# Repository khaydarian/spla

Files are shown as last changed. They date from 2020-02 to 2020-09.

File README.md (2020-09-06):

# SPLA: Super Nintendo PPU Logic Analyzer

The 1990-era Super Nintendo Entertainment System is a venerable gaming console,
and although its hardware is aging and hard to come by, it has long had
well-establish software emulators, preserving gaming history for generations to
come.

However, while most of the SNES hardware has been effectively
reverse-engineered by writing test programs for the CPU (sometimes taking
advantage of undocumented behavior to figure out details), one remaining
component of the console has resisted complete analysis: the "Picture
Processing Unit" chips, `PPU-1` and `PPU-2`.

The PPU chips are together responsible for managing the sprites, backgrounds,
and palettes for each frame of a game's video output, and produce the analog
scanline signal in realtime, which then appears on the
player's TV.  However, the output video signals (and video ram bus) are
entirely inaccessible to SNES CPU, thus making analysis of the exact timing
details of these chips difficult or impossible.

A very few games for the SNES (particularly *Air Strike Patrol*) use the SNES
video hardware in unexpected ways, which depend on the detailed timing of the
PPU chips during scanline rendering.  This makes accurately emulating these
games' graphics difficult -- emulator developers have to manually compare
emulator output with what the game actually shows on the screen, and try to
guess how the PPU evaluates these unusual configurations.  Without complete
understanding of the chips operation, this process degenerates into a
frustruating game of whack-a-mole.

To be confident that we have faithfully reproduced the entire SNES, we need to
characterize all the PPU outputs at the level of individual clock cycles, and
rigorously compare the behavior of a software emulator to that of the actual,
physical chips.

This project is intended to design a breakout circuit board, integrating the
SNES PPU chips from a real vintage SNES console, combined with surrounding
modern hardware, to effectively form a >100-pin-wide digital logic analyzer,
combined with single-frame analog video capture system.  With this board built,
and sufficient supporting software written, it should be possible to
experimentally characterize the entire operation of the PPU chips, thus
producing a completely cycle-accurate emulation of the SNES video hardware.

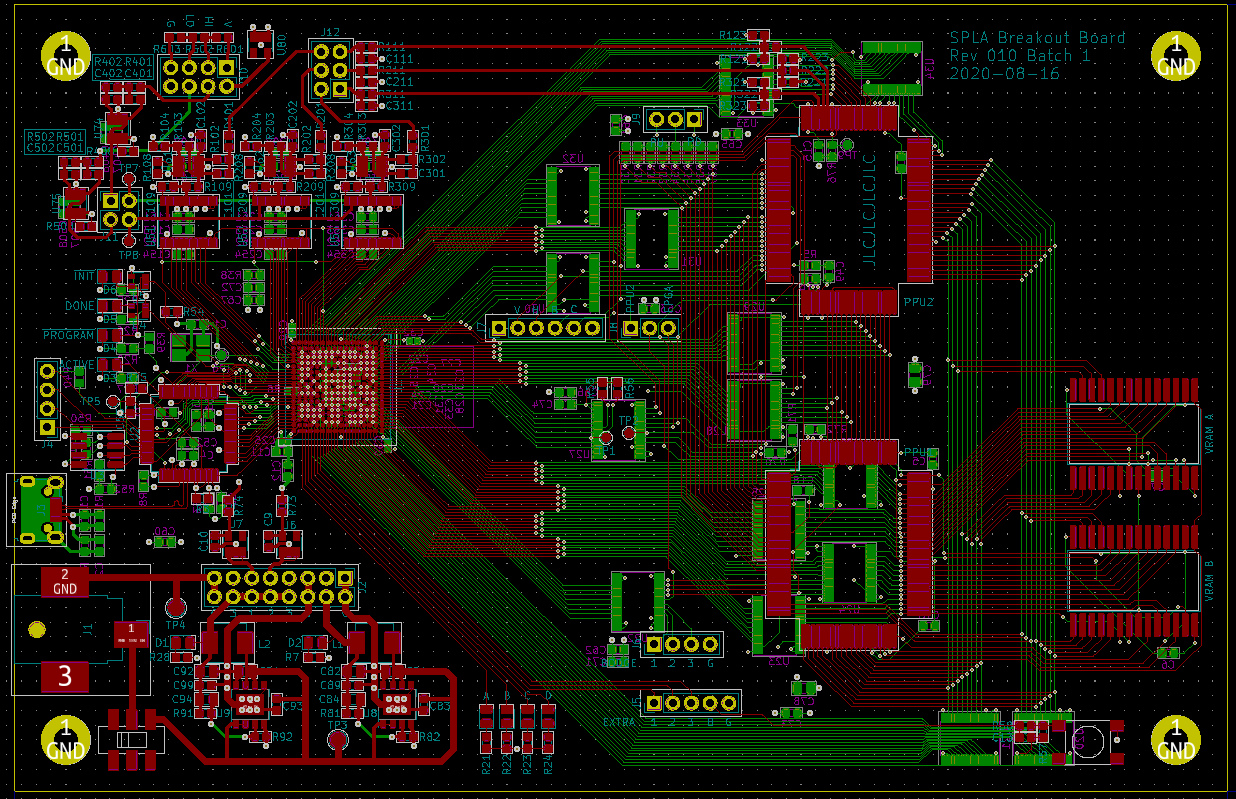
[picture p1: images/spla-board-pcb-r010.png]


## Current Status

* Design complete.
* Schematic complete.
* PCB layout complete.
* Schematic and PCB review complete (enough).
* Lab setup essentially complete.
* Bringup started.
  * Power bringup complete.
  * USB / FTDI bringup complete.
  * FPGA bringup complete.
  * Level shifter bringup complete.
  * SNES bringup complete.
  * Analog bringup pending.
* Software development in progress.
  * Early bringup and testing software complete.
* RTL development in progress.
  * All bringup images complete.
  * Low-speed driver image in progress.
  * High-speed driver image pending.

## Design components

* The USB interface to a host PC is based on an FTDI `FT2232H` chip, which can
  drive up to 60MBps (USB 2.0 "Full Speed" maximum throughput).
* A Lattice `ECP5` FPGA, which forms the central brains of the board.
* Both SNES `PPU` chips, and their corresponding video SRAM chips (which are
  standard 32KiB 8-bit SRAM chips, but are old enough that they're hard to
  source).
* A whole bunch of 3.3V / 5V level shifter chips (`74LVC8T245`), as the SNES
  chips are 5V TTL, but almost everything modern is 3.3V at most.
* Three `ADC1173` high-speed 8-bit analog-to-digital converter chips, to
  capture the analog RGB signal output and convert it back to digital for
  analysis. This also requires a handful (5) of `LMH6611` opamps to drive the
  ADC inputs and establish reliable references.

## References

* [Original post that inspired this project](https://byuu.org/articles/edge-of-emulation)
* [Ars Technica Article](https://arstechnica.com/gaming/2020/04/how-snes-emulators-got-a-few-pixels-from-complete-perfection/)

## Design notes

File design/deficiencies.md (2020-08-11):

# Design Deficiencies

This current design has a number of known (hopefully inconsequential) deficiencies:

## design: USB 2.0 Full Speed Bandwidth

USB 2.0 Full Speed is 480 megabaud, or 60 MiBps at line rate.  Some of this is absorbed by protcol overhead, so I can expect to sustain at most about 40 MiBps average.  The `FT2232H` in async fifo mode can in theory sustain this, depending on the host controller.  Based on some back-of-the-envelope calculations (too crude to repeat here), this is definitely not enough for full data-rate on all the pins, and perahps not even enough for full-frame-rate 24-bit color frames.

I can mitigate this with some clever compression and filtering, and it's probably possible to runthe SNES chips as lower than the rated 27.7727 MHz clock rate.

Another option is to graduate to USB 3.0 with a more complex (and expensive) chip.

I've length-matched the USB traces, but I'm not sure I've done so correctly.

## schematic: Ignored Pins

`PPU1.TST[012]` have unknown purpose, and aren't hooked up at all.

`PPU1.TST{12..15}` probably have more uses than just the 15-bit digital output, which I've ignored.

Most of the `74LVC8T245` level shifters don't have either their `OE` (output-enable) or `DIR` (direction) pins hooked up.  In most cases this doesn't matter, because the pins on the PPU / VRAM chips aren't bidirectional, and it's ok to be driving them all the time.  It's a bit clumsy though.

## schematic: Direction Control Granularity

Since the `74LVC8T245` can only control direction for all 8 channels at once, I've grouped the pins in the hopes that they'll have the same direction.  This is obviously ok for data and address buses, but there's lots of individual signals that I can't drive in separate directions.  Some groups of pins and explicitly one direction, which is a bit wasteful (but at least I only need the one kind of level shifter chip).

## schematic/pcb: Power layout

The power layout is perhaps entirely nonsense and I've no idea if it'll work.  I ought to prototype this on a separate PCB and find out -- perhaps even design one that fits into the power jumper bank I have now.

There's (small) ground loops in the power layout, whch is maybe bad. The PCB layout recommends a "guard trace" which I don't know how to do correctly.

_Note: Power layout definitely works (and in fact did so the first time, with zero issues)._

## schematic/pcb: Analog

The analog block is by far the least competently-developed part of the design.  The entire analog setup (ADCs + opamps) is based on my very limited understanding of analog electronics, so I might have done any number of things wrong and not realized so.  It's possibly fixable by replacing some passives with other values, but there's no guarantee.

The analog traces from the PPU2 outputs are pretty long (5-7cm), which could be problematic.  I don't have a good feel for whether this is so.

The analog power distribution is terrible; it's sourced from the 5V rail that goes all the way around the board, and it's just using a `TLV733` LDO.  This also might do a terrible job of noise rejection from the digital chips (which might come in through the ground plane anyways).  I've put it though a pin header, so in theory I can rework it if needed.

## schematic/pcb: Dodgy Decoupling

I don't know if I've added enough / the right decopling capacitors; I've mostly followed the reference recommendataions.  In particular I've avoided putting in bulk decoupling, because I'm not sure if it's necessary, given the large ground/power plane areas.  I can bodge this in later if needed, but perhaps I should put in a footprint for some big electrolytic capacitors.

Many of the level shifter chips don't have a good place to put decoupling capacitors.  I might have enough bulk decoupling on the board that this isn't a huge problem, and I can add in a few optional ones to help.

_Note: This is probably inconsequential; I've encountered no decoupling issues so far._

## pcb: PPU1 layout

The layout of the level shifters under the PPU1 chip is way tighter than necessary, and could be relaxed without causing issues.

## pcb: Power plane splits

The split between 5V and 3.3V sections of the power plan is ugly, because the level shifter chips are all over the place. Maybe this should be simplified, at the cost of some board space and increased trace stubs on the SNES buses.

## pcb: FPGA power

The power/ground fills have wide areas around vias (which is probably necessary), but this doesn't really leave enough space for all the 1.1V and 2.5V power to get in.  I've added traces for this, but they're often too small (0.2mm or 0.1mm), so I've added extra back-layer traces to supplement this.  This is really a side effect of having a four-layer board layout.

_Note: This is apparently inconsequential; I've encountered no FPGA power issues so far._

## pcb: FPGA Decoupling

The FPGA decoupling is considerably below spec for the 3.3V domain, because I can't fit all the capacitors in properly. This needs either reworking -- or a 6-layer board -- to avoid the extra bottom-layer power traces, which take up all the space for the capacitors pads.

_Note: This is apparently inconsequential; I've encountered no decoupling issues so far._

## pcb: Trace Lengths

Some of the traces are very long -- in particular, the VRAM data buses wrap all the way around the board. I'm not sure if this is a problem or not; the frequency shouldn't be too high.

_Note: This works ok at low speed (16 clocks at 12 MhZ, ~750kHz)._

## pcb: Trace Spacing

For the most part I've tried to avoid spacing traces at the minimum size: 3.5 mil, or slightly less than 0.1mm (I've set the limit at the latter).  There's a handful of places I'm stuck with it, and it's probably fine -- but those buses could couple together and cause signal integrity issues.  Probably that will only limit maximum speed, which shouldn't be a huge issue.  I'd expect that it's more likely to have a manufacturing error at the minimum size, and more capacitive coupling between traces.

_Note: No observed trace spacing issues.  One board (`b001`) had some dodgy solder mask._

## pcb: Trace Sizing Inconsistencies

Generally speaking, I've tried to use consistent sizes for traces:

* 0.1mm for 3.3V digital traces and FPGA connections.
* 0.2mm for clock lines.
* 0.2mm for 5V SNES lines.
* 0.4mm for analog lines, to lower resistence.
* 0.4mm or 0.6mm for power lines.
* 1.0mm for power source lines (12V mainly).

I've no idea if this makes sense, but I'm assuing that higher currents and higher voltages ought to have larger traces.

## pcb: Via Sizing Inconsistencies

* 0.4mm for analog areas.
* 0.4mm for power-related, with multiple vias in supposedly-high-current areas.
* 0.2mm for most everything else

I'm especially inconsistent about this.  Plausibly the power and ground vias should be 0.45mm across the whole board.

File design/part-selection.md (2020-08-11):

# Part Selection

Choosing parts is a nontrivally-diffcult task. This page documents why I've chosen the parts in the current design.

Generally speaking, I'm selecting for parts that I can most easily get working, and specifically not the cheapest available. I'm not planning to build more than a handful of boards, so having them be a few dollars more expensive is acceptable.

## USB Interface: `FT2232H`

I'm familiar with FTDI chips, so I didn't put a lot of effort into this choice. The `FT2232H` in particular has a synchronous FIFO mode which can reach the theoretical maximum throughput (60MBps), although other similar chips (`FT4232H`, in particular) don't have this mode.

If this isn't enough bandwidth, the `FT600` / `FT601` are comparable USB 3.0 chips, which have a 16-bit or 32-bit FIFO interface. However, they don't have as many GPIO pins, which I'm using to upload the FPGA image (rather than programming a SPI chip every time).

## FPGA: Lattice ECP5 `LFE5U-45F-6BG256`

First and foremost, I want to use the open-source FPGA toolchains (specifically yosys), which sharply limits the FPGA possibilities. The only supported ones I know of are the Lattice HX family (via Project IceStorm) and the Lattice `ECP5` family (via Project Trellis).

Almost all FPGAs come in BGA packages, which is tricky to hand-solder -- but there's no good way around that. I want the largest pitch, smallest package I thought I could get away with, given the number of IOs I need: ~190, counting both the SNES signals and the `FT2232H` connection.

The HX family is mostly small ball-pitch parts (0.35mm, 0.4mm, 0.5mm), which is probably infeasibly small to do by hand. The 0.8mm varieties are only the `HX8K`: 121-ball caBGA (9x9mm) with 95 IO, and 256-ball 16x16 caBGA with 208 IO. 95 IOs isn't likely enough, leaving only the `HX8K` caBGA-256. However, the `HX8K` only has 7680 logic cells, and 128Kbits of embedded ram, and 2 PLLs. This might be too cramped to get any clever logic involved, and there's very little space to buffer data.

THe `ECP5` family, in 0.8mm ball pitch, has 256-, 381-, 554-, and 756-ball parts. (They don't have any with SERDES block in this size, but I don't need them.)  Sticking with 256-ball (197 IOs), I can get:

* `LFE5U-12`: 12K LUTs, 32x 18Kbits block ram, 576 Kbits embedded ram, 97 Kbits distributed ram
* `LFE5U-25`: 24K LUTs, 56x 18Kbits block ram, 1008 Kbits embedded ram, 194 Kbits distributed ram
* `LFE5U-45`: 44K LUTs, 108x 18Kbits block ram, 1944 Kbits embedded ram, 351 Kbits distributed ram

Choosing the biggest one here (to give myself as much headroom as possible), leaves the `LFE5U-45F-6BG256`.

## Power: `ST1S10`, `TLV733P`

I went through several iterations of power regulator layout, and settled on a suggestion of Nate's for the `ST1S10` for the 3.3V and 5V power domains, which both have the highest power requirements. A switching regulator is complicated (need a bunch of passives and an inductor), but fairly unavoidable, as simpler LDOs generally will dissspate too much heat on their own. For comparison, the actual SNES uses a single `17805` regulator to drop from 10V input to 5V supply -- and it gets hot enough to need a heatsink.  Switching regulators will have more noise, but can sustain a lot more current (multiple amps).

For the FPGA's 1.1V and 2.5V domains, I've picked a fairly simple LDO regulator, the `TLV733P`. This has fixed output (`TLV73311P` for 1.1V, `TLV73325P` for 2.5V), which is fine for my use. This only sustains ~300mA of current, which is probably enough. I've no idea if the thermal dissapation for the LDOs if a problem, but I've hedged against it by adding separate power pins.

I've also added a seperate `TLV73333P` for the analog block, as the ADC datasheet says not to use the same power domain as the digital chips. This might not be sufficient to isolate noise out of the circuit.

In retrospect it probably would be easier to buy a power regulator module to stack on top of the board, and not design it myself.  I don't know if I can easily get one with all the voltages I need, though (5V, 3.3V, 2.5V, 1.1V).

All of this I've set up so I can take the entire power setup out of circuit and run the board from a bench supply, if I have to.

## Level shifter: `74LVC8T245`

I'd originally tried the `TXS0108E`, but auto direction control could be problematic in several ways. Instead, I settled for the explicit direction control of the `74LVC8T245` -- although later on I ended up hard-wiring a lot of the direction control pins that I don't need. This isn't a very satisfying solution to interconverting 3.3V and 5V signals.

## ADC: `ADC1173`

The pixel clock for NTSC is ~5.38MHz (at least for the SNES), so I want at least a 15MHz sample rate to cover the interval. The output signal is only 5-bit, so I probably don't need more than 8-bit depth to recover the signal (and also ADCs get _enormously_ more expensive with higher bit depth). From some investigation, many high-speed ADC chips have a limited input signal range (max 2V, usually), so that's a limitation I'll just have to deal with. Searching Digikey for 8-bit dpeth, sampling rates between 15Msps and 30Msps (active, SMD, sort by price) drops to 15 parts, mostly variants of:

* `ADC1175`
* `ADC1173`
* `ADS9280`
* `MAX1192`
* Other chips that are faster / more expensive than necessary.

`MAX1192` is a strange dual input thing, which isn't useful to me since I need three inputs anyway, and bundling two together is possibly problematic. `ADC1175` is a faster (20Msps) and higher-power version of `ADC1173`, and has a bit less available stock.

I'd originally chosen the `ADS9280`, but I don't really need the other features it supports, and it's not very well stocked (~hundreds, rather than >10k), and it's twice as expensive as the `ADC1173`. As a nice bonus, the `ADC1173` datasheet has better application examples, including sample layouts driving the ADC with an op-amp.

Aside: There are video-capture chips, but they generally take analog composite input, and I don't want to deal with the artifacts and adding the `BA6592F` from the SNES on the board as well. I haven't looked into this very much.

## Opamp: `LMH6611`

Driving the ADC is tricky; most op-amps want a wide voltage range with negative supply. I found the `LMH6611` by accident in Kicad's part library, and it's a single-supply rail-to-rail-output opamp, with fast slew rate and high bandwidth (max 345MHz). This will probably work out ok. Also, the datasheet has good example applications, including (critically!) driving a single-ended ADC input. This happens to be using a slower ADC than mine, with a wide voltage input range, but it's a good example of how to set up an opamp in general.

I've also used the same opamp to drive and stabilize the input reference voltages, which might be overkill. At least I don't have to read an extra datasheet.

## Crystal oscillator: Fox Electronics `FOX924`

Arbitrary and cheap HCMOS osciallator.

## Passives

Resistors from Stackpole Electronics (arbitrary); Capacitors from Murata Electrons (arbitrary).  Mostly `0603` packages, which I can comfortably hand-solder; some `0402` capacitors for FPGA decoupling (spacing is tricky in the BGA).

Inductor is Vishay Dale `IHLP2020CZ` (arbitrary).

## LEDs

LEDs are all green, from Wuerth Electronik (cheap, and arbitrary).  All `0603` package.

## USB Micro-B Connector

Matches conveniently-available KiCad symbol, from Wuerth Electronik.

## 12V Barrel Jack

Matches conveniently-available KiCad symbol, from CUI Devices.

## Mechanical parts

All essentially arbitrary.

*   2.54mm Pin Headers (lots): single- and double-row, from Sullins Connector Solutions.
*   Jumpers, from Sullins Connector Solutions.
*   Standoff Hex Legs: from Wuerth Electronik.

### 12V Power Supply Brick

Arbitrary.  I'm mostly using my bench supply anyhow.

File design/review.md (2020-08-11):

# Notes from Design Review

On schematic / pcb revision 8:

## `LMH6611` Common Mode Voltage Range

@rrrabarbaro

The `LMH6611` claims to only support a input (common mode) voltage range up to
"1.8V max" &mdash; but it's not entirely clear if this is so -- the graphs on
page 21 appear to show a larger voltage range.  Possibly this is a problem, but
I can fix it by rescaling the various bias resistors to move the analog input
range around.

Status: Not sure if necessary.

## JLCPCB trace-to-via minimum

Kor

JLCPCB's capabilities say the track-to-via minimum is 5 mil, or 1.27mm.  The current layout has a few places that are just barely under the limit, which needs fixing.

Status: Fixed in some potentially-problematic places.  Boards were manufacturing without issue.

## 5V Power Plane

@rrrabarbaro

5V power plane attaches to the source right at a PPU, which might cause excessive ripple.  Move this away from the chips, and add decoupling capacitors.

Status: Fixed.

## Decoupling

@rrrabarbaro

Check Lattice's recommendations for decoupling capacitors on the FPGA, and add them.

Status: Fixed.

## Adjacent Pads

@rrrabarbaro

Avoid connecting adjacent pads by the long edges. historically this causes problems with etch traps, but that might not be important with modern processes.

Status: Fixed.

## ADC Clock

@rrrabarbaro

Generally for best performance the ADC clock needs to be very clean.  Driving this from the FPGA won't provide a very clean clock, re-driving for each ADC would be better.  Perhaps a star topology is ok.

Status: Probably skip; I don't need very great ADC performance.

## FPGA startup

Programming input pins ought to have a pull-up/pull-down resistors, in case the `FT2232H` sets the B bus to high impedence when A bus is in sync fifo mode.  The datasheet isn't specific about this detail.

There should be LEDs on the various important FPGA programming pins (`DONE`, `INIT`, `PROGRAM`);

Status: Done.  LEDs are still dodgy, because (I think) the FPGA pins can't drive enough current.

## `FT2232H` layout

Some of the layout around the `FT2232H` is odd because I originally had the `EP` footprint, with a large ground pad.  THis should be cleaned up.o

Also, the `+1V8` rail out to have a convenient test point, for bringup use.  Decoupling capacity (`C7`) should be near the source of this power (pin 49).

Status: Fixed.

## Ground loops

The 5V rail goes a long way around the edge of the board, but the ground return path is direct.  This might create a small magnetic field going through the middle of the board, which might be bad.

Status: Probably ignore, since I'm not sure if this is a real problem.

## Physical connectors

USB Micro adapter and 12V Barrel jack might not match reasonable actual parts; need to choose those parts and update the layout to match.

Status: These match exactly, thanks to KiCad symbols.

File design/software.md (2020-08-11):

# SPLA Software

Simple notes on the design of the host-side software.

* One CLI tool, `splat`, with sub-commands.
* By default, uses the single SPLA device identified by matching VID/PID/Serial.
  * Uses an arbitrary "freely available" VID/PID for libusb applications.
* Commands try to verify which FPGA image is on the board, and repogram if necessary.
  * _(This isn't done yet.)_

* Category: Low-level commands
  * `show_ftdi`: Show all connected FTDI devices, VID/PID/Serial.
  * `bringup_ftdi_set_serial`: Set serial number of the device explicitly.
  * `bringup_ftdi_led`: Toggles the GPIO with an LED on it.
  * `bringup_fpga_ctl`: Toggle one of the FPGA image programming pins directly.
  * `bringup_fpga_spi`: Run a raw SPI transaction during programming.
  * `bringup_fpga`: Program the FPGA image that toggles just D4/D6.
  * `bringup_boundary_scan`: Program the FPGA image that runs boundary scan.
  * `bringup_field_timing`: Program the FPGA image that enables the PPUs and measures HBLANK / VBLANK timing.
  * `fpga_program`: Program the FPGA with a given image.
  * `fpga_version`: Show FPGA version and format registers.
  * `read`: Read a single register value.
  * `write`: Write a single register value.
  * `xin_stop`: Stop XIN clock.
  * `xin_start`: Start XIN clock.
  * `xin_run_to`: Run XIN to a specific cycle, or HBLANK or VBLANK.
  * `xin_step`: Clock XIN an exact number of times.
  * `xin_read`: Show XIN counter register.
  * `read_pin`: Read one or more individual pins.
  * `write_pin`: Write one or more individual pins.
  * `write_vram`: Write data to the VRAM chips.
  * `read_vram`: Write data to the VRAM chips.

* Category: Normal commands
  * `diagnostic`: Run diagnostic to check that things work as expected.
  * `bbus_scan`: Scan the B-bus and output results.  Intended for register source tracing.
  * `run`: Run one or more JSON test vectors, producing output files.

* Category: Data manipulation (doesn't use the board)
  * `serial`: Show (pre-compiled) hardware configuration of this board serial.
  * `vector_check`: Check formatting of input test vector JSON.
  * `registers`: Show built-in register table.
  * `pintable`: Show built-in pin index table.
  * `output_to_image`: Convert a test vector output to a PNG(?) image.
  * `output_to_vcd`: Convert a test vector output to a VCD signal file.

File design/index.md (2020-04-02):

# Objective

Build a board that can push signals through the PPU1 and PPU2 chips, with
corresponding external VRAM chips, which can communicate with host software on
a PC and log the values of each of the data buses during every cycle of
operation, feeding the results back to the PC.

In more detail: Connect the two PPU chips and tap all the important pins,
sample the results with a high-speed FPGA and dump the results temporarily into
nearby ram, and later into the PC.  Traces might be very big.

Both PPU chips have ~100 pins in use, which is a lot.  We might need multiple
FPGAs running in lockstep to collect the data at full speed.  If we don't have
to run fast, this is way easier -- add a few hardware muxes and we can rotate
around the pins.

# Open Questions

*Not in this doc for now.*

# Closed Questions

* Do we need to go at full speed (~21MHz)? How fast do we need to go?  Do we have to drive at full speed (dynamic NMOS or something), or can we go slowly?
  * Probably we do need to run at full speed at least to start, but this is
    very achievable.  Collecting data at that rate is harder, though, so we
    might have to use USB superspeed, or stride and/or space out data
    retrievals, or else dump the whole data into an SRAM and upload slowly.

* Do we need direct write access to VRAM chips, or can we just use the PPU1 to do that?
  * Probably we don't, but we have to hook them up anyways -- doesn't cost any extra traces to do so.

* How many signals do we need?
  * 136 minimum, counting shared signals.

* Can we have the FPGA emulate the VRAM chips as well?
  * Maybe. The block ram is generally registered, so this will be at least one
    (core) clock cycle delayed.  The real SNES takes ~4-6 cycles for video
    access, so that might still be ok.  This also takes quite a lot of block ram
    which can make the FPGA more expensive.
  * It's possibly easier to take the VRAM chips from the actual board anyways.

* What's the format of the signals on R/G/B output lines?
  * Seems like 0V - 2.7V analog, which is too wide peak-to-peak for some ADC
    chips.  Still not fully characterized.

* Can I solder this myself, or does it need professional manufacturing?
  * Probably.  JLCPCB-SMT will do most of the tiny fiddly parts, and I can
    maybe (?) reflow a 0.8mm pitch BGA manually.  We'll see.

* What are the VRAM chips?  Can I buy them?
  * Bog-standard SRAM chips; 2x 32KB.  However, they're obsolete, so it might
    be hard to buy new ones that are compatible with the PPUs.

# Design Process

* Collect design-relevant information (data sheets, schematics, etc).
* Figure out bill-of-materials, tuning for something I can physically build.
* Write some proof-of-concept FPGA-styled verilog.
* Figure out what (physical) tools I need.
* Learn to solder properly.
* Figure out how to use kicad (schematics and PCBs).
* Find a source for PPU1/PPU2 chips (everything else is easy from digikey)
* Figure out a manufacturing test strategy (hard if you don't know what the chips do!)
* Find some test vectors that in principle ought to work.
* Manufacture:
  * Buy a whole bunch of stuff.
  * Order boards and chips.
  * Solder everything together.
  * Test hardware construction (scan-chain-like).

# References

Original thread: https://byuu.org/articles/edge-of-emulation

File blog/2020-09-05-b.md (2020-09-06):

# 2020-09-05

Notes on games to get sample frames from:

* Super Mario World: it's familiar and easily accessible, and there's a few clever uses of the hardware (keyhole using HDMA).
* Air Strike Patrol: Uses timing-sensitive rendering in several scenes.  Notoriously hard to emulate properly.
* F1 game (which?): Has a mid-scanline rendering thing discovered recently.
* Uniracers: Uses mid-scanline writes to change sprite positions.
* Sonic the Hedgehog (SNES port): For memeability.

Also refer to various tests written by krom@: https://github.com/PeterLemon/SNES/tree/master/PPU

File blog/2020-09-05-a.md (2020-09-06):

# 2020-09-05

# Board `b003` Manufacturing Testing.

In lieu of making a decision on the sockets, I've just soldered the `PPU1` and `PPU2` chips directly onto board B003.

Running `bringup_ppu` makes the chips drive the VBLANK and HBLANK signals in a pretty reasonable fashion.  Success!  This is a major milestone; all the hardware appears to work as expected.

I'm currently using a 12MHz clock (directly from the FTDI) because I haven't worked out the PLL settings yet, but the chips appear to work fine with a slower clock (should be 21.47727MHz for correct NTSC output).
The scope measures the VBLANK signal of 33.5791Hz, and a HBLANK signal of 8.79793kHz.  This is almost exactly 1:262, which sounds reasonable: 262 scan lines per frame.  Officiall NTSC is supposed to have 262.5 lines per field for interlacing, but I'm not sure of the timing details for the SNES.  Exact measurements are better done by the FPGA anyhow.

Interestingly, the HBLANK and VBLANK signals seem to be offset by four master clock cycles (HBLANK switches four cycles after VBLANK).  This might be an interesting discovery, or an artifact of my setup.  It's possible

One concern is the amount of bounce of the HBLANK signal:  The PPU slams the signal down, and it rings really badly for some time (~4-10 master clock cycles).  The second peak is pretty high, maybe high enough to trigger some metastability issues in the FPGA.  I'll need to be careful with that, or else add a filter (somehow).  No clue what the other signals look like yet, but making great progress.

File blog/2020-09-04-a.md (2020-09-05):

# 2020-09-04

# Board `b003` Manufacturing Testing (continued).

I'm now almost ready to get the PPU chips on the board.

THe PPU chips don't have perfectly clean leads; they've got some remaining solder left on, and a bit of flux (which I mostly cleaned off, but not entirely).

The socket have alignment pins, and mechanical solder joints to make it more ridigly attached -- neither of which I'd planned for, and don't have on the board.  Plausibly, the 100 soldered sping pins will be enough to hold the socket in place, but if not, I can maybe super-glue the corners in place.

I think the plastic used for the sockets is high-temperature, but I don't want to risk melting them with the hot air station.  So, probably wiser to use the soldering iron, painstakingly.  This is still tricky because the pins on the ends of each side (near the corners) are very close to the plastic casing, and it'll be hard to get the soldering iron in there.

Another thing to consider is whether I should try using solder paste or solder wire.  I can't get the stencil on anymore (since the other parts will prevent it from lying flat), so I'd have to do it manually, which has been problematic in the past.  I could add a bunch of flux gel, which ought to help avoid bridges, but it's probably too hard to get the amount of paste correct.

Should I solder the socket one with a chip in it, and the springs compressed, or not?  Hard to say.  Most likely the typical manufacturing sequence assumes that the socket is empty for reflow.

*   Put a PPU chip in a loose socket, and test connectivity of all 100 pins.  Probably I don't need to test both chips.
*   Place the socket on the board, and tape down with kapton tape.
*   Tack down one pin on each side near the middle (easy to reach) to keep it in place.
*   Solder all pins one at a time with solder iron.  Use plenty of flux gel.
*   Test for mechanical stability (carefully).  If insufficient, superglue in place (and hope to never need to remove the socket).
*   Test for connectivity and bridges from pads to spring pins, individually
*   Repeat `bringup_boundary --levelshifter1` and `bringup_boundary --levelshifter2` with tapping spring pins.

## Loose socket testing

This was unsuccessful: Many of the pins don't make electrical connection to the corresponding spring pin.  This could be just that the socket needs to have the lid closed to make proper contact (which then makes it impossible to test, as the lid covers the leads), or that the PPU pins are to corroded or dirty (with older solder + flux) to make a good contact.

However, I suspect that the actual reason is that the the plastic packaging on the PPU chip is too thick (2.72mm +/- 0.1mm) for what the socket's designed for.  When pressed on manually, the spring pins bend downwards towards the chip body, but not at all when I put a PPU chip in place.  I'd expect at least that closing the lid would compress the chip leads against the socket's spring pins, but the spring pins don't seem to be under any pressure, and the corner clamps don't fit all the way down.  Suspicious.

According to the datasheet, this specific socket is `IC149-100-005-B5`, which supports a QFP-100 IC with a total height (bottom of leads to top of plastic) of 2.90mm, and I've measured the SNES PPU chips at 2.85mm - 3.00mm (it's hard to measure with the leads being a bit flexible.  The next step up, `IC149-100-014-B5`, support up to 3.5mm.

## Conclusions

This whole thing is ambiguous enough that I don't want to risk wrecking the chips or sockets.  So, for now, I'll defer the sockets to a later board build, and just hard-solder these chips on B003.  The real value of the sockets is in testing scavanged chips which might or might not work, and testing them without needing to build a board and solder them down.

However, for the first board, having reliable solder connections is more valuable, especially since I don't know for sure how the chips work (from a digital perspective).

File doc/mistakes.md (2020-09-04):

# Mistakes

## Separating Breakaway Headers is a Ballistic Hazard

Breakaway headers breakaway quite vigorously; I've probably lost some pins and
bits of plastic somewhere. Two-wide headers are even harder to separate, and I
keep busting a pair of pins trying. Fortunately they're cheap.

## FTDI Chip Layout was Bogus

I didn't fully understand what I was doing at the time, so there's some annoying limitations in the FTDI chip layout:

* The USB shield should not be grounded; this makes the host PC unable to recognize the USB device. I can workaround by severing the shield on a cable, but that's super dodgy.

* `INIT` LED has an accidental voltage divider, because I set up the LED the wrong way around (it's normally high, pulled low when needed).

* Lots of pads are inconvenient to sample with the scope.

## "Progressive Bringup" is a Stupid Idea

The whole idea I had here was to solder on parts of the board one step at a time, testing as I go. This is reasonable from an amateur perspective, but problematic in practice with small-pitch parts. In particular:

## Hand-soldering 0.5mm Pin Pitch Parts is Really Hard

0.5mm pin pitch is small enough that you can't (quite) fit soldermask in between the pins. This makes them prone to briding, and the pins are small enough that it's hard to clear the bridges.

It's hard to get the right amount of solder paste on the board without a stencil -- and with a stencil, you pretty much have to install and solder the entire board at once.

## Vaporized Isoproypl Alcohol Sets Off Smoke Detectors Instantly

Yeah, so that happened: I need to wait for the board to cool before trying to clean up flux residue. Flash-boiling isopropyl sets off the smoke detectors, which then set off the dog. Derp.

## Respect the Datasheet Maximums

The ECP5 datasheet says that the maximum supported I/O volatage is 3.3V, and they mean it: while running `bringup_boundary`, I shorted the 3.3V driver pin with the 5V supply, and instantly fried the FPGA.  Oops.

## Respect the Datasheet Maximums, Part 2

Temperature also matters: on the second board, I foolishly left power on while trying to reflow the FPGA to fix a disconnected pin -- which is well above the maximum operating temperature.  Oops.  This seems to have fried the I/O drivers in some bizarre fashion.  I can still program the FPGA, but is has strange behavior and definitely isn't working right.

## Don't Double-Drive Nets

Nominally, double-driving a net is "bad", but in a fairly ill-defined fashion.  In my case, I didn't damage any of the chips, but it wastes a ton of power, and the resulting heating can damage the chips.  This normally wasn't enough to be a problem, but when I tried experimentally double-driving all the VRAM address pins (to confirm that that was the issue), power usage jumped from 1.5W to 11W, and the chip temperature went from 30C to 85C in three seconds -- and then I shut everything off.

## Timing Constraints Matter

I was getting all kinds of weird data problems when trying to drive the VRAM chips for the first time.  However, there's some setup-and-hold timing constraints that I hadn't considered, so just driving the control and data signals at the same time caused weird and nondeterministic results.

## Check for dumb typo errors

While getting `bringup_vram` working (after the above issues), I had a strange problem where reading `VDA` and `VDB` would always result in `0` for `VDA, and `VDA`'s value in `VDB`.  I'd first thought this was a byte getting inserted into the UART by a glitch in the RTL, and reworked the protocol to avoid sending two bytes at a time, which didn't fix it.  I then scrubbed the code for places where I might has swapped A and B, and there weren't any. After some painful hours, I tried sticking in an extra `reset()` call, and now the A and B values appeared in the right slots -- but there was an extra pair of zeros on the first call.  This looked for all the world like my A and B data was delayed by a clock, but that's not reasonable, since the second reads are a few hundred clocks later (latency of the UART).

Finally I belatedly noticed that my `reset()` method wasn't using `OPCODE_RESET`, but instead `OPCODE_ECHO`, which returns an extra byte, throwing off the protocol.  Facepalm.

## Measure The Chips

Once I'd gotten far enough through bringup to solder the PPU chips on the board, I discovered that I'd gotten the footprint wrong, and they don't fit.

Turns out the PPU chips have 0.65mm pin pitch, not 0.635mm (ie, 40 pins per inch), which makes sense because Nintendo is Japanese and of course uses metric.  Duh.

This is a deeply annoying mistake, and probably the worst on this list: It's a classic dumb mistake, which I knew about, and measured at least four times, and *still* got it wrong.  I even printed out a paper PCB layout to verify the footprints, but somehow didn't think to desolder the PPU chips and check them specifically, even though they're the most likely chip to get the footprint wrong, and it's obviously wrong at casual inspection.

## Enabling FTDI Synchronous FIFO Mode is Tricky

There's some curious asymmetry in the FTDI mode configuration: Some modes are set by software using `ftdi_set_bitmode`, but some are the power-on defaults configured by the attached EEPROM.  In the most-obvious configuration the "reset" mode is UART, and everything else I'd used (bitbang, mpsse, etc) works as expected.  However, the synchronous FIFO mode (ie, the highest-throughput one, and the one I wanted to use) needs the default mode to be set to _asynchronous fifo mode_, not UART mode -- and there' no obvious error if you try; it just doesn't drive the 60MHz clock like it ought to (but confusingly does drive the `RXF#` and `TXE#` signals).

Since the only way to change this mode is to rewrite the EEPROM and reset the FTDI chip (and there's no way to reset it via software, so needs a power-cycle), I had to add some checking to make sure the EEPROM is in the right mode, and error out otherwise. This means you can't use both UART and FIFO modes interchangeably via software; it requires physical intervention to swap -- an unfortunate limitations of the FTDI chip.

## Don't set USB Vendor ID / Product ID to Zero

While writing the above eeprom-mode-changing tool (`ftdi_default_mode`), I accidentally set the USB vendor id and product id to zero -- which apparently `libftdi` can't deal with at all, since it re-uses those values to mean "the default FTDI ids".  I had to hack libftdi to get it to attach to the semi-dead device, and reprogram the EEPROM back to a sensible state.

## `FIFO_SIWU` is still on the wrong pin.

I didn't notice that the `FT2232H` datasheet table for "synchronous fifo" mode has all the pins in order _except_ `SIWU`, so I put it on the wrong pin.  Fortunately, it's sorta optional, and I wired it to an unused pin, so I can jumper over if I need to.  Annoying, though, since I didn't noticed until after shipping out the second board revision (`r010`).

## Wrong Pinout for Push Button

The button I added at the last minute is hardwired to connect pins 1 and 2, and to separately connect pins 3 and 4.  Pressing the button shorts the `1-2` net with the `3-4` net.  This is fine, except that the symbol I picked in KiCad has two pins, and shorts pin `1` with pin `2` -- which doesn't match the actual button.  To fix this I had to clip the lead for pin 2 (disconnecting it from +3v3), and shorting that pad across to pad `3`.

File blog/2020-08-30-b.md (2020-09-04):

# 2020-08-30

# Board `b003` Manufacturing Testing (continued).

1.  Power Validation: Done.
1.  FTDI Bringup: Done.
1.  FPGA Bringup.
    1.  Run `splat bringup_boundary`, and verify connectivity of the FPGA pins.
        1.  All pins nominal (astonishingly).
1.  Level Shifter Bringup.
    1.  Run `splat bringup_boundary --levelshifter1`, and verify connectivity of the FPGA input-only and input-capable pins.
        1.  `BODGE3` seems to be broken -- not showing on output-side of U22.
            1.  _Duh, turn the power on first._
        1.  All pins nominal.
    1.  Run `splat bringup_boundary --levelshifter2`, and verify the FPGA output-only pins via oscilloscope.
        1.  All pins nominal.

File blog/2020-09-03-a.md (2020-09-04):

# 2020-09-03

# Board `b003` Manufacturing Testing (continued).

1.  SNES VRAM Bringup
    1.  Solder VRAM chips on the board.
    1.  Run `splat bringup_vram`.
        1.   One bit error with address `0x2000` on A chip, bit `VAA13`.
        1.   Signal looks ok on SRAM pin and pad, sometimes.
        1.   Forceful probing on the levelshifter pin makes this work -- just a cold solder joint?
        1.   Yep, fixed.
    1.  Run `splat bringup_vram --random`.  Pass.

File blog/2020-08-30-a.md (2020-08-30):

# 2020-08-30

# Board `b003` Manufacturing Testing (continued).

1.  Power Validation: Done.
1.  FTDI Bringup.
    1.  12MHz clock input, on test pad: Nominal.
    1.  12MHz clock input, on ftdi pin 2: Nominal.
    1.  USB connectivity: Nothing.
        1.  Clock shows up ok.
        1.  Reset is high, as expected.
        1.  Check for adjacent bridged pins:
        1.  Just reflow the whole chip with generous amounts of flux.
            1.  Set off smoke detector; Dog panicks; bump the chip off the pads badly.
            1.  Take a break for a bit.

Aside: Button pinout is wrong; pins are backwards from datasheet.  Oops.

1.  FTDI Bringup (again).
    1.  USB connectivity: Works!
    1.  Run `splat bringup_first`.  `ACTIVE` LED flashes.
    1.  Run `splat ftdi_new_device --write --serial "SPLA_r010_b003"
        1.  Power cycle the board.
        1.  Verify USB connectivity with correct vendor/product idn:e
    1.  Run `splat bringup_ftdi`.  Mostly ok, but sometimes complains about A-bu pins being all stuck high.  Not sure.
    1.  Run `splat bringup_fifo` to verify ADBUS fifo pins.  Nominal.
        1.  _Note: I need to add an explicit pass/fail here, which also handles the exceptions for the FPGA pins (which otherwise report as "broken")._
    1.  FTDI bringup complete.
1.  FPGA Bringup.
    1.  Run `splat bringup_fpga`.  `LED_A` / `LED_B` flash.  Pass.
    1.  Run `splat bringup_fifo`.  Pass.

Oops, forgot to fixup `default.lpf`.  Need to do that before I can go further.

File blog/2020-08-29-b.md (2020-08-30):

# 2020-08-29

# Board `b003` Manufacturing Testing.

1.  Power Validation
    1.  Power LEDs are lit.
    1.  3.3V regulator measured at 3.238V (-1.8%).  Nominal.
    1.  5.0V regulator measured at 4.92V (-1.6%).  Nominal.
    1.  Enabled 1.1V and 2.5V.  Board power 20mA / 0.239W.
    1.  1.1V LDO measured at 1.099V; 2.5V LDO measured at 2.503V.  Nominal.
1.  FTDI Bringup.
    1.  Check for power/ground faults.
        1.  Ground to 3.3V: 9.36kohm.
        1.  Ground to 5.0V: 0.768kohm.  Odd.
        1.  3.3v to 5.0V: 9.35kohm.
    1.  Enabled 3.3V.  Board power 50mA / 0.600W.
        1.  _Oddity: `ACTIVE` light came on._
    1.  Verified 12MHz clock input.  Nominal.
    1.  Measured FTDI 1.8V LDO at 0.004V.  Broken.
        1.  _Also, the `ACTIVE` light flickered, so that's wrong too._
        1.  _Ok, that's a problem.  Most likely cause is that the FTDI chip isn't properly soldered down, and power isn't getting in all the right places._
        1.  Probing with scope reveals that it's a dodgy solder joing on FTDI pin 49 `VREOUT`.  Pressing down on it causes the 1.8V to appear.  Fixed with soldering iron.
        1.  Re-measured at 1.856V.  Nominal.

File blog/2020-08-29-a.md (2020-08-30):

# 2020-08-29

Assembled the first of the new boards today (revision `010`), with a variety of new techniques:

The big change for this assembly was to use a solder paste stencil, and assemble the entire board at once.  This _mostly_ worked out ok, except that the back-side components make it hard to apply the solder paste on the front side, since I couldn't get the stencil to lay flat properly.  The outcome of this is that the back-side 0.5mm chips were no sweat (except for one that was misplaced and needed some judicious fiddling), but the FTDI and ADC chips were a huge pain, since there was too much solder paste and everything bridged.  I eventually tore the FTDI chip off the board, failed to clean it up, and just tossed it and got another one.  I haven't tested this yet, but at least it doesn't look _obviously_ wrong.

I did assemble the analog block this time, but I'm not going to try to get it working any time soon.  We'll see if that ends up mattering.

For this version I opted for lead-free solder paste, which I find that I like quite a bit more -- I've heard that people find it annoying because it doesn't wet as well, and takes higher termperatures, but that didn't seem to be a problem for me.  (It's very possible that my "leaded" solder is actually a cheap fake, and is bascially poor-quality lead-free.  Dunno yet.  I could check the melting temperature, were I so inclined.)  Oddly, I had no trouble getting shiny solder joints with lead-free, which is exactly the opposite of what I'd been led to believe (ie, that lead-free is a real pain to do, and the joints won't be shiny).

I also (re) discovered that I *still* have some capacitors whose packages don't match their footprints -- `0402` on a `0603` footprint.  This isn't problematic to work with, but it's irksome.

The stencil does have openings for the BGA pads, which might add more solder to them than is really necessary.  I did miss five pads, since the solder paste got stuck in the stencil.  We'll see if those did get connected properly or not.

I'd reworked the manufacturing helper script for the new boards, and immediately discovered that I'd got it wrong: It's more important to separate components by side-of-board, then value / package, then board region.  As is, I ended up jumping around and scattering component bags all over.  Lessons learned for next time.

Now, on to testing (and fixing the inevitable manufacturing errors).

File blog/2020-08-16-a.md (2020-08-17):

# 2020-08-16

I've ordered new boards and parts, with the two major mistakes fixed:

* The SNES PPU layout is now 0.65mm pin pitch, and lines up with actual chips now.  Honestly, this is the only thing I actually _had_ to change, and the rest of this is just conveniences.
* I've un-grounded the USB shield pin, which was the proximate cause of the boards not enumerating on the USB bus.  No idea why this was happening, still.

Many other minor changes, mostly from TODO:

* Added another two general-purpose LEDs to the FPGA.  The pins for this I got from consolidating the ADC output-enable lines (since I don't need separate ones).  I also renamed the LEDS to `A`, `B`, `C`, `D`, since it's weird having `D7` and `D8`.
* Pinswapped the entire FPGA to move the test points to the south end of the board.
* Added a test point and 0-ohm resistor to the FTDI 1.8V regulator, since I had trouble with this before.
* Add a pair of buffer chips to the `INIT` and `DONE` pins, since the FPGA can't drive hardly any current to them and the voltage collapses.  These are easy to bypass, if I've misdiagnosed the issue.  I've also inverted the sense of `INIT`, since it's "active-low": "low" is "lit LED".  This may or may not be confusing.
* Added a generic button (pulled down, press to pull up), with a 1ms RC debounce.  This might be useful to trigger the FPGA to do stuff; I don't have specific plans yet.  This is normally disconnected, but jumperable to `EXTRA3`.
* Removed the 1.1V/2.5V jumper pins, because they're too close the FPGA and I keep melting the plastic.  I've never really needed them anyways; I can cut off power via the main jumper bank, and the LDOs are pretty solid anyhow.
* Cleaned up the silkscreen in places where I'd placed the references badly.
* Removed the electrolytic capacitors, which are almost certainly unnecessary.  The upstream power supply has some anyhow, and that's enough.
* Compacted the board slightly (left side pulled in by 13mm).  I'd like to waste less space, but it's not really worth the cost savings.
* Added a discrete power switch.  I've belatedly noticed that this part is rated for 6V, but I'll be putting 12V through it.  This might be fine, but if not, I can leave it out and bodge a wire across the pads.
* Corrected FTDI `REF` resistor to be 12k&#x2126; 1%, rather than 12k&#x2126; 5%.  Oops.
* Removed a bunch of 0&#x2126; resistors I don't expect to use (particularly in the power system).
* Added a test point to the 12MHz oscillator, which I'd wanted previously.
* Renumbered most of the components that have similar values to have similar reference numbers (ie, all 10k%#2126; resistors are sequential).  I think this might be convenient for manufacturing, but it spreads the numbers out all over the board, so I'm not sure.
* Seperated the `PPU1` `TST` 0&#x2126; resistors, in case I want to bodge them.
* Seperated the `PPU2` `AVCC` power input, in case I want to drive that separately for some reason.
* Changed USB cables to ~1m long ones, since the dinky 30cm ones are annoyingly short.
* Changed hex standoffs from 3.5cm to 2.0cm, which is more reasonable.

Also, on the manufacturing side, I've changed a few options:

* I've ordered boards with ENIG finishing this time, which is (hypothetically) easier for BGAs that require good surface planarity.  This probably won't be a big difference for me, but it's not very expensive.  If it saves me from even a single mis-soldered FPGA, it's made back the cost.
* I've also ordered stencils this time, and I'll try assembling the entire board at once.  This might be a bit tricky with parts on both sides, so I'll probably keep the preheater low (below the melting point of the solder) and do the back side first, where there's less parts to worry about.  Not sure if I'll do the analog section now, or leave it alone until I've gotten further in bringup.
* I'm switching to lead-free solder and solder paste, as an experiment: this might be disasterous, but it prevents me from worrying about lead cleanup.  If its too much trouble I can switch back to leaded easily enough.

While I'm waiting, I can still get some work done with the old `b001` board -- the FPGA is usable, even if I can't stick PPUs on it.

I'll still need to get a few more SNES's to cannabilize, though...

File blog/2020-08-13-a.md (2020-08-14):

# 2020-08-13

I think I've found the source of my math error:

The right way to measure pin pitch is by measuring from the side of one pin, to the same side of the farthest possible pin, which is what I did, and then divide the result by the number of pins, _not counting the last pin_.  This is probably what went wrong: even though I'd measured accurately (enough), I divided by 29 pins instead of 30.

This measurement (side-of-pin to side-of-pin) is 18.83mm on the long side (30 pins) and 12.52mm on the short side (20 pins).  If I do the math _wrong_, like I think I did before, I get:

* 18.83mm / 30 pins = 0.627mm per pin
* 12.52mm / 20 pins = 0.626mm per pin

Done correctly, this is:

* 18.83mm / 29 pins = 0.649mm per pin
* 12.52mm / 19 pins = 0.658mm per pin

The perfectly correct measurements would be:

* 0.65mm per pin * 29 pins = 18.85mm
* 0.65mm per pin * 19 pins = 12.35mm

Which is easily within the margin of error.  The same calculation done incorrectly would be:

* 0.635mm per pin * 29 pins = 18.415mm
* 0.635mm per pin * 19 pins = 12.069mm

Being 0.4mm off just about fits with the mismatch on the board, and it would have been obvious in retrospect, had I noticed at the time.  Instead, I assumed that the SNES chips would be using the same measurement system as the SRAM chips, which demonstrably are 1.27mm pin pitch (ie, 20 pins per inch) -- which would make 0.635mm (40 pins per inch) tantalizingly plausible.  Sigh.

So let's reverify some measurement, now that I have decent calipers.

SNES board footprint dimensions:

* Short side (20 pin)
  * Outer edge land-to-land distance: 20mm
  * Inner edge land-to-land distance: 16mm
  * Land length: 2.0mm
* Long side (30 pin)
  * Outer edge land-to-land distance: 26mm
  * Inner edge land-to-land distance: 22mm
  * Land length: 2.0mm

Measuring the chip itself:

* Short side (20 pin)
  * Outer edge pins: 18.82mm
  * Plastic: 13.72mm (~14mm)
* Long side (30 pin)
  * Outer edge pins: 24.82mm
  * Plastic: 19.78mm (~20mm)

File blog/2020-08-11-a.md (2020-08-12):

# 2020-08-11

Calamity!  Turns out that, despite measuring the the PPU pin pitch at *least* four times, I still got it wrong: the pins don't line up.  Seems like the PPU chips have 0.65mm pin pitch, rather thatn 0.635mm -- which makes sense, because Nintendo is Japanese and likely to prefer metric, where 0.635mm is 1/40th of an inch (25.4 / 40 == 0.635).  Obvious, in retrospect.

Also, I printed out the PCB on paper to check the component footprints, and everything checked out -- but for some reason I didn't desolder the PPU chips to check them, even though they're by far the most likely footprint to get wrong.

So I need to fix the board layout and get new ones manufactured.  Argh!  At least I can fix a bunch of other minor issues (like grounding the USB connector shield), and order a stencil.

ALso, while I'm at it, I'll probably end up swapping pins around, to move `J4` farther away from the FPGA (since I keep melting it), and moving the test points to an actual pin header somewhere near J3.  This introduces some complication, because I'll have a different `.lpf` constraint file for different boards.  Not sure how to deal with this yet.

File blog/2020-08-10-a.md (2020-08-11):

# 2020-08-10

Bringup for the VRAM chips is (finally) complete: Both SRAM chips are on the board, and I can drive both (in the most trivial fashion) from the FPGA.  This did take about a week or so longer than I'd expected, due to making a number of silly errors (listed in `mistakes.md`).  I haven't investigated timing of the SRAM chips yet, but that's not actually all that interesting, unless I want to pre-fill the chips as fasst as possible.  Right now the (not-well-optimized) read/write cycle takes 64 clocks at 12MHz: 5.33us.  This is way faster than the 115200-baud UART can get data into the chip (86us), so it's fine for now.  Likely this can get down into the ~120 nanosecond range (as the datasheet indicates). I'm curious, however, how the PPUS handle the setup-and-hold timing constraints -- maybe they're using the master clock cleverly.

Next step is to solder the PPU chips on the board, and figure out how to drive them properly (but slowly).  I'm hoping the PPU chips are static logic (and therefore can handle being driven at aribtrarily low frequency), but if not, things get more complicated.

The first "real" FPGA image should support this single-step operation, with some handy features to run the clock forward to "interesting" points (`VBLANK`, `HBLANK`, etc).  I can plausibly upgrade this into a "high-speed" image, which collects signals at full speed (~21.47727MHz), configued by a PLL, and ship the data off the the host PC faster than the PPUs can generate.  This isn't certain, though -- we're getting close to the "experimentation" phase (wherein I don't have a clear plan anymore).  Exciting!

Also, I still need to write some interface for the FTDI synchronous fifo mode -- although this is only necessary for high-speed interaction, and the UART is probably ok for now.  From an application perspective, it's just a bidirectional byte transport.

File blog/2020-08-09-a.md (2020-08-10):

# 2020-08-09

Lab notes: trying the "vram in steps" (`bringup_vram_steps`) approach.

States:

* 0: Address pins driven low, data bus pins floating.
* 1: Address pins driven high, data bus pins output high.
* 2: Data bus pins driven to known values (VDA = `0xa1`, VDB = `0xb2`).
* 3: Start write cycle by driving `VAWR_N = 0`, `VBWR_N` = 0`.
* 4: End write cycle by driving `VAWR_N = 1`, `VBWR_N` = 1`.
* 5: Turn around the data bus (from output to input).
* 6: Start read cycle by driving `VRD_N = 0`.

Pins sampled one a time (slowly!) via scope.

```
State     0  1  2  3  4  5  6
x10mA    10 10 10 10 10 11 10    |
1  VA14   0  1  1  1  ?  ?  1    |
2  VAA12  0  1  1  1  ?  ?  1    |
3  VAA7   0  1  1  1  ?  ?  1    |
4  VAA6   0  0! 0! 0  ?  ?  0    |
5  VAA5   0  1  1  1  ?  ?  1    |
6  VAA4   0  1  1  1  ?  ?  1    |
7  VAA3   0  1  1  1  ?  ?  1    |
8  VAA2   0  1  1  1  ?  ?  1    |
9  VAA1   0  1  1  1  ?  ?  1    |
10 VAA0   0  1  0! 0  ?  ?  0    |
11 VDA0   0  0! 1g 1  ?  ?  1    |
12 VDA1   0  1  0g 0  ?  ?  w0   |
13 VDA2   0  1  0g 0  ?  ?  w0   |
14 GND    w0 w0 w0 w0 ?  ?  w0   |

15 VDA3   0  1  0g 0  ?  ?  w0   |
16 VDA4   0  1  0g 0  ?  ?  w0   |
17 VDA5   0  1  1g 1  ?  ?  1    |
18 VDA6   0  1  0g 0  ?  ?  w0   |
19 VDA7   0  1  1g 1  ?  ?  1    |
20 GND    0  1  0  0  ?  ?  0    |
21 VAA10  0  1  1  1  ?  ?  1    |
22 VRD_N  1  1  1  1  ?  ?  0g   |
23 VAA11  0  1  1  1  ?  ?  1    |
24 VAA9   0  1  1  1  ?  ?  1    |
25 VAA8   0  1  1  1  ?  ?  1    |
26 VAA13  0  0! 0! 0! ?  ?  0!   |
27 VAWR_N 1  1  1  0  1g ?  1    |
28 VCC    1  1  1  1  ?  ?  1    |

1  VA14   0  1  1  1  ?  ?  1    |
2  VAB12  0  1  1  1  ?  ?  1    |
3  VAB7   0  1  1  1  ?  ?  1    |
4  VAB6   0  1  1  1  ?  ?  1    |
5  VAB5   0  1  1  1  ?  ?  1    |
6  VAB4   0  1  1  1  ?  ?  1    |
7  VAB3   0  1  1  1  ?  ?  1    |
8  VAB2   0  1  1  1  ?  ?  1    |
9  VAB1   0  1  1  1  ?  ?  1    |
10 VAB0   0  1  1  1  ?  ?  1    |
11 VDB0   0  1  0g 0  ?  ?  0g   |
12 VDB1   0  1  1g 1  ?  ?  1g   |
13 VDB2   0  1  0g 0  ?  ?  0g   |
14 GND    0  0  0  0  ?  ?  0    |

15 VDB3   0  1  0g 0  ?  ?  0g   |
16 VDB4   0  1  1g 1  ?  ?  1g   |
17 VDB5   0  1  1g 1  ?  ?  1g   |
18 VDB6   0  1  0g 0  ?  ?  0g   |
19 VDB7   0  1  1g 1  ?  ?  1g   |
20 GND    0  0  0  0  ?  ?  0    |
21 VAB10  0  1  1  1  ?  ?  1    |
22 VRD_N  1  1  1  1  ?  ?  0g   |
23 VAB11  0  1  1  1  ?  ?  1    |
24 VAB9   0  1  1  1  ?  ?  1    |
25 VAB8   0  1  1  1  ?  ?  1    |
26 VAB13  0  0! 0! 0! ?  ?  0!   |
27 VBWR_N 1  1  1  0  1g ?  1    |
28 VCC    1  1  1  1  ?  ?  1    |

[w0] pin was at ~8mV, which is strange.
```

Conclusions:

* A single write-read cycle appears to work.  Might be some floating stuff involved, but it's at least reasonably close.
* Several A-side pins have issues: `VAA6`, `VAA0`, `VAA13`.  Probably not soldered properly.
* A-side VRAM chip drives `0` signals as ~8mV, rather than actually 0V.  B-side VRAM chip doesn't do this, so something's up.  Might be just chip variation, or a shorted signal somewhere.
* If I'm coordinating the various control signals properly, then the power usage stays stable, like it ought to.

One of the original problems what that I was driving all the address / data / control signals on the same clock, which isn't valid -- there's likely some setup and hold timing that I'm violating, and this give unreliable data.  Also some of the pins are not connected properly, which messes things up.

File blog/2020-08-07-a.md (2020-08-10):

# 2020-08-07

No defines: 100ma / 1.2W / 30C
SCAN_READ: same
SCAN_WRITE: same
SCAN_BOTH:  same when *writing*, 180mA / 2.15W / 45C when *reading*

Something's wrong with the bidirectional IO driver setup.

Aha: I might have the pin direction backwards.  Looking at the techlib reference, I seems like I've read the truth table backwards.

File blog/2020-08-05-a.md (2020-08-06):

# 2020-08-05

So, a problem:  The current in-progress `bringup_vram` image 1) doesn't work, and 2) causes abnormally high power usage (~5W), which heats up the chip to unacceptable temperatures (>85C) way too fast (~60s).  Something is bizarrely wrong.

Also, the voltage reported is really low, which is surprising.

## Lab Notes

Idle (fpga reset): 140mA / 1.682W / 33C

Toggle states every 60s.
Always drive vram chip enables high (ie, vram chips don't drive data pins)

`bringup_vram_trivial`
* LED8 / input mode: 200mA / 2.4W / 43C
* LED7 / output mode: 90mA / 1.08W / 38C

`bringup_vram_trivial` with directions inverted
* LED8 / input mode: 90mA / 1.08W / 35C
* LED7 / output mode: HOLY SHIT 10W / ? / >80C quickly

always output, but toggle values
* LED8 / input mode: 90mA / 1.08W / 33C
* LED7 / output mode: 90ma / 1.08W / 33C

stable.  toggle values faster (every 3 sec)

Try toggling values quickly (100kHz).  Measured 100mA / 1.2W / 32C. Ok.

(Side note: scope was stuck in 1x mode, which explains the weirdly low signal levels.  Fixed now).

Signals appear fine, ish.  However, `VDA` / `VDB` signals don't appear, when I expect that they should.

Try explicit output pins for `VD[AB]` (ie, not using bidir pins).  Signals appear on VRAM chip pins, as they should.  Measured at: 100mA / 1.2W / 32C.

(Side note: found a dumb mistake in `clock_div.v`, now fixed).

Theory: the driving states of `bringup_vram` are wrong.  In any case, it shouldn't be possible (in the RTL) to drive the state incorrectly, ie, mismatched between FPGA pins / level shifters / VRAM chips.  Hopefully I can just fix that and all will be well.  I'm not convinced that my RTL for the bidirectional pins is correct.

Try driving reads: `VRD_N=0`, `LVL_VD_DIR=0`, `VDA` inputs.  Power usage nominal, but hard to tell because I don't know what data's in the chip at power-on (indeterminate, I expect).  Seems ok?

New plan: Build an image that explicitly runs through the address space writing, and the repeats with reading.

Hm, discovery: `cells_io.v` in the tech library has mappings for bidirectional `TRELLIS_IO` modules with various pull modes -- not sure that the default is "none".

So, `bringup_vram_scan` does the writing and reading scan, and compares values with the expected.  This *seems* to work, but I'm not very sure.

* Reading measurement: 180mA / 2.16W / 48C
* Writing measurement: 100ma / 1.2W / 35C

Weird that reading is power-expensive -- this implies that I've got something wrong with the drivers somehow.  I might need to experiment with the testpoints.

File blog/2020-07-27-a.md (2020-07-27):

# 2020-07-27

Finishing up level shifter bringup: Added an image to just drive a UART pattern on each of the output pins; there's only 16 output-only pins to worry about.  This works every every pin except `ppu1_hvcmode`, which seems to be a bad pin on chip U15: Sampling on the shoulders of the pins shows the signal going into the chip, but not coming out the other side.  Inconvenient.

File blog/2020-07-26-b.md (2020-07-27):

# 2020-07-26

With new `bringup_levelshifter1` tool, I can test all the level-shifted inputs (and bidirectional pins) with the same technique as before.  Initial results show that everything works, except:

* `vaa{5,7,9,10,12}`
* `ppu2_tst[1]`

These were all easy to fix with some judicious soldering iron touch-up.

I still need to test the outputs, which is more tricky -- possibly I can attach a `uart_tx` to each pin, with a different bit pattern to identify.

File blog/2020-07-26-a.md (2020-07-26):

# 2020-07-26

Level shifters are all installed now; using the same technique as the latest FTDI chip (which has the same pitch): pre-tin all the pads with solder and liquid flux, then use hot air at ~400C to reflow the pads.  This probably worked ok; all the pins looks fine and there's no obvious bridges.  I think the level shifters have slightly larger leads and a slight thinner package, so it's easier to see around them.

The previous technique for `bringup_boundary` doesn't work so well here, because many of the pins are single-directional (input or output), and I can't just set them all to input.  So, instead:

* Test that the `DIR` pins all work as expected, via scope.  Just drive them with a known square wave, and tap the pin on the chip with the scope.  This is painstaking and non-automatable, but should work fine.
* Set everything that can be an input as such, and drive a signal with `BODGE[123]` (which is 5V, instead of `EXTRA[123]` which is 3.3V).  Test in the same way as `bringup_boundary`.
* Set everything that can be an output as such, and drive some signal I can pick up on the scope.  I might be able to hook a test wire to the `J6` input signals, however, which might work better.

The most important part of this process is to not bridge the 3.3V and 5V rails, which will destroy the FPGA (again).

First fooling-around tests:

* Driving a 12MHz signal to `XIN` works, and comes through the level shifter without issues.  Sadly it's hard to measure at full speed, since I didn't include a ground pad nearby and the loop area is too big.
* `BODGE1` is connected on the 3.3V side, but not on 5V side (pin drives the 5V signal, but it doesn't show up on the header).  Darn.  `BODGE2` and `BODGE3` are fine, though.

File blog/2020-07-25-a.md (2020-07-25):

# 2020-07-25

Finally returning to this project, after work cooled down a bit.

First step is to replace the FPGA on `b002` with the extra I have.  I'm going to try out my new preheating plate while I'm at it.

The plastic on the pin headers is PBT, and datasheet says it can handle 245C for 3-5 seconds; max 105C for normal operation.  Since all the leaded solder melts at 183C, I'll have to leave it low anyway -- about 150C I think.  This is probably fine, but I'll have to protect the `J4` jumpers from melting anyhow (like they did on the first board).

In-the-moment notes:
* preheater 155C (bit high?)
* hot air 400C
* tiny dab of flux, while hot, melts immediately
* J4 got a little scorced, but not badly -- need two layers of kapton tape
* preheating plate takes a long time to heat and cool; probably best for doing several things in sequence
* Marked bad FPGA with "X" label, but retained the chip for practice.

Testing:
* `bringup_ftdi` shows a bridge between MOSI/MISO, which is weird because programming the FPGA still works.
* `bringup_fpga` flashes `D7`/`D8` as expected.
* `bringup_fifo` shows strange behavior: `FIFO_D0` is bridged with `D7`, and `D8` doesn't always flash when it should.  This isn't consistent, so it doesn't look like a bad connection:

```
$ make && ./splat --device board bringup_fifo
make: Nothing to be done for 'all'.
Read ID: 0x41112043 OK
Status 0x00000e00: ISC-Enable Write Read
0162708 / 0162708 bytes = 100.0%
Status 0x00200f00: DONE ISC-Enable Write Read Standard-Preamble
high 000-0000 low 00000001
high 000-0000 low 00000010
high 000-0000 low 00000101
high 000-0000 low 00001000
high 000-0000 low 00010000
high 000-0000 low 00100000
high 000-0000 low 01000000
high 000-0000 low 10000000
high 000-0001 low 00000000
high 000-0010 low 00000000
high 000-0100 low 00000000
high 000-1000 low 00000000
high 001-0000 low 00000000
high 010-0000 low 00000000
high 100-0000 low 00000000
high 000-0000 low 00000001
high 000-0000 low 00000011
high 000-0000 low 00000100
high 000-0000 low 00001001
high 000-0000 low 00010000
high 000-0000 low 00100001
high 000-0000 low 01000000
high 000-0000 low 10000001
high 000-0001 low 00000000
high 000-0010 low 00000001
high 000-0100 low 00000000
high 000-1000 low 00000001
high 001-0000 low 00000000
high 010-0000 low 00000001
high 100-0000 low 00000000
```

D0 isn't obviously shorted, but also is unusably broken.  Might try reflowing the chip again, but there's no guarantee this will work.

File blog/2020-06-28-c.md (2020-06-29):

# 2020-06-28

I'm still not sure about the weird can't-drive-low behavior of the second board's FPGA, but now it doesn't matter: I accidentally brushed the 5V rail with my signal wire, and the reverse voltage fried the chip.  The board is now absorbing 1.8W (150mA), even without the USB plugged, and 2.165W (180mA) with USB plugged in.  The chip is unresponsive to programming, and is strongly driving the D8 and `DONE` pins, which is definitly wrong.  Humourously, my error message reads: "Wrong Chip ID 0xffffffff: broken board?", which it definitely is.  Oops.

This is frusturating, not just because I've burned out a (somewhat) expensive FPGA, but also because I now can't debug the weird can't-drive-low behavior.  Sigh.

I still have one FPGA left, before I have to order more.  It's probably worth building a better script for ordering parts, though.

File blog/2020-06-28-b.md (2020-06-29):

# 2020-06-28

I belatedly figured out the `FIFO_WR_N` problem: The `FT2232H` doesn't have a "just-serial" mode; instead is has RS232 mode, which has a bunch of extra control signals.  Most of these don't matter, or only mildy disrupt the serial connection, but `FIFO_WR_N` is connected to `RXLED#`, which probably has a high-current driver enabled, which can easily overwhelm the FPGA's ability to drive that signal.  Duh.

So, I can't use `bringup_boundary` to test the FTDI connections.  Instead, I'll write a different image that just drives the pins high and low in some pattern, and read that pattern off the FTDI chip in MPSSE mode, similar to `bringup_ftdi`.  Call it `bringup_fifo` instead, I suppose.

I'm still not sure what's up with the second board, though -- probably I should try reflowing the FPGA and see if that helps.

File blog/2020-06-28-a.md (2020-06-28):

# 2020-06-28

New development: If I *just* load the `bringup_boundary` image, I can see the 100kHz driver signal on `TP9` -- but it disappears after a second or two.  I'd thought this was when the host software starts polling the FTDI UART output -- but even if I disable that (by returning immediately after loading the bitstream), it still disappears.  Probably this is something to do with the FTDI chip power settings somehow?  Or, I've got some short on the second board that isn't on the first one.

I don't know if all this is related to the `FFIO_WR_N` pin problems, but it might be.

Yes, this defintely doesn't happen on the first board.  There's still some hiccups on a ~1s cycle, but that seems to be a sampling artifact; the frequency changes when I rescale.  [SDS00022]

Possibilities:

* EEPROM configuration could be different (unlikely).
* Short with `PWREN` / `SUSPEND` pins.

I still don't know why the `bringup_boundary` scan still works even when the pin's shut off.  It starts back up when I connect things, but has a weird trapezoidal shape.  [SDS00023] The shape different when I'm sample the LEDs -- likely because they have non-trivial current draw. [SDS00024]  Connecting to `D3` doesn't cause this issue.

I might have a short on the 3.3V IO bank power somehow, or possibly on the core clock -- and it wakes up again because it can absorb enough power from the IO pin to start working again? very unlikely I think.

Check on the `PWREN` / `SUSPEND` pins by wiring them to the LEDs.  Looks like `PWREN_N` is low (ie, "power is enabled"), and `SUSPEND_N` is high (ie, "not suspended").  This doesn't change when the board crashes, so that

Slowing down the signal to 10 kHz means it doesn't even get all the way to 0V; just down to 2.54V.  [SDS00026]  Connecting to TP7 (or any pin) also does weird things. [SDS00027]  Slowing down to 1 kHz causes the same thing.

Theory: The nearby ground pins aren't connected, so when the pad driver transisitors connect the signal to ground, it doesn't actually drop to ground, and only drops slowly through parasitic leakage.  Core power is ok, so it keeps working -- but appears to stop, since the 100 kHz signal is too fast for any substantial drop to happen.  This doesn't explain why the chip is ok for a few seconds, and then collapses -- possibly there's an accidental RC circuit involved with the decoupling capacitors, and once they're drained the signal collapses.

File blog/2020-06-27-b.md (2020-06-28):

# 2020-06-27

There's something very suspicious about `FIFO_WR_N`: it's disconnected on both boards, which is flatly implausible.  Let's check some details:

* `FT2232H` Datasheet does say that pin 29 is the FIFO mode's `#WR` pin.
* Pin 29 (aka `ACBUS3`) is labelled as `FIFO_WR_N`.
* `FIFO_WR_N` is connected to `P12` on the FPGA.  This happens to also be `LRC_GPLLOC_IN`, but that's not remarkable; we can use it as a plain single-ended GPIO without issues.
* `P12` is listed in `default.lpf` as `fifo_wr_n`.
* In `bringup_boundary.v`, `fifo_wr_n` reports as `PINDEF_FIFO_WR_N`.
* In `lib/pindef.v`, `PINDEF_FIFO_WR_N` is 15, which isn't duplicated elsewhere.
* In `bringup_boundary.c`, `PINDEF_FIFO_WR_N` is used as expected.

This makes no sense.

If I hack `bringup_boundary.v` to drive `fifo_wr_n` in the same way as `tp9`, if *definitely* shows up on the scope -- but inconsistently at 2.8V instead of 3.3V.  That makes _even less sense_.  Looks like this drop in volatage happens a few times a second, for about 1ms. [SDS00021]

Even weirder, when I hook up the scope, I can't see the square wave on `TP9` -- but I _can_ on `FIFO_WR_N` on the FTDI chip.  Something terribly strange is going on.

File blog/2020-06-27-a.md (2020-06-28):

# 2020-06-27

Building the second board, starting with the FPGA first.

* Set up workspace.
* Tape thermocouple next to FPGA; I know this isn't very accurate, but that's probably ok.
* No bucket-of-kapton-tape this time, since I don't have other components to protect.
* Hot air station set to 475C (which I still think is too high).
* Unsealed second FGPA from the first package.  Humidity indicator seems to be ok (blue in all three circles, although 5% is a bit faint.  Not sure this is a Level 1 or Level 2 part).
* Added generous amount of flux, smoothed out a bit with toothpick.
* Preheat board and then ramp-up.

...

Too much flux!  Chip started floating away on a pool of flux, and I had to bump it around a bunch to try an keep in in place.  I wasn't sure if the chip had fully reflowed properly, because it was held up by a bunch of liquid and smoking flux. (Also my cat intruded, and threw off the process, so that might have been an issue).  I tried to get the chip in place, but I bumped it so badly that there were obvious bridges on the edge balls.

Taking the chip off went fine, but the solder balls are all stuck together -- that chip is probably unrecoverable without re-balling the BGA (which is more work than I care to do, and I don't have a stencil for it anyway).

Trying with another chip; less flux this time: just two dots in the middle of the BGA.  This seems to have worked much better; chip is well-aligned and no obvious edge bridges.  Moving on to the rest of the build.

...

Manufacturing glitch: I still have 10 10uF 0805 capactiors (digikey 490-10516-1-ND), which I should only have 8 (using 2 on the first board).  Not sure what went wrong, but it's probably the 0603 package version of the same size.  Need to check up on this via inventory.

I also rediscovered my getting the 1uF package wrong (should be 0603, but I bought 0402 -- oops).

## Board Manufacturing Tests

* Apply 12V power.  Verify that `L1` and `L2` light up.
* Measure 3.3V and 5.0V regulator output.
  * 5.0V measured at 4.946V (1.1% below nominal).
  * 3.3V measured at 3.221V (2.4% below nominal).
* Apply 3.3V power to 1.1V and 2.5V LDOs.
  * 1.1V measured at 1.102V (0.2% above nominal).
  * 2.5V measured at 2.506V (0.2% above nominal).
* Apply 3.3V power via jumper.
  * `DONE` and `INIT` LEDs come up, which is surprising.  FPGA doesn't have core power yet, but apparently IO power is enough to start?
* Apply 1.1V and 2.5V jumpers.
  * This causes `DONE` to go out.  Probably having all the power rails up make the FPGA work, and then it complains that it has no image.
* Attach (stock, non-severed-shield) USB cable.
  * No response.
* Attach severed-sheild cable.
  * Device comes up immediately.  Sigh.  Still don't know what up with that.
* `splat ftdi_list_devices`
  * Shows up correctly as new device.  _(I still need to fix that command to scan the right vendor ids, I think.)_
* `splat bringup_ftdi`
  * It's ok to have "L" on bit 20 ("DONE") and "K" on bit 22 ("PROGRAM_N") -- this is what `B001` has.
  * Pins broken:
    * Bit 24 `LED3` is stuck low; probably shorted to adjacent ground pin.
    * Bit 0 `FIFO_D` is stuck low; probably similar.

Fixing shorted pins using the same techinque as before: 30 gauge wire with flux, one pin at a time.

Interesting, if the FPGA isn't powered properly (1.1v and 2.5V), it does some crazy stuff with the IO pins.  Weird.

* `splat ftdi_new_device --write --serial SPLA_r009_b002`
  * Disconnect and reconnect.
  * Ok.

* `splat bringup_fpga`
  * LEDs flash as expected.

* Solder on an extra test pin to `TP9`.
  * Done.

* `splat bringup_boundary`
  * Scanned all pins with test wire.
  * `FIFO_WR_N` is still disconnected!  This seems like it might be a software glitch; it's really unlikely for two boards to have exactly the same single disconnected pin...

Picking this up tomorrow.

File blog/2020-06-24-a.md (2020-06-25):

# 2020-06-24

FPGA Bringup continues:  The last step is to verify that all of the FPGA pins are connected properly under the FPGA -- which in industry one might do with an x-ray machine that costs more than my house. Lacking such budget, I've come up with a different idea: set all the pins as inputs, and manually drive a ~100kHz signal into each connected net one at a time, and collect the results. This also has the advantage of simultaneously checking for bridges and for disconnected pins.

I'd originally planned to do this with some simple sketch on an Arduino, but that turns out to be more troublesome than I'd expected: most Arduino boards are 5V, not 3.3V, and the ECP5 isn't 5V-tolerant. Even if it weren't I could only easily get a wobbly ~70 kHz signal with the microcontroller there. There's some more complicated "high-speed PWM" stuff I could try, but then it's not simple anymore.

Instead, I can drive a 3.3V signal from one of the test points on the FPGA itself, which will work fine.

I can already confirm that some of the pins are already connected correctly:

* From being able to program any image at all: `PROGRAMN`, `INITN`, `SPI_CSB`, `SPI_CLK`, `SPI_MOSI`, `SPI_MISO`
* From early bringup images: `clk_12mhz`, `led7`, `led8`, `uart_tx` (aka `fifo_d[1]`), `tp7`, `tp8`, `tp9`

Building out the RTL (`brinup_boundary.v`) and matching `splat` command (`bringup_boundary`) was fairly straightforward. The driver is pretty trivial, and the sensor (one for each pin) just does some clock synchronization and debouncing and hysteresis, so we can detect the incoming signal reliably.

I'd wanted to do something clever with sending only changes down the UART, and backed off to just sending an entire 176-bit frame at 10Hz, which worked fine.

Curiously this image takes up some 36% of the LUTs in the FPGA, which sounds wrong since it's not that much functionality. In fairness it's probably not implemented efficiently, but it doesn't really have to be.

The `splat` command in turn just parses the frame, and shows which pins are currently "active" (ie, receiving the driver signal), and also keeps track of all the pins that it's seen active alone (ie, not bridged to two different signals).

Sampling this manually was a bit painful from a test point, so I soldered on a physical pin to attach to, and this made it quite a bit easier. Next board revision, I should have test pins instead of test points; I don't need to save space that badly.

Final outcome: Almost perfect. There's _exactly_ two problems:

* `analog_g[5]` is bridged with `analog_g[6]`. I can live with this, since I ought to be able to get digital color out from the PPU2 test pins.
* `fifo_wr_n` is not connected. This *might* be on the FTDI side, but I think it's not -- sampling on the pad itself is pretty touchy, but got no response to the FPGA either.

This latter problem is pretty sucky, because I can't use the fast (~40MBps) synchronous fifo mode on the FTDI chip without it. I can probably come up with something to extract data faster than the UART (~11KBps), but I won't be able to collect data with the SNES chips close to full speed. As mentioned earlier (ie months ago), there's several workaround for that, so it's not the end of the world -- but it's still sucky.

I _might_ be able to work around this by soldering a bodge wire from one of the test points to the `fifo_wr_n` pin on the FTDI chip, and remapping to suit.  This is pretty dodgy, though, and might have too much signal propagation delay to sustain 60 MHz. I could steal the pad for `D7`, instead, which is physcially closer.  Have to think about this a bit.

It's probably worth building a second board at this point (with various lessons learned so far), and see if I can get the FPGA perfectly connected. Fortunately I just got another batch of parts (particularly FTDI chips, since I messed up the first one a bit), so that's easy enough to get started on. I'll probably solder the FPGA on first, if only so I don't melt the secondary power pins again.

Next boards ought to use ENIG finishing, which makes getting the FPGA on easier (better planarity of the pads).

Aside: I'll have a related problem trying to test the level shifter chips, but worse since several of those are unidirectional. I haven't figured out how to deal with this yet.

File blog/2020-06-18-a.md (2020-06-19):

# 2020-06-18

FPGA bringup is (finally!) complete -- at least, in the sense that I've finally figured out what what going wrong the with the FPGA before.  I'd almost settled on "I overheated the FPGA and broke it".

The recommended way to use the Slave SPI configuration mode is to use Lattice's (not-easily-automateable) "Deployment Tool" to convert the bitstream into a pair of "algo" and "data" files, and pass those to the SSPIEmbedded code.  This is a big blob of embedded-style C code which parses some wacky opcode format -- but in exactly such a way that you can't learn anything from the code.  This is violently user-hostile, since there's no way to understand what's actually going on with the protocol the chip actually uses.  Purportedly Lattice does this to "insulate developers from the complexity", but I've my doubts -- it's a very effective way of obfuscating the actual operational details of the chip.  If Lattice was just trying to make things easier, then there's no reason to not document all the details (which notably, they did only barely).

So, just experimentally, I pasted the Lattic SSPIEmbedded code into my project, and hacked in the few bits to attach it to my SPI code.

And of course, it worked the first time.  A considerable amount of expletives followed.

There's some subtlety in the way the deployment tool sets up the "algo" stream, which drives some details of the SSPI protocol in ways I didn't expect.  Let's examine those briefly, with the help of a seperately-hacked copy of SSPIEmbedded that shows what it's expecting.

Curiously, some operations are only three bytes, despite the sysCONFIG datasheet specifying at least four bytes (8-bit opcode, 1-bit CRC flag, 23-bit argument).  Hacking this to always be four bytes also works; I presume that the Lattice developers just know that they don't always need all four bytes to make the operation happen.  Cheating a bit, I think.

Sequence of operations:
* Empty transaction.  No idea why this is here; possibly as an early check of the SPI backend.
* `[e0000000] READ_ID`: Read the chip id, `0x41112043` (ie, `LFE5U-45F`), which the algo verifies (since there's no portability between different chips.
* `[c6000000] ISC_ENABLE`: Enables the offline configuration mode.
* Wait for 1ms.  This isn't specified in the datasheet; I'm guessing that offline mode takes some cycles to engage.  I've sorta noticed this with `ISC_DISABLE`, which didn't always seem to happen immediately.
* `[3c000000] READ_STATUS`: Mask with some bits (`[00024040]`), and check that they're all zero.  Probably checking for errors. Returned value is `[00000e00]`.
* `[0e010000] ISC_ERASE`: Erase the configuration SRAM.  I'm not sure why the argument is set to `0x010000`; this isn't mentioned in the datasheet.
* Wait for 200ms, so the erase can complete.
* `[46000000] LSC_INIT_ADDRESS`: Set the address register to zero.  I don't know why this is necessary, given that `ISC_BITSTREAM_BURST` just programs the entire bitstream at once.
* `[7a000000] ISC_BITSTREAM_BURST`: Program the entire bitstream.  Followed by 1032325 bytes of bitstream data, which is a strange number because it doesn't match the raw frames size: 9470 * 109 bytes per frame == 1032230 bytes, which is 95 bytes too many, but too few to add data per frame, or for the bits-per-frame padding.  I'm not sure how the Lattice Deployment Tool has fiddled with the bitstream here.
* Wait for 10ms. Not sure why.
* `[3c000000] READ_STATUS`: Checking for errors again, most likely.  Returned value is `[00200f00]`.
* `[26000000] ISC_DISABLE`: Disable the configuration, which I guess is necessary to enter user mode.
* Wait 200ms.  No idea -- this seems like an awfully long time to wait.
* `[ffffffff] NOP`: Clock in a bunch of extra NOPs.

All this is surrounded by my own `ecp5_reset` and `ecp5_release_reset`, and the FPGA doesn't actually begin wake-up (or raise the `DONE` pin) until after the the `PROGRAMN` pin is released to high.

Also curiously: the linear ramp in power usage that I observed previously doesn't happen with this programming method -- that implies that's I'd somehow fubar'd the internal state of the chip pretty badly. I haven't the slightest idea how that's possible.  With the working method, power is stable at ~40mA (~0.48W) for the entire operation.

Most of the above operations are easy to implement myself -- but I'll need to check that I can rearrange the bitstream from the format that Project Trellis's `decppack` dumps out.  I think I can ignore bitstream compression; it only takes ~4.5s (~224 KiBps) to load a bitstream, and I can probably improve that pretty easily.  A few quick experiments shows that increasing the SPI frequenty is only worth ~200ms, so it's possibly the lack of decent batching of operations in my hack with SSPIEmbedded.

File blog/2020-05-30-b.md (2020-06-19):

# 2020-05-30

## Bringup Phase 3: FPGA

I can now get the FPGA to respond to lots of different commands.  There's some weird ambiguity between what Project Lattice does, and what the Lattice sysCONFIG datasheet specifies.  

I think that the bitstream-in-SPI-eeprom format differs slightly from the SPI Slave configuration.

An interesting detail is that loading the bitstream definitely gets the FPGA's gates working: The power usage rises from ~30mA / 0.6W to ~120mA / 1.44W while loading the bitstream, and the chip surface temperature reaches 41C a minute or two after fully loading.  This seems like a positive sign, as it's doing something that at least sounds right.

However!  Once the bitstream is fully loaded, I release the chip from reset, and ... nothing happens.  Sigh.  The `PROGRAM` LED turns off, as expected, and `INIT` is moderately dim (1.969V, compare to 3.25V nominal), and `DONE` is dim (1.833V).  Both of these signals ought to be digital, but I'm not sure which are being driven and which are just open-drain or hi-z.  (The difference in brightness is probably the bogus pullup on `INIT`, which I ought to take off maybe.)  `D7` and `D8` are definitely at 0V, so the RTL it's not driving them properly.

Theories:

* RTL uses the wrong clock (external clock `clk_12mhz` isn't working somehow).
* RTL is messed up some other way. (Verify with verilator).
* I should be using the Lattice-recommended `LSC_BITSTREAM_BURST` instead of `LSC_PROG_INCR_RTI`, as Project Lattice generates by default.
* Board wiring is holding DONE / `INIT` wrongly, which inhibits the switch to user mode.  Might be able to override this by driving from FTDI chip directly.
* I'm missing some important step in the bitstream, which I'm not replicating properly in the `load_bitstream` code.
* I'm missing some step in the finalization of the bitstream programming.
* I've borked the image details somehow (even though the CRC matches).
* I'm running `ecppack` wrong, and generating a bad bitstream.

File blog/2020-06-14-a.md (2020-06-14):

# 2020-06-14

# More Bringup Woes.

Preivous attempts to get the FPGA working ran around on some confusion with the wakeup sequence.  However, debugging this devolved into flailing, since it *seemed* like there was an obvious solution, and none of them worked.

So, to add some rigor to the debugging process here: (_Tryhard mode: ACTIVATE_)

* Review Lattice datasheets for better understanding, and document this.
  Previosly I've encountered surprising details that weren't well-documented,
  which shifted my understanding of the system abruptly.
* Review Project Trellis bitstream code for insights that might be relevant.
* Simplify code, and develop some logging rigor to make sure I can reproduce
  interesting states.
* Develop a number of theories as to why it's not working.
* Disprove theories in detail, one at a time.

In retrospect, it would have been wise to set up the FPGA with more than one possible mode.  That might be hard to fit in a 4-layer board, though.

## Lattice sysCONFIG datasheet review

* Acronyms: Unsurprising.
* 1. Introduction
  * Detailed timing is in the ECP5 family datasheet.
* 2. Features
  * "Slave Serial" and "Slave SPI" are different things.  I'm using "Slave SPI", I think.
* 3. Definitions of Terms
  * "Programming" is altering the *external* source of configuration, "Configuring" is changing the internal configuration SRAM cells.  I'm not sure this is consistent elsewhere in the document.
  * "BIT" files are programming into nonvolatile memory directly -- which isn't useful to me since I'm using SPI Slave mode.
  * "User Mode": When running my image; ie, the state I can't get it into yet.
  * "Offline Mode": When user-mode is disabled and we're just configuring.  This is probably what I want.
  * "Direct Mode" / "Foreground Mode": Configuring, and all IO pins tri-stated.
    * Aside: these "modes" aren't necessarily mutually exclusive.
  * "Background Mode": Configuring, but IO pins are operational. (Maybe functioning normally, maybe pinholding).
  * "Transparent Mode": Configuring, but user mode active -- so we can be updating the CRAM while the device is active.  This implies that there's two copies of every CRAM bit; one that we're updating, and one that's actually participating in the function of the logic cell.
  * "Refresh": Either toggling the `PROGRAMN` pin, or sending the SSPI `REFRESH` command.  I'm not sure if it matters which I do, but it's worth investigating if SSPI mode expects to get the refresh command via that mechanism, and not by `PROGRAMN` toggling.  This seems unlikely to matter.
* 4. Configuration Details
  * "active configuration" here is described as "fuses", likely for the benefit of developers familiar with FPGAs that have actual fuses to program their configuration once.  Irrelevant to me.
  * 4.1 Bitstream / PROM size
    * I have the `LFE5U-45F`: Uncompressed bitstream size is 7.86 Mbit (~959 KiB) with no EBR, 9.74 Mbit (~1,158 KiB) with max EBR.  This is close to as observed from the open-source toolchain.
  * 4.2 Status Register
    * This is shifted out LSB first, which I'm reasonably sure I got right (since otherwise I'd get obvious nonsense values).
    * Bit 0 "Transparent mode": "not Transparent mode" perhaps implies "Offline mode".  This isn't stated explicitly.
    * Bit 9 "ISC Enable": "ISC" isn't defined here, so it's not clear what this means.  Plausibly "In-System Configuration".
    * Bit 29 "SED Error": Not clear what this is. "Single Error Detection" would be a CRC-related error.
    * Bit 30 "Bypass mode": No clue what Bypass mode means. I haven't observed this yet.
      * Note from later: This is for daisy-chaining, which I don't want, and should be off.
    * Bit 31 "Flow-through mode": Not sure what this is; probably for daisy-chaining configuration.  Ignore.
  * 4.3 Ports
    * SPCM is "Slave Parallel", SCM is "Slave Serial", but not SSPI "Slave SPI".
  * 4.4 sysCONFIG pins.
    * You have to take care to re-use the sysCONFIG pins as regular GPIO.  I'm not bothering, so I leave them dedicated. There's references here to meddling with the Lattice tools to declare this, but that's probably just to avoid PNR trying to use the pins.
    * Most of the pins have internal pull-ups, but some are recommended to have external pullups as well.  I should check if this is messed up by my LEDs.
    * `HOLDN` I ignored, but the internal pullup is probably fine.
    * `DOUT` I ignored, but it's just an output for daisy-chaining.  I re-used this pin for `ANALOG_R_OE`, but it's probably fine -- might cause some weird power behavior on the red ADC, but no funcitonal issues I think.
    * Pull-up resistor values in the comments seem arbitrary (1 Kohm, 4.7 Kohm, 10 Kohm).
  * 4.5 Dedicatd sysCONFIG pins.
    * `CFGMDN` pins sampled on rising edge of `INITN`, but they're hard-wired so it doesn't matter to me.
    * 4.7Kohm pullup is what I'd done, so that's fine.
    * JTAG port is always operational.
  * 4.6 `PROGRAMN` pin
    * Active-low, internal weak pullup (of ill-defined strength).
    * When asserted low, starts refresh sequence (ie, clearing configuration ram).  I haven't observed this explicitly yet, but it might be worth measuring via the scope.
    * Actual times are defined in family datasheet:
      * Names don't match: `T_PRGMJ` doesn't exist.  `T_PRGM` is min 110 ns, `T_PRGMRJ` (rejected) is max 50ns.  So, downward pulse must be greater that 110 ns to be reliably accepted; less than 50ns will be reliabily ignored, in between is unreliable.  No problems here.
      * `T_DPPINT` is max 70 ns, `T_DPPDONE` is max 80 ns.
      * `T_INIT` is probably `T_INITL`, which says it's low for max 55 ns (enough to clear all the sram bits).
      * All these times are so short that my host-based tools won't ever see the intermediate states -- it's ~milliseconds before they'll respond.  Should be fine.
    * 4.6.1 `INITN`
      * Bidirectional open-drain control pin.
      * Driven low by FGPA during refresh (implied?), released once it's ready for configuration.
      * Can be held down by other FPGAs to make them start up at the same time.
      * Later, driven low by FPGA if there's a configuration error.
      * This is potentially interesting, as it might block wake-up.
      * If `INITN` is high, I at least haven't hit an obvious configuration error.
    * 4.6.2 `DONE`
      * Bidirectional open-drain contron pin, weak pull-up.  High indicates User mode.
      * Driving this low externally can prevent wake-up.  (Idea: Sequencing should drive this high before finishing configuration?)
      * Aside: If this gets weirdly driven, might cause metastable behavior?  Unknown.
    * 4.6.3 `MCLK/CCLK`
      * I don't care about the various `MCLK` cases.
      * It's not clear if the FPGA expects a constantly-osciallating `CCLK`.  Probably not.
  * 4.7 Dual-purpose pins
    * 4.7.1 `HOLDN`: Don't care. If this was wrong, no configuration operations would work.
    * 4.7.2 `DOUT`: Apparently enabled by "Bypass" mode, for daisy-chained configuration.  This isn't useful to me, so I never want Bypass mode enabled.
    * 4.7.3 `CSN`: Ok.
    * 4.7.4 `CS1N`: Not enabled in SSPI mode.
    * 4.7.5 `WRITEN`: Not enabled in SSPI mode.
    * 4.7.6 `MOSI`: Ok.
    * 4.7.7 `MISO`: Ok.
    * 4.7.8 `D[7:0]`: Not enabled in SSPI mode.
    * 4.7.9 `IO[3:0]`: Not enabled in SSPI mode.
    * 4.7.10 `PERSISTENT`: Internal control bits that determine how the ports are handled.  Determines whether `MOSI` / `MISO` / `CSN` are left as sysCONFIG port, or switched to GPIO.  Doesn't say what the defaults are, or how to change them.
  * 4.8 JTAG pins
    * Ignore all this for now.
* 5. Configuration Process and Flow
  * No particular power sequencing is required (in SSPI mode; MSPI needs the flash to be stable before the FPGA reads it, obviously).
  * Sequence:
    * `INITN` and `DONE` are driven low, and the FPGA clears itself.
    * `INITN` is released to high, and we enter configuration mode.
    * Write all the configuration SRAM.
    * Wake-up.
    * `DONE` is released to high, and we enter user mode.
  * This all seems fine.
  * 5.1 Power-up sequence
    * Similar to before, not interesting.
  * 5.2 Initialization
    * `INITN` must be pulled high by an external resistor.  This might have issues with the LEDs I'm using.
    * More details in here might be worth reviewing.
  * 5.3 Configuration
    * "If `INITN` is asserted low, an error has occurred". Ok.
  * 5.4 Wake-up
    * This is where I have problems currently.
    * There's a fixed four-phase wake-up sequence, which can be configured by the user (How?).
      * Global Set/Reset (`GSR`)
        * Logic flops are set or reset based on CRAM.
      * Global Output Enable (`GOE`)
        * Output IOs are driven.  Inputs are always available.
      * External `DONE`
        * "An external agent that holds the `DONE` pin low prevents the wake-up process of the FPGA from proceeding."
        * "Only after the external `DONE`, if enabled, is active high does the final wake-up phase complete."
        * "Wake-up completes uninterrupted if the external `DONE` pin is disabled."
          * Diabling external `DONE` might help here -- but how's that done?
      * Global Write Disable (`GWDISn`)
        * Prohibits writes to internal block ram; released during wakeup.
    * Assertion of the internal DONE bit causes this state machine to start.
    * Nothing in here implies that wake-up clocks from `CCLK` are required, but that still might be so.
  * 5.5 User Mode
    * Stays in user mode until either `PROGRAMN` is toggled, `REFRESH` command received, or power cycle.
  * 5.6 Clearing configruation etc: Not interesting.
  * 5.7 Reconfiguration Priority
    * JTAG first, then `PROGRAMN` toggle, then others.
* 6. Configuration Modes.
  * 6.1. Master SPI: Skip.
  * 6.2. Slave SPI
    * "It is necessary to send a `REFRESH` command to load a new external flash image into the configuration SRAM."
      * Is it? Even the first time after power-on?
    * In Background mode, only read operations are permitted.  This won't be what I want.
    * Input is read from `MOSI` on the rising edge of `CCLK`. Ouput is valid on `MISO` on the falling edge of `CCLK`.
      * Pretty sure I got this right in the MPSSE setup, by brute-force.
    * "Lattice provides SSPIEmbeeded to insulate you from the complexity..." Yeah, sure.
    * 6.2.1. Method to enable SSPI
      * Must use `CFGMDN`, which I am.
      * Enabling SPI port persistence.  It's not clear how to do this.
        * SPI port is read-only once in user mode.  This might be reflected in the status register `WRITE` bit, not said here.
    * 6.2.2. Specifications and Timing
      * Opcodes are sent MSB-first, but results are read LSB-first.  Odd.
    * 6.2.3. Slave SPI Port AC Timing Requirements
      * Max clock is 33 MHz, but there's no minimum.
    * Command table
      * Not sure what "LSC" prefix is for (plausibly "Lattice Semiconductor Corporation")
      * Lots of these I don't care about (fuses, encryption, etc).
      * `LSC_PROG_SED_CRC`: Programs the "CRC based on configuration bits only".  Different kind of CRC.
      * I still need to go through the commands in detail.
    * 6.2.4. Slave SPI Configuration Flow
      * Diagram shows using `ISC_BITSTREAM_BURST`, rather than `ISC_PROG_INCR_RTI`.  Probably this doesn't matter, but it's worth trying.
      * This shows explicit `ISC_ENABLE` and `ISC_DISABLE` commands.
      * This might not show the wake-up sequence.
    * 6.2.5. Command Waveforms.
      * Got this already.
      * Class D commands (`CLEAR` and `REFRESH`) are self-timed, and don't need clocks outisde chip-select.
  * 6.3. Slave Parallel Mode.  Ignore.
  * 6.4. Slave Serial Mode.  Ignore.
  * 6.5. JTAG mode.  Ignore for now.
  * 6.6. TransFR Operation.  Ignore.
* 7. Software Selectable Options.
  * These must show up in the bitstream somehow, but it's not documented.
  * Ignore for now.
* 8. Device Wake-Up Sequence
  * There's only two valid sequences:
    * "4": DONE pin goes high first.
    * "21": DONE pin goes high last.
  * 8.1. Wake-up signals: Unsurprising.
  * 8.2. Wake-up clock source
    * Why is this the first time the datasheet mentions a wake-up clock source?
    * Defaults to internal clock, but can also use an external free-running clock source.
    * YoSYS doesn't seem to support the START module.
* 9. Daisy Chaining.  Ignore.
  * Bypass and Flow-through options are involved here.
* Appendix A. Slave SPI Programming Guide.  Useless.
* Appendix B. Bitstream Format
  * Why does this use `LSC_WRITE_EBR`, which isn't mentioned anywhere else in the doc?
  * Bitstream always ends with a 32-bit `DUMMY` command -- maybe that's necessary for wake-up.
* Appendix C. Slave SPI / Slave Flash.  Not useful?
* Appendix D. Master SPI Daisy Chaining.  Ignore.
* Appendix E. Slave SPI Daisy Chaining.  Ignore.

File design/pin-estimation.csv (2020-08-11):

Purpose | Signal | Mode | Bits | Encoding? | Clock Rate MHz | Req | Req Pins | Sample? | Sample Bits | Notes
 |  |  | 136 |  |  |  | 127 |  | 121
Clock | XIN | W | 1 | Clock | 21.47727 | 1 | 1 | 0 | 0 | Obviously don't need to sample the clock.
Reset | PPU1_~RESET~ | RW | 1 |  |  | 1 | 1 | 0 | 0
Reset | PPU2_~RESET~ | RW | 1 |  |  | 1 | 1 | 0 | 0
Reset | PPU2_~RESOUT1~ | RW | 1 |  |  | 1 | 1 | 0 | 0
Reset | PPU2_~RESOUT2~ | RW | 1 |  |  | 1 | 1 | 0 | 0
Peripheral Bus | ~PARD | W | 1 | Stobe | 3.579545 | 1 | 1 | 0 | 0 | We need to drive the periphral bus, but not sample it.
Peripheral Bus | ~PAWR | W | 1 | Stobe | 3.579545 | 1 | 1 | 0 | 0
Peripheral Bus | PA0 - PA7 | W | 8 | Data | 3.579545 | 1 | 8 | 0 | 0
Peripheral Bus | D0 - D7 | RW | 8 | Data | 3.579545 | 1 | 8 | 1 | 8
VRAM Address Bus | VA14 | R | 1 | Data | 3.579545 | 1 | 1 | 1 | 1 | We need to sample the VRAM bus. Plausibly compressible.
VRAM Address Bus | VAA0 - VAA13 | R | 14 | Data | 3.579545 | 1 | 14 | 1 | 14
VRAM Address Bus | VAB0 - VAB13 | R | 14 | Data | 3.579545 | 1 | 14 | 1 | 14
VRAM Data Bus | VDA0 - VDA7 | R | 8 | Data | 3.579545 | 1 | 8 | 1 | 8
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

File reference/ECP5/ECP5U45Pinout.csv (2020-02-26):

# Pin Out For ECP5U-45
# Revision 2.0. Added caBGA256 Package
# Revised Mar. 19, 2018
PAD | Pin/Ball Function | Bank | Dual Function | Differential | High Speed | DQS | CABGA554 | CABGA381 | CSFBGA285 | CABGA256
1 | NC | - | - | - | - | - | - | - | - | -
2 | NC | - | - | - | - | - | - | - | - | -
3 | NC | - | - | - | - | - | - | - | - | -
4 | NC | - | - | - | - | - | - | - | - | -
5 | NC | - | - | - | - | - | - | - | - | -
6 | PL11A | 7 | ULC_GPLL0T_IN | True_OF_PL11B | TRUE | LDQ17 | C2 | A4 | C12 | B1
7 | PL11B | 7 | ULC_GPLL0C_IN | Comp_OF_PL11A | TRUE | LDQ17 | C1 | A5 | B12 | B2
8 | VSSIO7 | - | - | - | - | - | - | - | - | -
9 | PL11C | 7 | - | True_OF_PL11D | - | LDQ17 | C4 | B5 | - | C3
10 | VCCIO7 | - | - | - | - | - | - | - | - | -
11 | PL11D | 7 | - | Comp_OF_PL11C | - | LDQ17 | C3 | C5 | - | D3
12 | PL14A | 7 | - | True_OF_PL14B | TRUE | LDQ17 | D4 | C4 | A12 | C1
13 | VCCAUX | - | - | - | - | - | - | - | - | -
14 | PL14C | 7 | - | True_OF_PL14D | - | LDQ17 | B1 | A3 | - | E3
15 | PL14B | 7 | - | Comp_OF_PL14A | TRUE | LDQ17 | D3 | B4 | - | C2
16 | VSS | - | - | - | - | - | - | - | - | -
17 | PL14D | 7 | - | Comp_OF_PL14C | - | LDQ17 | B3 | B3 | - | F3
18 | PL17A | 7 | - | True_OF_PL17B | TRUE | LDQS17 | D2 | E4 | D13 | D1
19 | VCC | - | - | - | - | - | - | - | - | -
20 | PL17C | 7 | - | True_OF_PL17D | - | LDQ17 | E3 | C3 | - | F4
21 | PL17B | 7 | - | Comp_OF_PL17A | TRUE | LDQSN17 | E1 | D5 | C13 | E2
22 | VSS | - | - | - | - | - | - | - | - | -
23 | PL17D | 7 | - | Comp_OF_PL17C | - | LDQ17 | D1 | D3 | - | F5
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

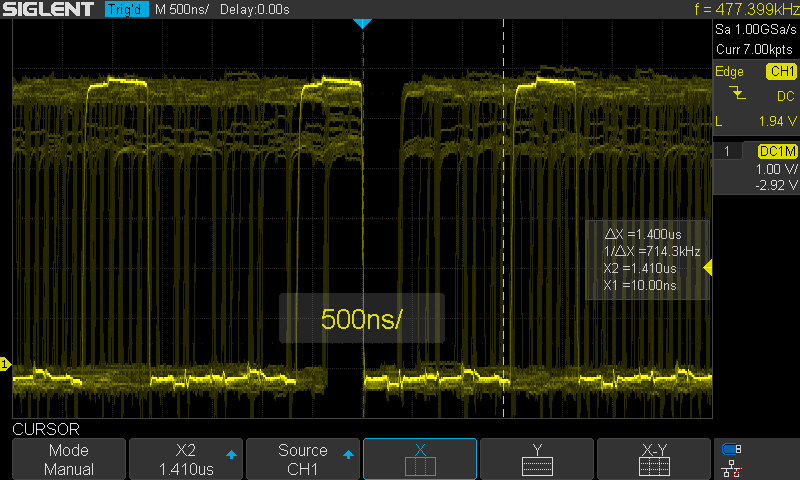
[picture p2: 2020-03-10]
blog/2020-03-07-a/SDS00008.png

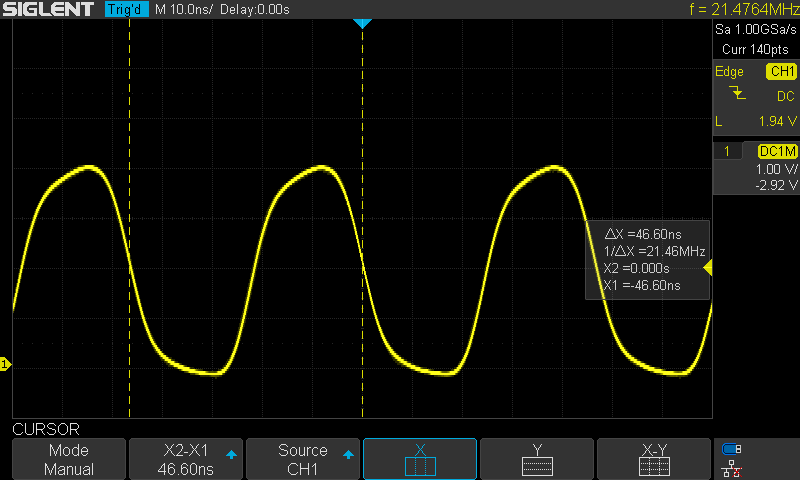
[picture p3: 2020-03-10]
blog/2020-03-07-a/SDS00007.png

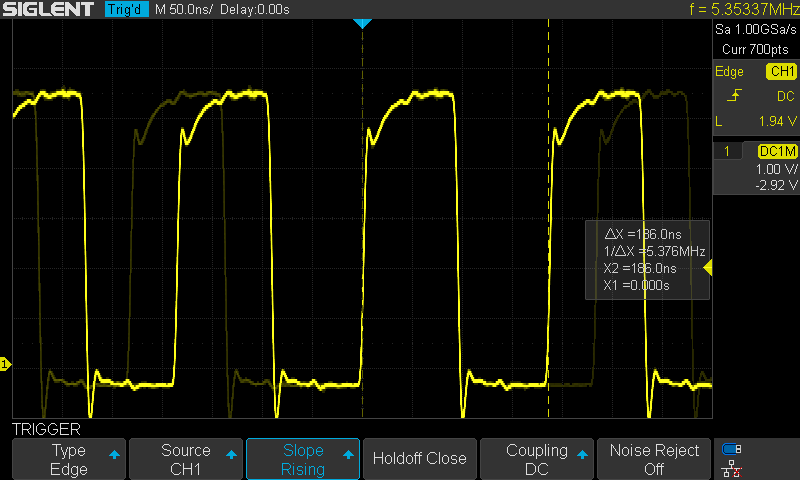
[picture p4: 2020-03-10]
blog/2020-03-07-a/SDS00010.png

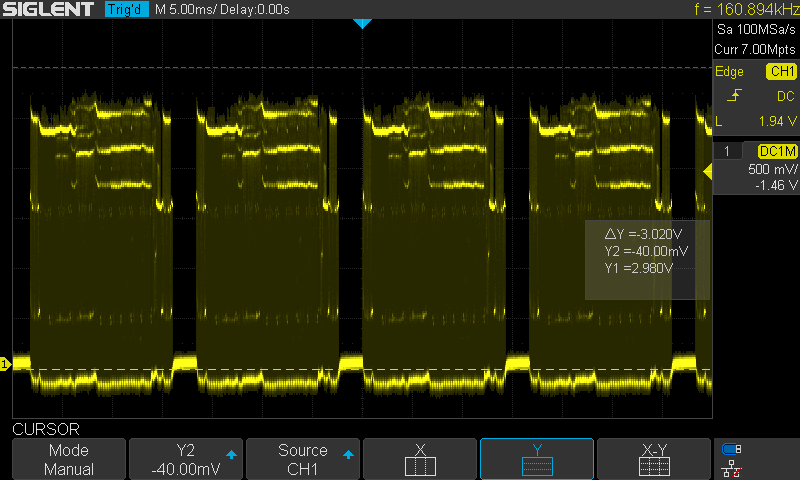
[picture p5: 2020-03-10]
blog/2020-03-07-a/SDS00012.png

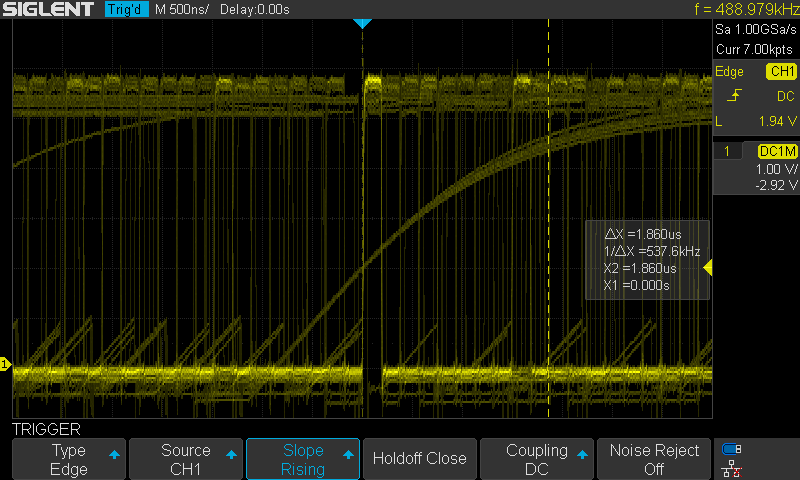
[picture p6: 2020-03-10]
blog/2020-03-07-a/SDS00011.png

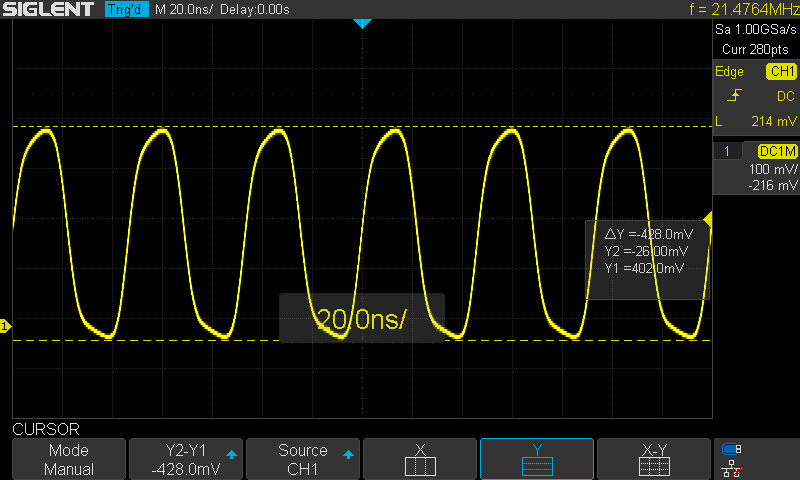
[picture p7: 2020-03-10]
blog/2020-03-07-a/SDS00002.png

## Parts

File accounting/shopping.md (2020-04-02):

Basic lab equipment:
*   A "well" style tip, for drag soldering.
*   Hot-air station: Quick 861DW
*   Board preheater / hot plate
*   Digital oscilloscope (if not borrowing from Kor).
*   Antistatic wrap strap.
*   Handy-hand grabber thingys, or something to hold stuff while I work.
*   Optional: Trinocular electronics microscope?  Not sure if needed yet; might
    be able to get a cheap USB one.

Lab supplies:
*   ...

Final board parts (pending actual BoM):
*   2 or more used SNES from E-Bay (one to cannablize, and one to hook up to a
    scope for comparison).
*   PCB (likely from JLPCB), possibly with small parts pre-installed.
*   Some FPGA of reasonable size and packaging (ICE40 HX or ECP), and
    supporting chips:
    *   Big EEPROM, for holding FPGA bitstream.
*   Some USB interface chip (probably FT2232HL), and supporting chips:
    *   Some CMOS oscillator (likely 12 MHz).
    *   Small EEPROM, as recommended by FTDI datasheet.
*   Voltage regulator chips, probably LDO 5V to 3.3V / 1.8V / 1.2V.
    *   5V from USB directly, with decoupling capacitors
    *   3.3V to drive FTDI and FPGA
    *   1.8V for FTDI internal core.
    *   1.2V for FPGA I think.
*   Some voltage shifter stuff.  Not sure about this yet.
*   3x Analog ADC chips, for video rate (>3.5Msamp).
*   Micro USB connector.
*   Lots of surface-mount passives (resistors / capacitors / inductors?).
*   Bunch of surface-mount LEDs.
*   Bunch of 0.1-pitch headers and jumpers.
*   Standoffs and feet for the board.

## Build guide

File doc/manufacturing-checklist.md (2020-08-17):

# Manufacturing Checklist

Follow these steps before shipping a board off for manufacturing:

## Schematic

1. Open Schematic.
1. Run "Annotate Schematic".  No changes are expected.
1. Run "Electrical Rule Checker".  Verify no errors.
   1. Caveat: Ignore FPGA tristate-to-other-pins errors.
1. Check that all footprints are assigned.
1. In "Page Settings":
   1. Set "Issue Date" to today.  Check "Export to other sheets."
   1. Increment "Revision".  Check "Export to other sheets."
1. Plot the schematic.
   1. Format: PDF
   1. Output director: `~/spla`.
   1. Click "Plot All Pages"
   1. Verify output PDF in `~/spla/spla-board.pdf`.
1. Generate Bill of Materials.
   1. Use `bom2csv` plugin, but only for the `.xml` output file.
1. Save and close the schematic.
1. Commit all of the above.
   1. Commit description: "schematic: Export revision {REV}.".
   1. Tag the commit as `schematic-rXXX`.

## PCB

1. Open PCB.
1. Run "Update PCB from schematic".  Expect no changes.
1. Run "Design Rule Checker".
   1. Check "Refill all zones...".
   1. Click "Run DRC". Verify no errors.
1. In "Page Settings":
   1. Set "Issue Date" to today.
   1. Increment "Revision".
1. Update traceability markings to match.
1. Save.
1. Screenshot PCB, and save in `images/`.
   1. Update link in README to match.
1. Commit all of the above.
   1. Commit description: "pcb: Export revision {REV}.".
   1. Tag the commit as `pcb-rXXX`.

## Gerber files

1. Plot the PCB [according to JLCPCB's article](https://support.jlcpcb.com/article/44-how-to-export-kicad-pcb-to-gerber-files):
   1. Plot format: `Gerber`
   1. Output directory: `./gerber` (inside project directory).
   1. Layers: `F.Cu`, `In1.Cu`, `In2.Cu`, `B.Cu`, `F.Paste`, `B.Paste`, `F.SilkS`, `B.SilkS`, `F.Mask`, `B.Mask`, `Edge.Cuts`.
   1. Options
      1. Check "Plot footprint values" _(necessary?)_
      1. Check "Plot footprint references" _(necessary?)_
      1. Uncheck "Exclude PCB edge layer...".
      1. Other options are default.
   1. Click "Plot".
   1. Click "Generate Drill Files"
      1. Options:
         1. Drill File Format: "Excellon"
         1. Check "PTH and NPTH in single file".
         1. Map File Format: PostScript
         1. Drill Origin: Absolute
         1. Drill Units: Inches
         1. Zeros Format: Decimal format.
      1. Click "Generate Drill File".
1. Verify generated files in Gerber Viewer.
   1. In particular, check traceability markings.
1. (Optional) Print Front / Back layouts on paper.
   1. "Print..."
      1. Included Layers: "F_Cu.gbr"
      1. Uncheck "Print Mirrored"
      1. Print to file "output-front.pdf"
   1. "Print..."
      1. Included Layers: "B_Cu.gbr"
      1. Uncheck "Print Mirrored"
      1. Print to file "output-back.pdf"
   1. Print both files on paper and verify footprints.
1. Commit all of the above.
   1. Commit description: "manufacturing: Export Gerber files revision {REV}.".
   1. Tag the commit as `manufacturing-rXXX`.
1. Zip the generated files. _(Don't bother committing the zip file.)_
   1. cd to `spla-board/gerber`.
   1. Run `zip /mnt/shared/spla-board-rXXX-gerber.zip *.gbr *.drl`

## Ordering via JLCPCB

1. JLCPCB options:
   1. Layers: 4 (required)
   1. Dimensions: (from gerber files)
   1. PCB Qty: (arbitrary)
   1. Different Design: 1
   1. Delivery Format: Single PCB
   1. PCB Thickness: 1.6mm
   1. Impedence: No (Not sure this matters)
   1. PCB Color: Green
   1. Surface Finish: ENIG-RoHS
   1. Copper Weight: 1oz
   1. Gold Finders: No
   1. Material Type: FR-4 TG155 (will be required later anyways)
   1. Castellated Holes: No
   1. Remove Order Number: Specify Location
   1. Advanced Options
      1. Min Hole Size / Diameter: 0.2mm/0.4mm
      1. Paper between PCBs: Yes
      1. Confirm Production File: No
   1. Stencil
      1. Framework: No
      1. Dimensions: 380*280
      1. Customized Size: 200mm*150mm (this might be backwards)
      1. Stencil Side: Top+Bottom on separate stencil
      1. Stencil Qty: 2
      1. Electropolishing: Yes (useful for small pitch / BGA)
      1. Fiducials: No Fiducials

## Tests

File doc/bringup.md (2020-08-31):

# Bringup sequence

_A more realistic sequence than below, ignoring the various soldering details._

1.  Parts inspection.
1.  Power validation.
    1.   Apply 12V power.
    1.   Verify 12V power via test points (`TP3`, `TP4`).
    1.   Verify that power LEDs (`D1`, `D2`) are lit.
    1.   Measure 3.3V and 5.0V switching regulators.
    1.   Enable 1.1V and 2.5V LDO linear regulators via jumpers.
    1.   Measure 1.1V and 2.5V LDO linear regulators.
1.  FTDI Bringup.
    1.   Enable 3.3V via jumpers.
    1.   Verify 12 MHz clock input on test pad.
    1.   Verify 12 MHz clock input on FTDI pin 2.
    1.   Verify 1.8V internal LDO linear regulator on test pad.
    1.   Verify USB connectivity.
    1.   Run `splat bringup_first` to verify basic FTDI connectivity.
    1.   Run `splat bringup_ftdi` to verify pins.
    1.   Run `splat ftdi_new_device`, with appropriate serial number.
    1.   Power-cycle the board to use the new VID/PID/Serial.
1.  FPGA Bringup.
    1.   Run `splat bringup_fpga`, and verify flashing LEDs.
    1.   Run `splat bringup_fifo` to verify ADBUS fifo pins.
    1.   Run `splat bringup_boundary`, and verify connectivity of the FPGA pins.
         1.  Probe using jumper wire on `EXTRA3` to various pins.
1.  Level Shifter Bringup.
    1.   Enable 5.0V via jumpers.
    1.   Run `splat bringup_boundary --levelshifter1`, and verify connectivity of the FPGA input-only and input-capable pins.
         1.  Probe using jumper wire on `BODGE3` to PPU1/PPU2/VRAM pads.
         1.  *Be very careful not to short to any 3.3V pins.*
    1.   Run `splat bringup_boundary --levelshifter2`, and verify the FPGA output-only pins via oscilloscope.
1.  SNES VRAM Bringup
    1.   Run `splat bringup_vram`.
    1.   Run `splat bringup_vram --random` for more testing.
1.  SNES PPU Bringup
    1.   _(Run some test program to verify that the PPU pins are connected.)_
1.  (Optional) Analog Bringup
    1.   _(Skip for now.)_
1.  Final Validation
    1.   _(Run some test program to program the PPUs and collect a stock test image.)_

## Legacy bringup sequence

_This sequence assumes a "Progressive Bringup", where each section of the board
is assembled and testing one at a time. This turns out to be a really stupid
idea. Don't do it this way._

Follow these steps to build a working SPLA board, starting from a bare board
and parts.  This is the most-paranoid bringup for the first board; many steps
can be skipped or merged once the board layout is proven.

1.  Visually inspect PCB.
    1.  Verify PCB revision.  These instructions are for `SPLA Breakout Board Rev 009`.
    1.  Inspect FPGA BGA area.
    1.  Inspect 'narrow' areas (ie, minimum-pitch traces).
    1.  Inspect via alignment.
    1.  Sand edges with fine-grit sandpaper (not necessary, but more professional).
    1.  Pre-clean PCB surface with isopropyl alcohol, if necessary.
    1.  Insert hex standoffs.
1.  Power validation.
    1.  Solder barrel jack: `J7`.
    1.  Solder power pinheaders: `J12` (2x8), `J4` (2x2).
    1.  Solder `ST1S10` regulators: `U7`, `U8`.
    1.  Solder inductors: `L1`, `L2`.
    1.  Solder LEDs: `D1`, `D2`
    1.  Solder power-related passives.
    1.  Configure test load: several 220-ohm resistor(s) on breadboard.
    1.  Connect test load to power pinheader.
    1.  Connect 12V lab supply with power adapter pigtail.  Limit current to 100 mA.
    1.  Verify that 5V and 3.3V LEDs are lit.
    1.  Verify that 5V regulator output is stable (via oscilloscope).
    1.  Verify that 3.3V regulator output is stable (via oscilloscope).
    1.  Disable 12V power.
    1.  Solder 2.5V and 1.1V LDOs `U9` and `U14`.
    1.  Solder 2.5V and 1.1V passives.
    1.  Connect jumpers on `J4`.
    1.  Enable 12V power.  Limit current to 100mA.
    1.  Verify that 2.5V LDO output is stable (with test load).
    1.  Verify that 1.1V LDO output is stable (with test load).
    1.  Remove 12V power.
    1.  Connect jumpers to enable power to the rest of the board.
1.  USB connection
    1.  Solder USB connector: `J1`
    1.  Solder JTAG pinheader: `J2`.
    1.  Solder `FT2232H` chip: `U2`.
    1.  Solder `93LC66B` EEPROM: `U3`.
    1.  Solder LEDs: `D3`, `D4`, `D5`, `D6`.
    1.  Solder front-side FTDI-related passives.
    1.  Switch to back of board.
    1.  Solder crystal oscillator: `X0` (reverse of board).
    1.  Solder back-side USB/FTDI-related passives.
    1.  Enable 12V power.
    1.  Verify oscillator output (frequency and voltage) on oscilloscope.
    1.  Verify connection to host via `lsusb`.
    1.  Verify connection to host with `spla` command.
    1.  Verify the absense of IO-pin solder bridges with `spla bringup_ftdi`.
    1.  Program the FTDI EEPROM with `spla ftdi_new_device`.  Select a serial number properly.
    1.  Power cycle the board to reset FTDI.
    1.  Verify that properly-configured FTDI comes up as expected on `lsusb`.
    1.  Verify that the FTDI comes up with the correct serial number with `spla ftdi_list_devices`.
    1.  (Optionally) Verify `ADBUS` and `BDBUS` connectivity via MPSSE GPIO interface, on oscillscope. *Need a tool for this.*
    1.  *Note: After this point, these instructions are a bit fuzzy.*
1.  FPGA
    1.  Solder FPGA to the board, using hot air rework station or reflow oven. *This might need to be done first, to avoid messing up other soldering on the board.*
    1.  Verify basic connectivity to FTDI `BDBUS` SPI pins, and get ECP5 SPI Slave interface working. *Need a tool for this.*
    1.  Load `bringup_blinky` FPGA image, and verify that sample LEDs blink. *Need to write this image.*
    1.  Load the bringup FPGA image. *Need to write this image.*
    1.  Use function generator (and/or crummy Arduino substitute) to drive each external pin one at a time, and verify connectivity and lack of bridges. *Need a tool for this.*
1.  Level Shifters
    1.  Solder all level shifter chips.
    1.  Reverify using bringup FPGA image.
    1.  Verify input and output voltages with multimeter (or scope).
1.  SNES chips
    1.  Verify correct video operation of a victim SNES.
    1.  Desolder `PPU-1`, `PPU-2`, and both VRAM chips from the SNES board.
    1.  Visually inspect salvaged chips for damage.
    1.  Solder salvaged VRAM chips to the board.
    1.  Solder any related passives to the board.
    1.  Verify connectivity between `PPU` pads and VRAM chips, via multimeter -- probing top of pins.
    1.  Verify VRAM read/write functionality via FPGA image. *Need to write this image.*
    1.  Solder `PPU-1` and `PPU-2`.
    1.  Verify connectivity between `PPU` pins (not pads) and VRAM chips, via multimeter.
    1.  Verify connectivity between `PPU-1` and `PPU-2` inter-PPU bus pins, via multimeter.
    1.  Verify connectivity between `PPU-1` and `PPU-2` peripheral bus pins, via multimeter.
    1.  Verify connectivity between `PPU-1` and `PPU-2` reset pins, via multimeter.
    1.  Verify connectivity between `PPU-1` and `PPU-2` `XIN` pin and pad, via multimeter.
    1.  Solder analog jumper headers.
    1.  Verify connectivity between `PPU-2` analog pins and analog headers.
    1.  Load PPU bringup FPGA image.  *Need to write this image.*
        1.  Connect reset passthrough jumper.
        1.  Drive 21.47727MHz clock signal to both PPU chips.
        1.  Release `PPU-2` from reset.
        1.  Scan for `HBLANK` and `VBLANK` signal.
        1.  Debug extensively.
1.  Analog chips
    1.  Verify analog outputs from `PPU-2` via oscilloscope.
    1.  Solder voltage bias resistors.
    1.  Verify voltage biasing via oscilloscope.
    1.  Solder amplifier Opamps, passives, and jumpers.
    1.  Solder analog power LDO.
    1.  Verify stability of analog power domain.
    1.  Verify value and stability of reference voltage levels.
    1.  Load FPGA image that drives a test vector into the PPU memory.  *Need to collect this test vector and write this image.*
    1.  Solder ADC chips.
    1.  Load FPGA image that drives a test vector and collects the results via USB.
    1.  Verify collected image correctness.
    1.  Debug extensively.
1.  Board bringup complete.
    1.  Proceed with software development; research-directed from this point.

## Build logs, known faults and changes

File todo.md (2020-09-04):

# TODO

* pm: Organize TODO items better than this list.
* pm: Survey blog posts for forgotten TODO items.
* pm: Start a website?
* blog: Write export-to-website tool (or find static site generator).
* blog: Add photos and scope images.
* reference: Retrieve datasheets for all parts.
* rtl: Build netlist-to-lpf extraction script.
* rtl: Build async fifo module.
* rtl: Build plausible FTDI-fifo-interface module.
* rtl: Design stream merging protocol.
* rtl: Build stream merging protocol module.
* rtl: Build opcode processor.
* software: Get rid of global-constant mess.
* software: Fix device enumeration logic, and `ftdi_list_devices`.
* software: Fixup `ftdi_test_raw` to handle mpsse modes better (labelled pins, individual changes, etc).
* software: Add pin numbers/names to `bringup_ftdi`.
* software: Fix MPSSE hi/lo flushing to be less touchy.
* software: Integrate or invent a decent unit testing framework.
* inventory: Write summary tool.
* inventory: Write inventory-to-BoM comparison tool.
* inventory: Add borrowed scope.
* inventory: Note pre-existing tools (#1 screwdriver, label printer).

## Next Schematic / PCB revision

* Remove `LVL_PA_DIR`, which is probably unnecessary.
* Move `FIFO_SIWU` to the correct pin (pin 30 `ACBUS4`, not pin 34 `ACBUS7`).
* Fix adjacent pins bridged on `U20`.
* Fix pads / packages for various capacitors.
* Fix push button pad orientation (wrong pair shorted).
* Fix naming of `FGPA_~VRD~`; various signals with `~` (should be paired).

### Skipped ideas

* Consider adding an alternate clock source for the FPGA.
  * Not necessary at this point, I think -- 12MHz and FTDI's 60MHz should be sufficient.
* Compact the board, since there's quite a bit of unnecessary empty space.
  * This is only partially possible (pulled in left edge by 13mm), and not worth the cost savings.
* Consider adjusting 3.3V and 5V regulators to be up a notch (sligtly below spec, probably due to overly-idealistic calculations).
  * No, it's within spec for the 1% resistors.  Doesn't matter.
* Remove JTAG connector, or reduce its footprint.
  * No compelling reason to do so -- I don't need it, but it's not a space issue.
* Consider if I can have the spare pins to double-duty as both LED outputs and test-point inputs.
  * Not worth the trouble.

## Deferred

Things put off for now (possibly indefinitely).

* lab: Bodge wire to vblank / hblank on real SNES, and measure analog voltage levels with scope.

## Dropped

Things that I'd planned to do, but decided to drop.

* schematic: Simulate opamp layouts in analog block.
  * They're simple enough (just voltage followers) that I'm not worried.
* schematic: Add 1-ohm 0.1% resistors in series with power rails, with test points for power measurement.
  * Decided not to bother; I don't care much about power usage (if it's not too large). I can also measure with a bench supply if I want to, which is likely more accurate anyways.
* schematic: Fix FPGA decoupling capacitors.
  * Infeasible because FPGA breakouts suck, and I don't have space.  Good enough for now.
* schematic: Review with Nate.
  * Infeasible; he's too busy at the moment.
* pcb: Shield VRAM data bus from power switching noise, if necessary?
  * It's probably not necessary.
* reference: Reverify datasheets for gotcha details.
  * Laziness.
* schematic: Run through [schematic checklist](https://github.com/azonenberg/pcb-checklist/blob/master/schematic-checklist.md)
  * Laziness.
* pcb: Run through [PCB checklist](https://github.com/azonenberg/pcb-checklist/blob/master/layout-checklist.md)
  * Laziness.

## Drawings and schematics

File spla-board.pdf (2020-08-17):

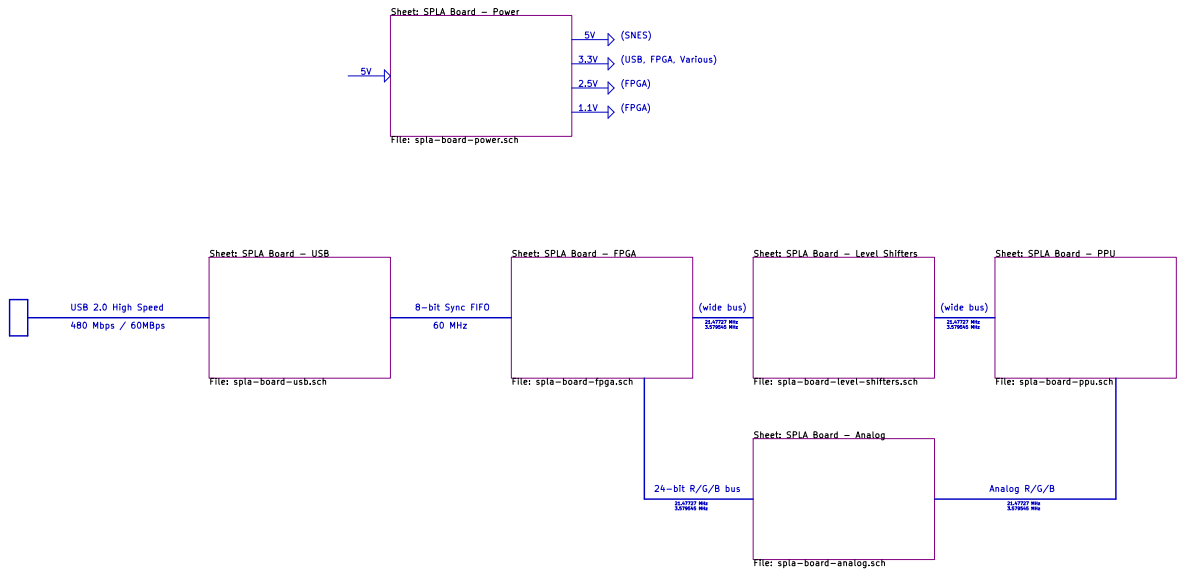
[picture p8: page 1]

Sheet: SPLA Board - Power File: spla-board-power.sch Sheet: SPLA Board - USB

Sheet: SPLA Board - FPGA

21.47727 MHz 3.579545 MHz 21.47727 MHz 3.579545 MHz 8-bit Sync FIFO
60 MHz

File: spla-board-usb.sch

File: spla-board-ppu.sch

Sheet: SPLA Board - Analog

File: spla-board-analog.sch

File: spla-board.sch Sheet: /
Id: 1/7 Title: SPLA Board - Root

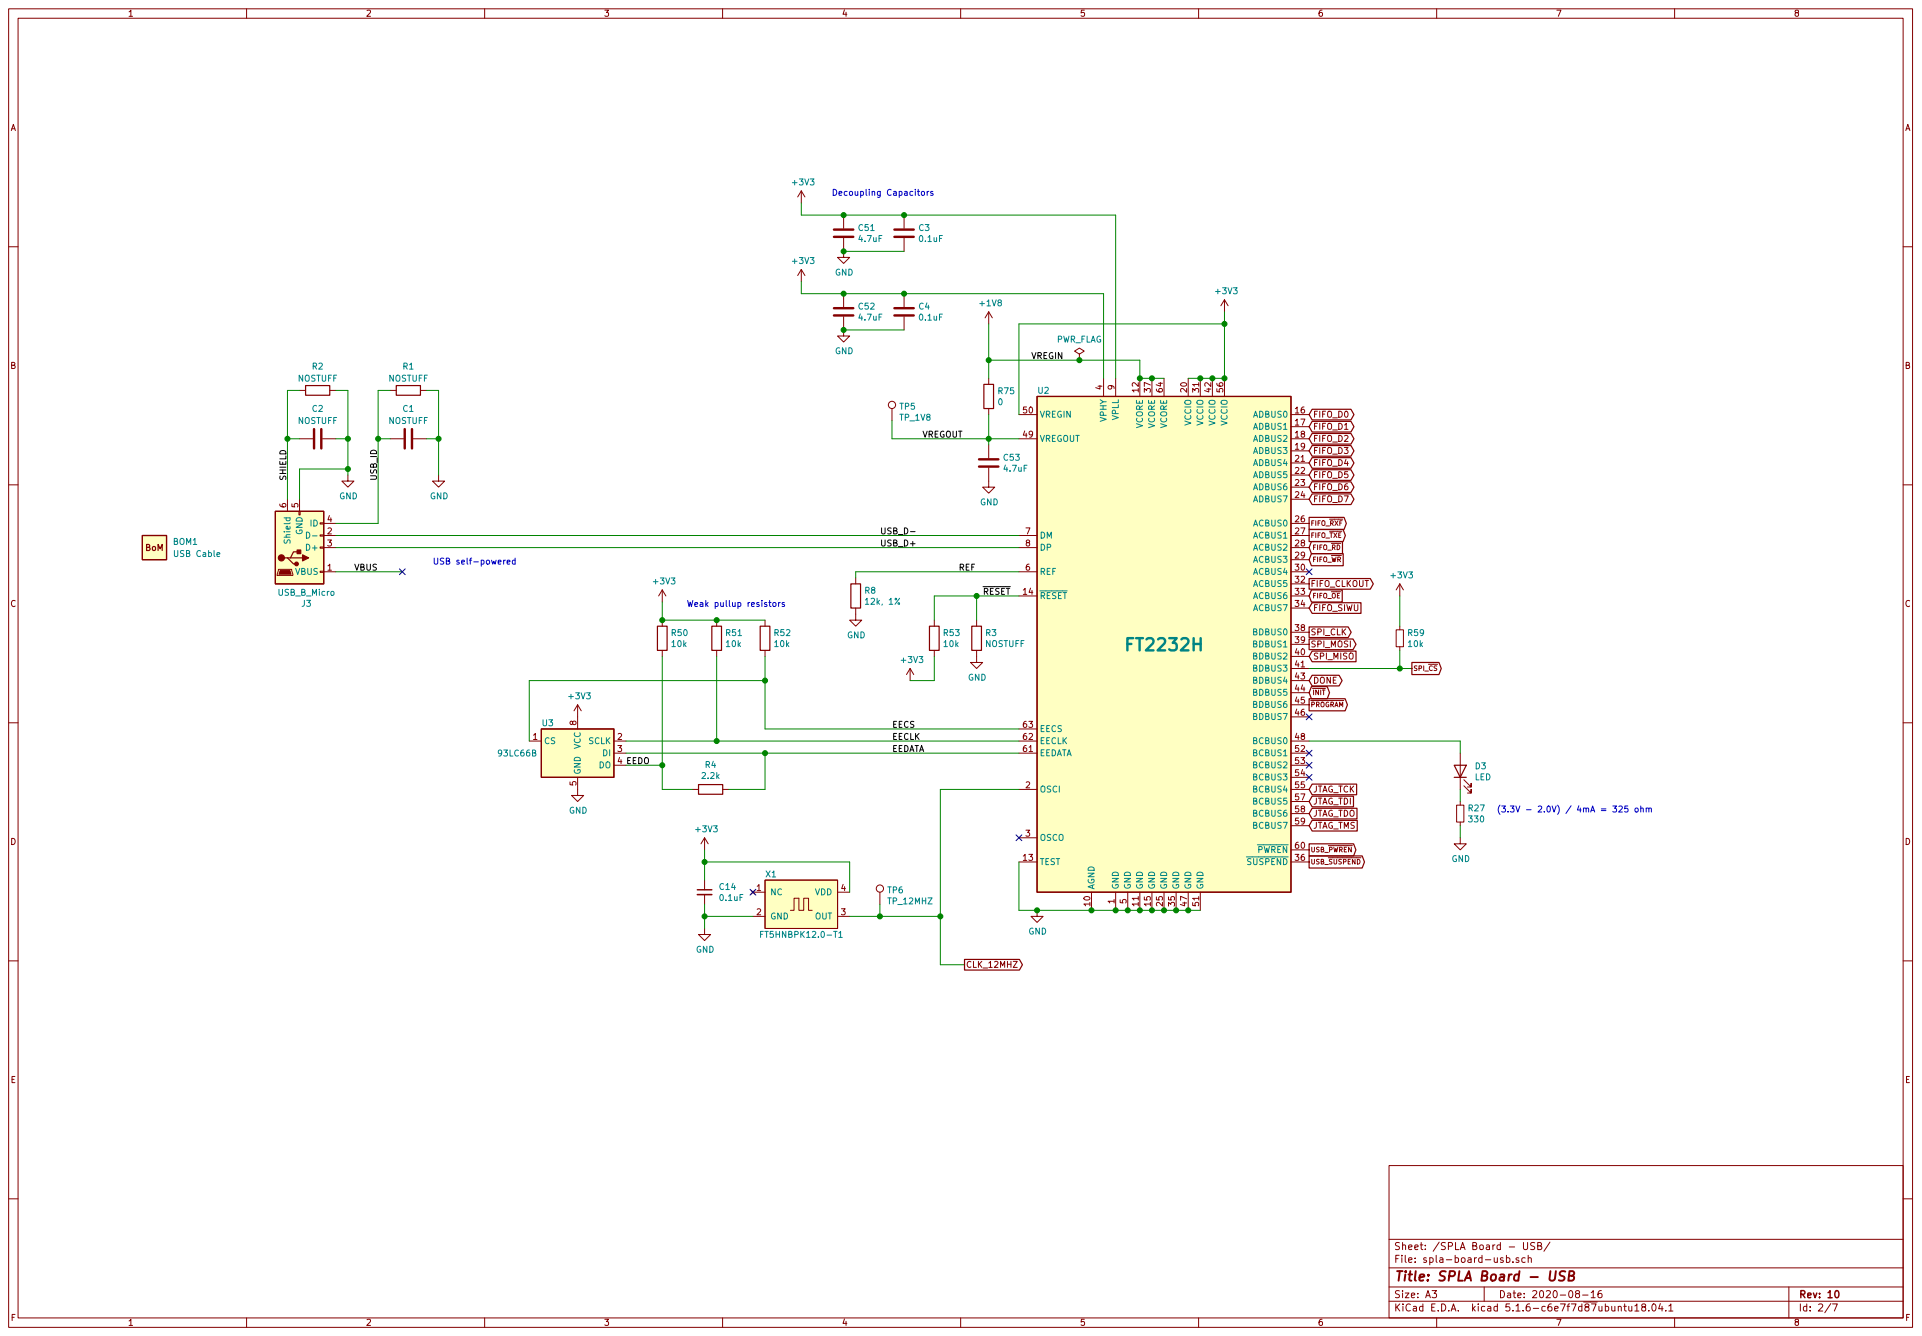
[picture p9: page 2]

1 AGND 10 GND 11 VCORE 12 TEST 13 RESET 14 GND 15 ADBUS0 16 ADBUS1 17 ADBUS2 18 ADBUS3 19 OSCI 2 VCCIO 20 ADBUS4 21 ADBUS5 22 ADBUS6 23 ADBUS7 24 GND 25 ACBUS0 26 ACBUS1 27 ACBUS2 28 ACBUS3 29 OSCO 3 ACBUS4 30 VCCIO 31 ACBUS5 32 ACBUS6 33 ACBUS7 34 GND 35 SUSPEND 36 VCORE 37 BDBUS0 38 BDBUS1 39 VPHY

4 BDBUS2 40 BDBUS3 41 VCCIO 42 BDBUS4 43 BDBUS5 44 BDBUS6 45 BDBUS7 46 GND 47 BCBUS0 48 VREGOUT 49 GND

5 VREGIN 50 GND 51 BCBUS1 52 BCBUS2 53 BCBUS3 54 BCBUS4 55 VCCIO 56 BCBUS5 57 BCBUS6 58 BCBUS7 59 REF 6 PWREN 60 EEDATA 61 EECLK 62 EECS 63 VCORE 64 DM 7 DP 8 VPLL

File: spla-board-usb.sch Sheet: /SPLA Board - USB/
Id: 2/7 Title: SPLA Board - USB

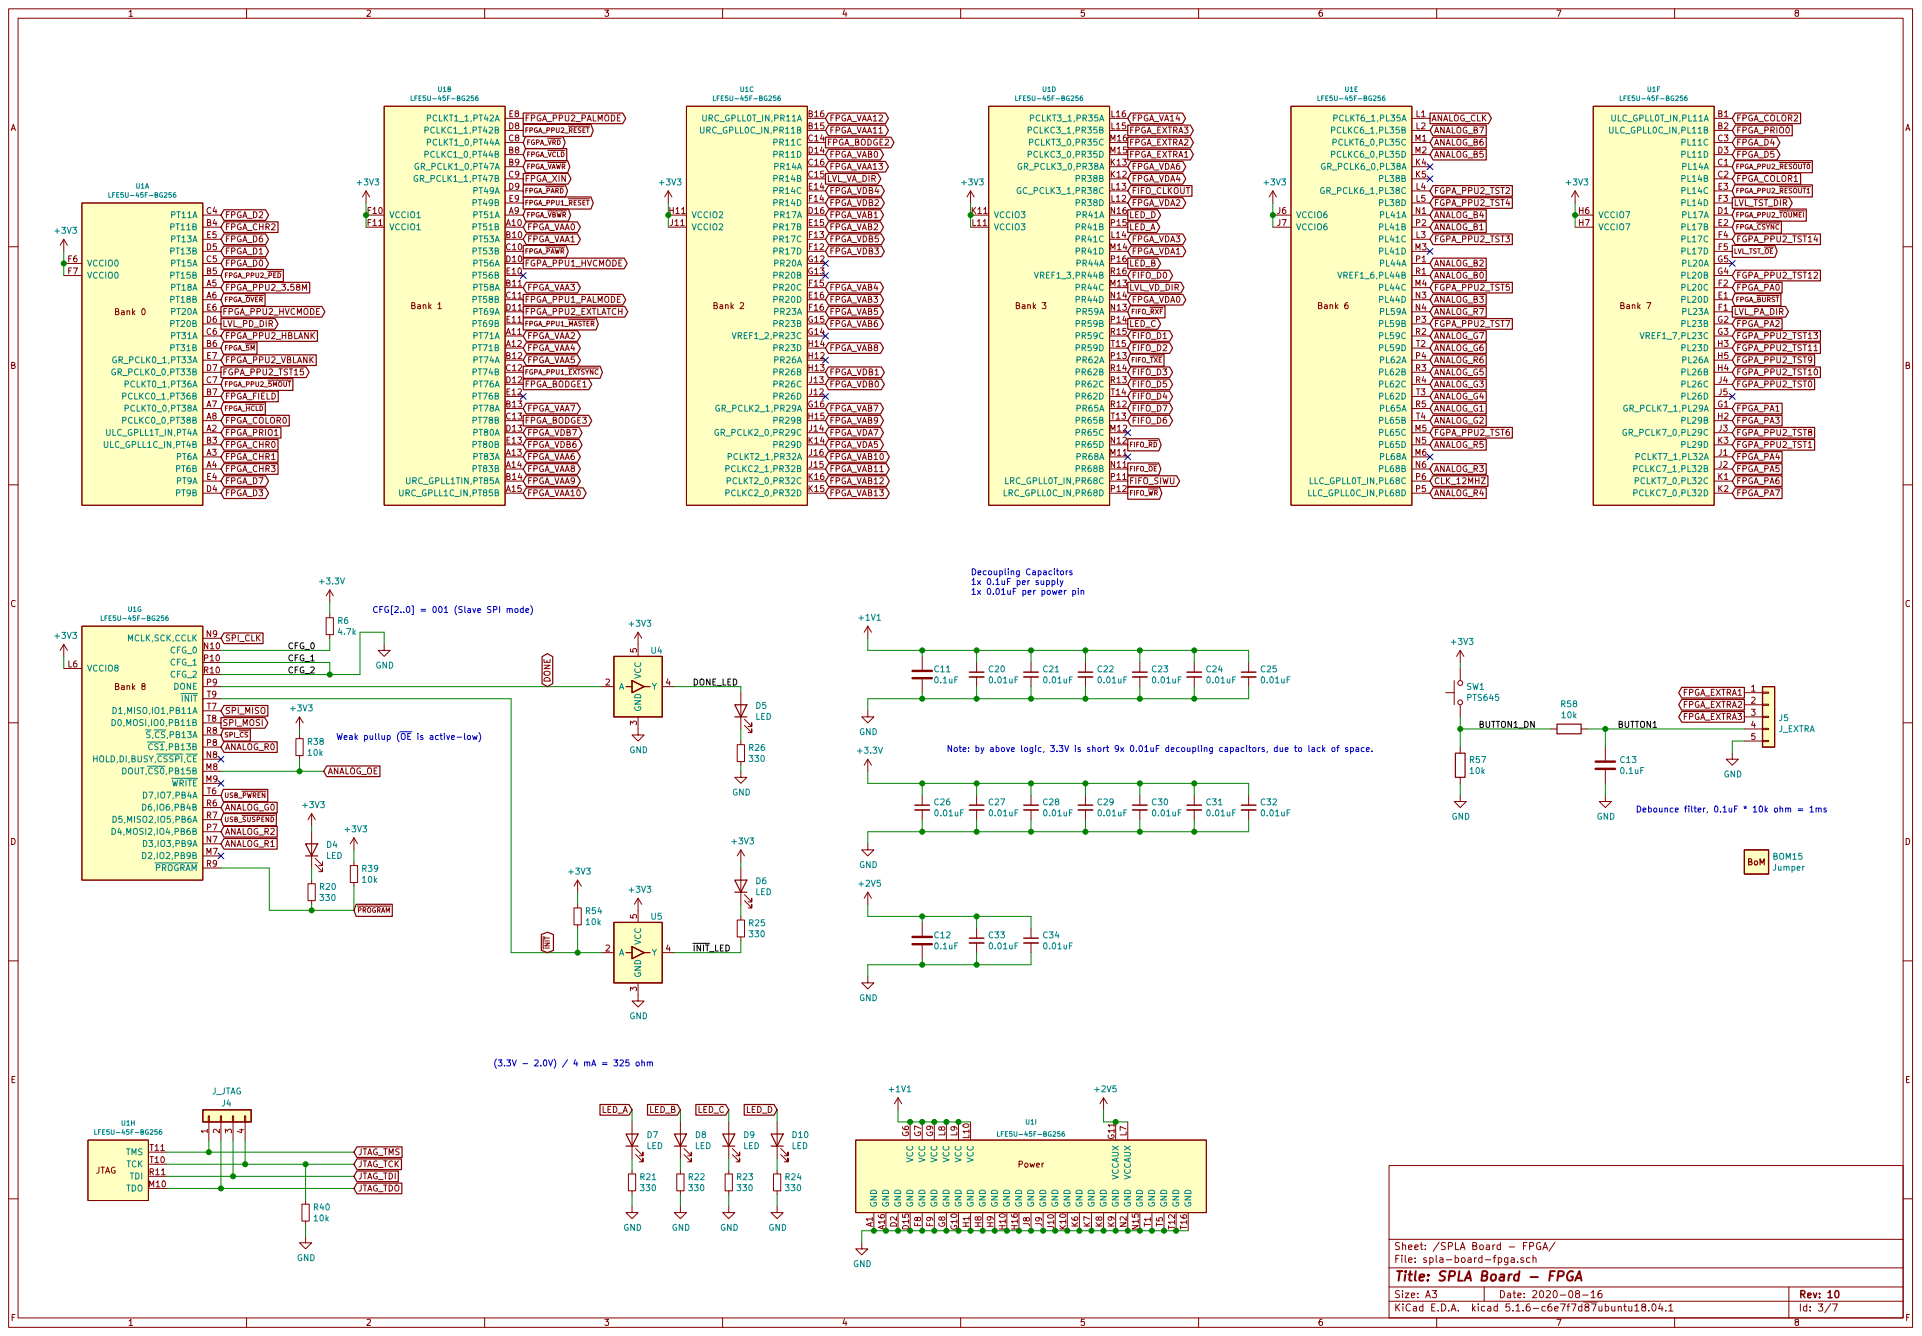
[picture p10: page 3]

Weak pullup (OE is active-low)
Jumper +3V3 R38
ANALOG_OE

Note: by above logic, 3.3V is short 9x 0.01uF decoupling capacitors, due to lack of space.

File: spla-board-fpga.sch Sheet: /SPLA Board - FPGA/
Id: 3/7 Title: SPLA Board - FPGA

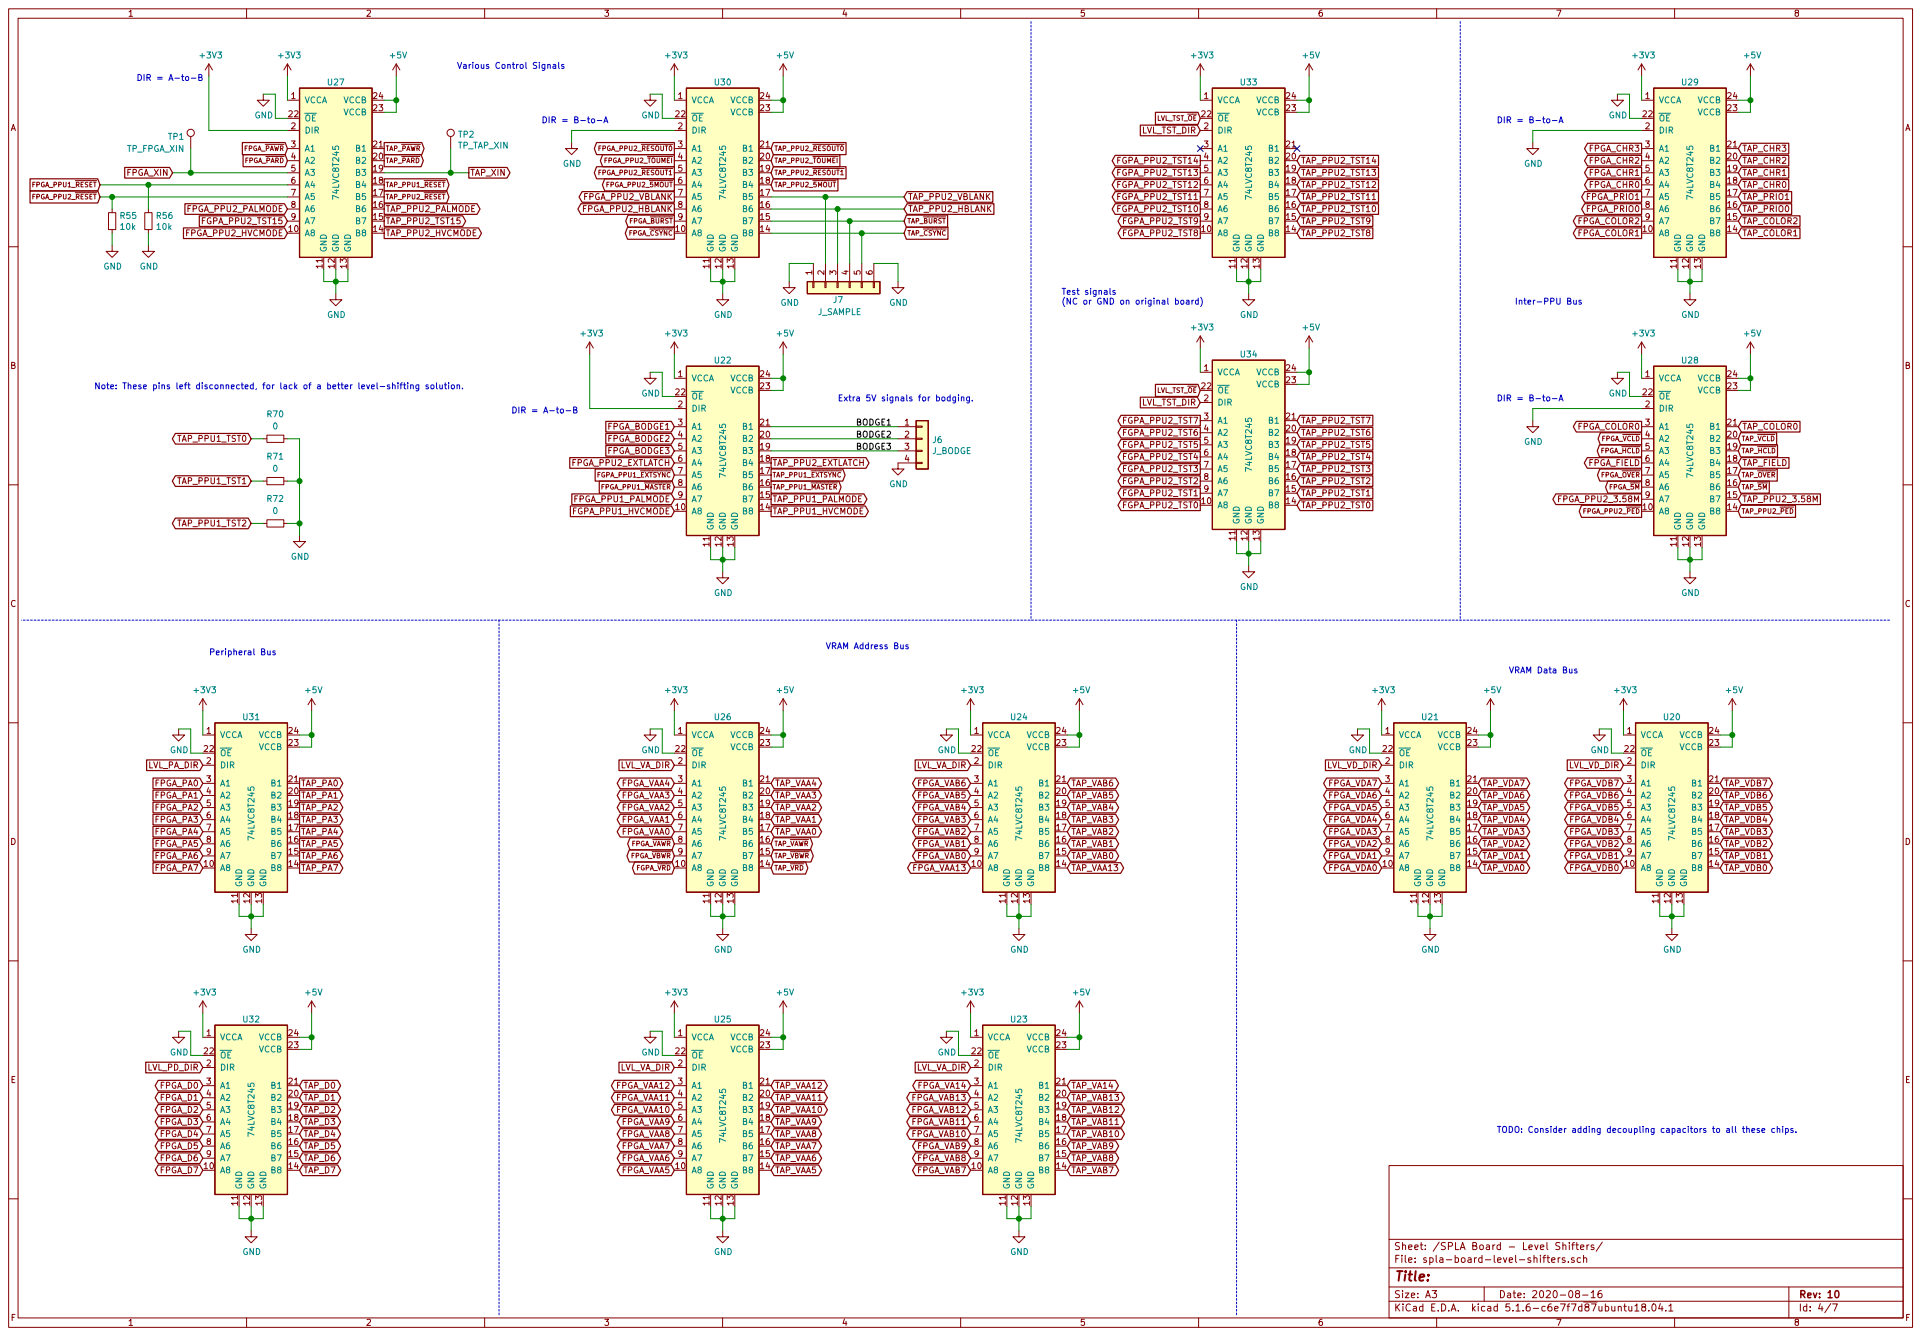
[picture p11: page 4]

(NC or GND on original board) VRAM Address Bus Extra 5V signals for bodging.

TODO: Consider adding decoupling capacitors to all these chips.

File: spla-board-level-shifters.sch Sheet: /SPLA Board - Level Shifters/

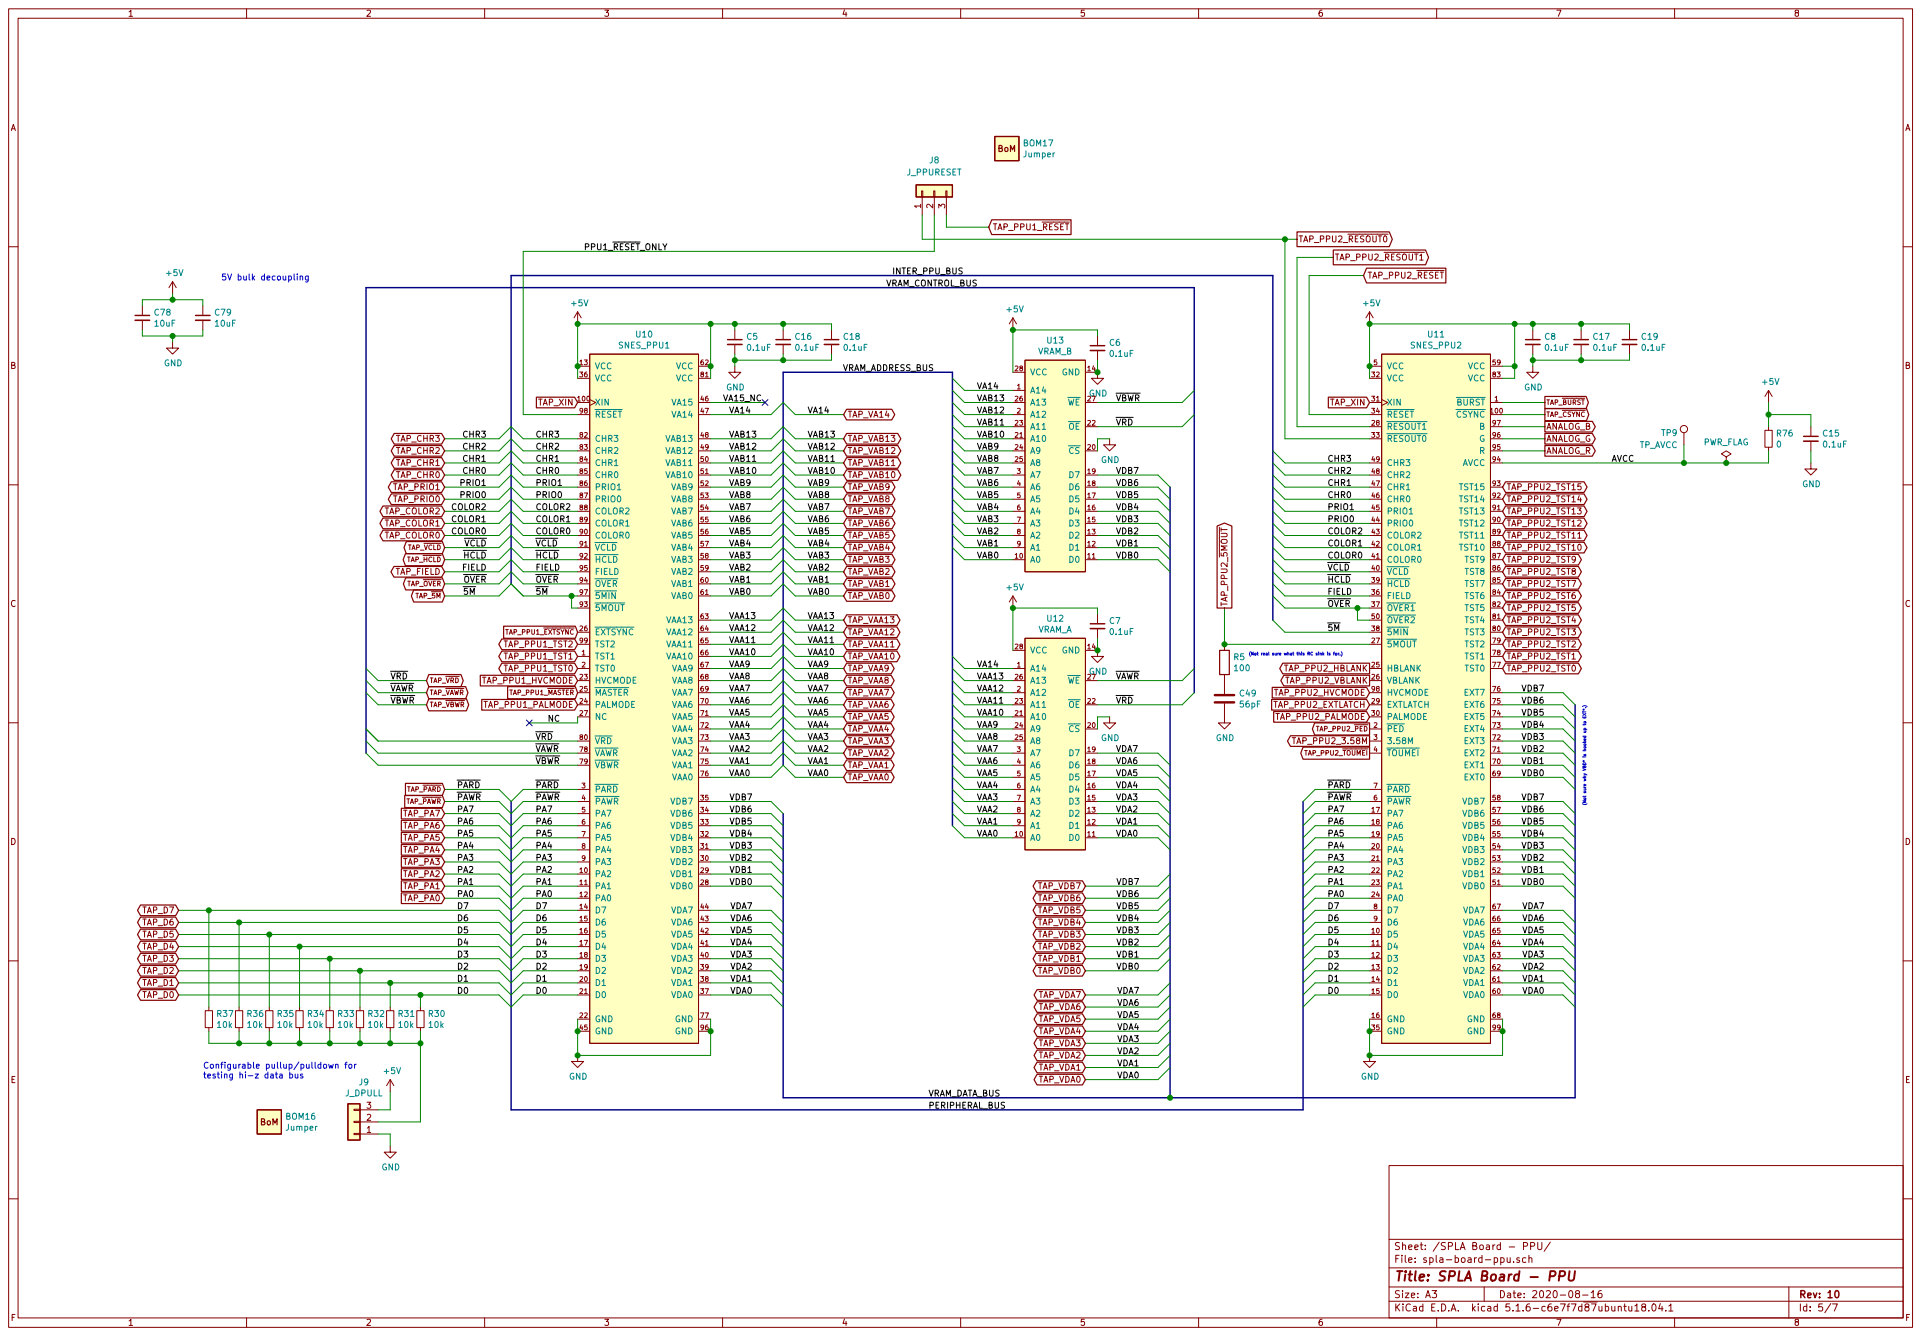
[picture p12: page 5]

(Not real sure what this RC sink is for.)

VDB0 VDB1 VDB5 VDB7 VDB4 VDB3 VDB2 Configurable pullup/pulldown for

testing hi-z data bus

File: spla-board-ppu.sch Sheet: /SPLA Board - PPU/
Id: 5/7 Title: SPLA Board - PPU

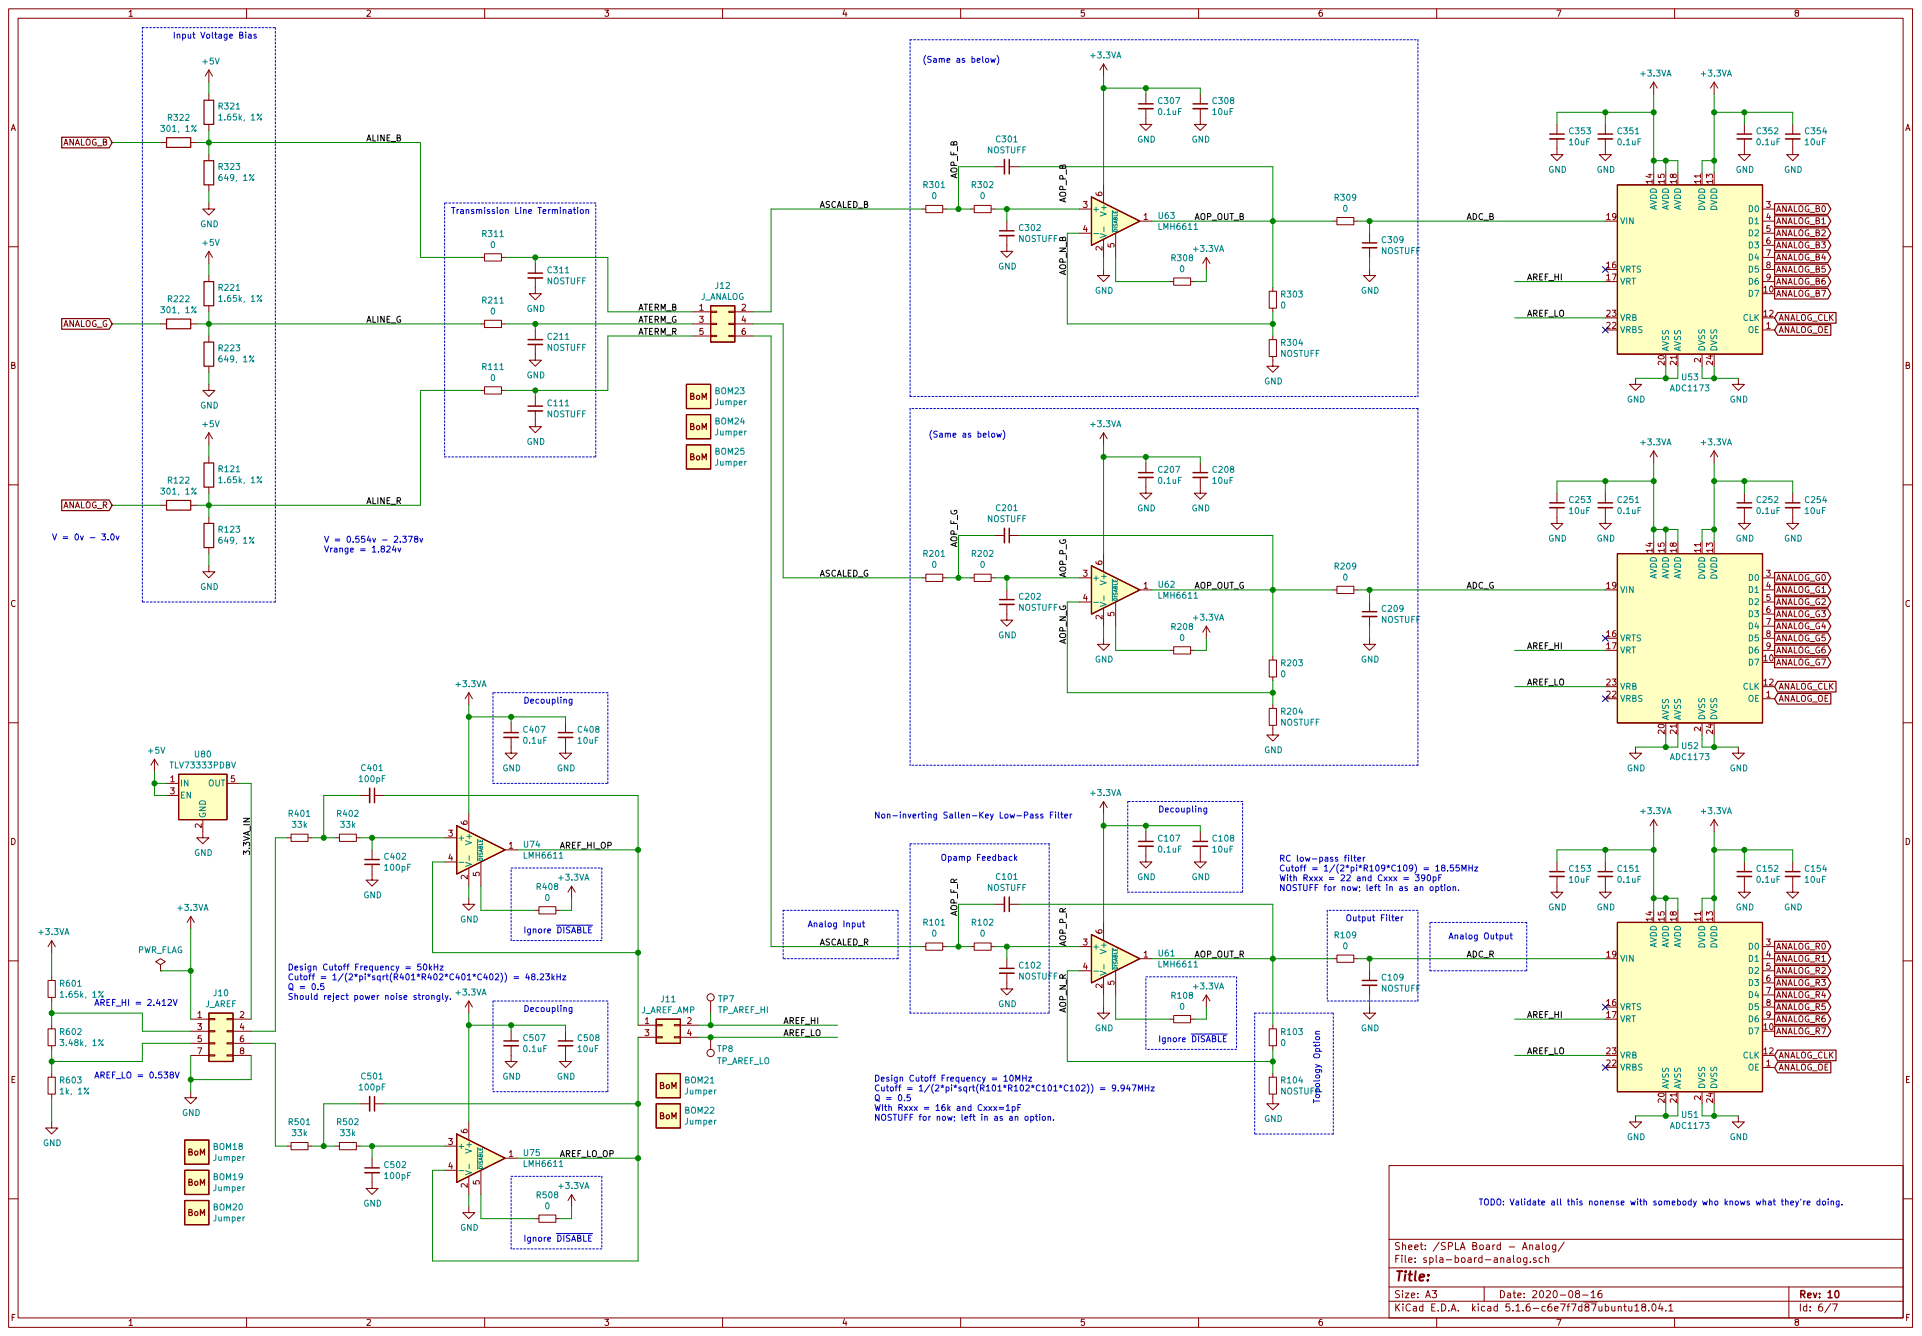
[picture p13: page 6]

2 AVSS 20 AVSS 21 VRBS 22 VRB 23 DVSS 24 D0
ANALOG_G3 ANALOG_G2 ANALOG_R0 ANALOG_G1 ANALOG_G0 ANALOG_CLK

Non-inverting Sallen-Key Low-Pass Filter V = 0.554v - 2.378v Vrange = 1.824v

RC low-pass filter
Cutoff = 1/(2*pi*R109*C109) = 18.55MHz
With Rxxx = 22 and Cxxx = 390pF
NOSTUFF for now; left in as an option.

Design Cutoff Frequency = 50kHz
Cutoff = 1/(2*pi*sqrt(R401*R402*C401*C402)) = 48.23kHz Q = 0.5 Should reject power noise strongly.

Sheet: /SPLA Board - Analog/ +3.3VA

Design Cutoff Frequency = 10MHz
Cutoff = 1/(2*pi*sqrt(R101*R102*C101*C102)) = 9.947MHz Q = 0.5 WIth Rxxx = 16k and Cxxx=1pF

TODO: Validate all this nonense with somebody who knows what they're doing.

File: spla-board-analog.sch
Id: 6/7 Title:

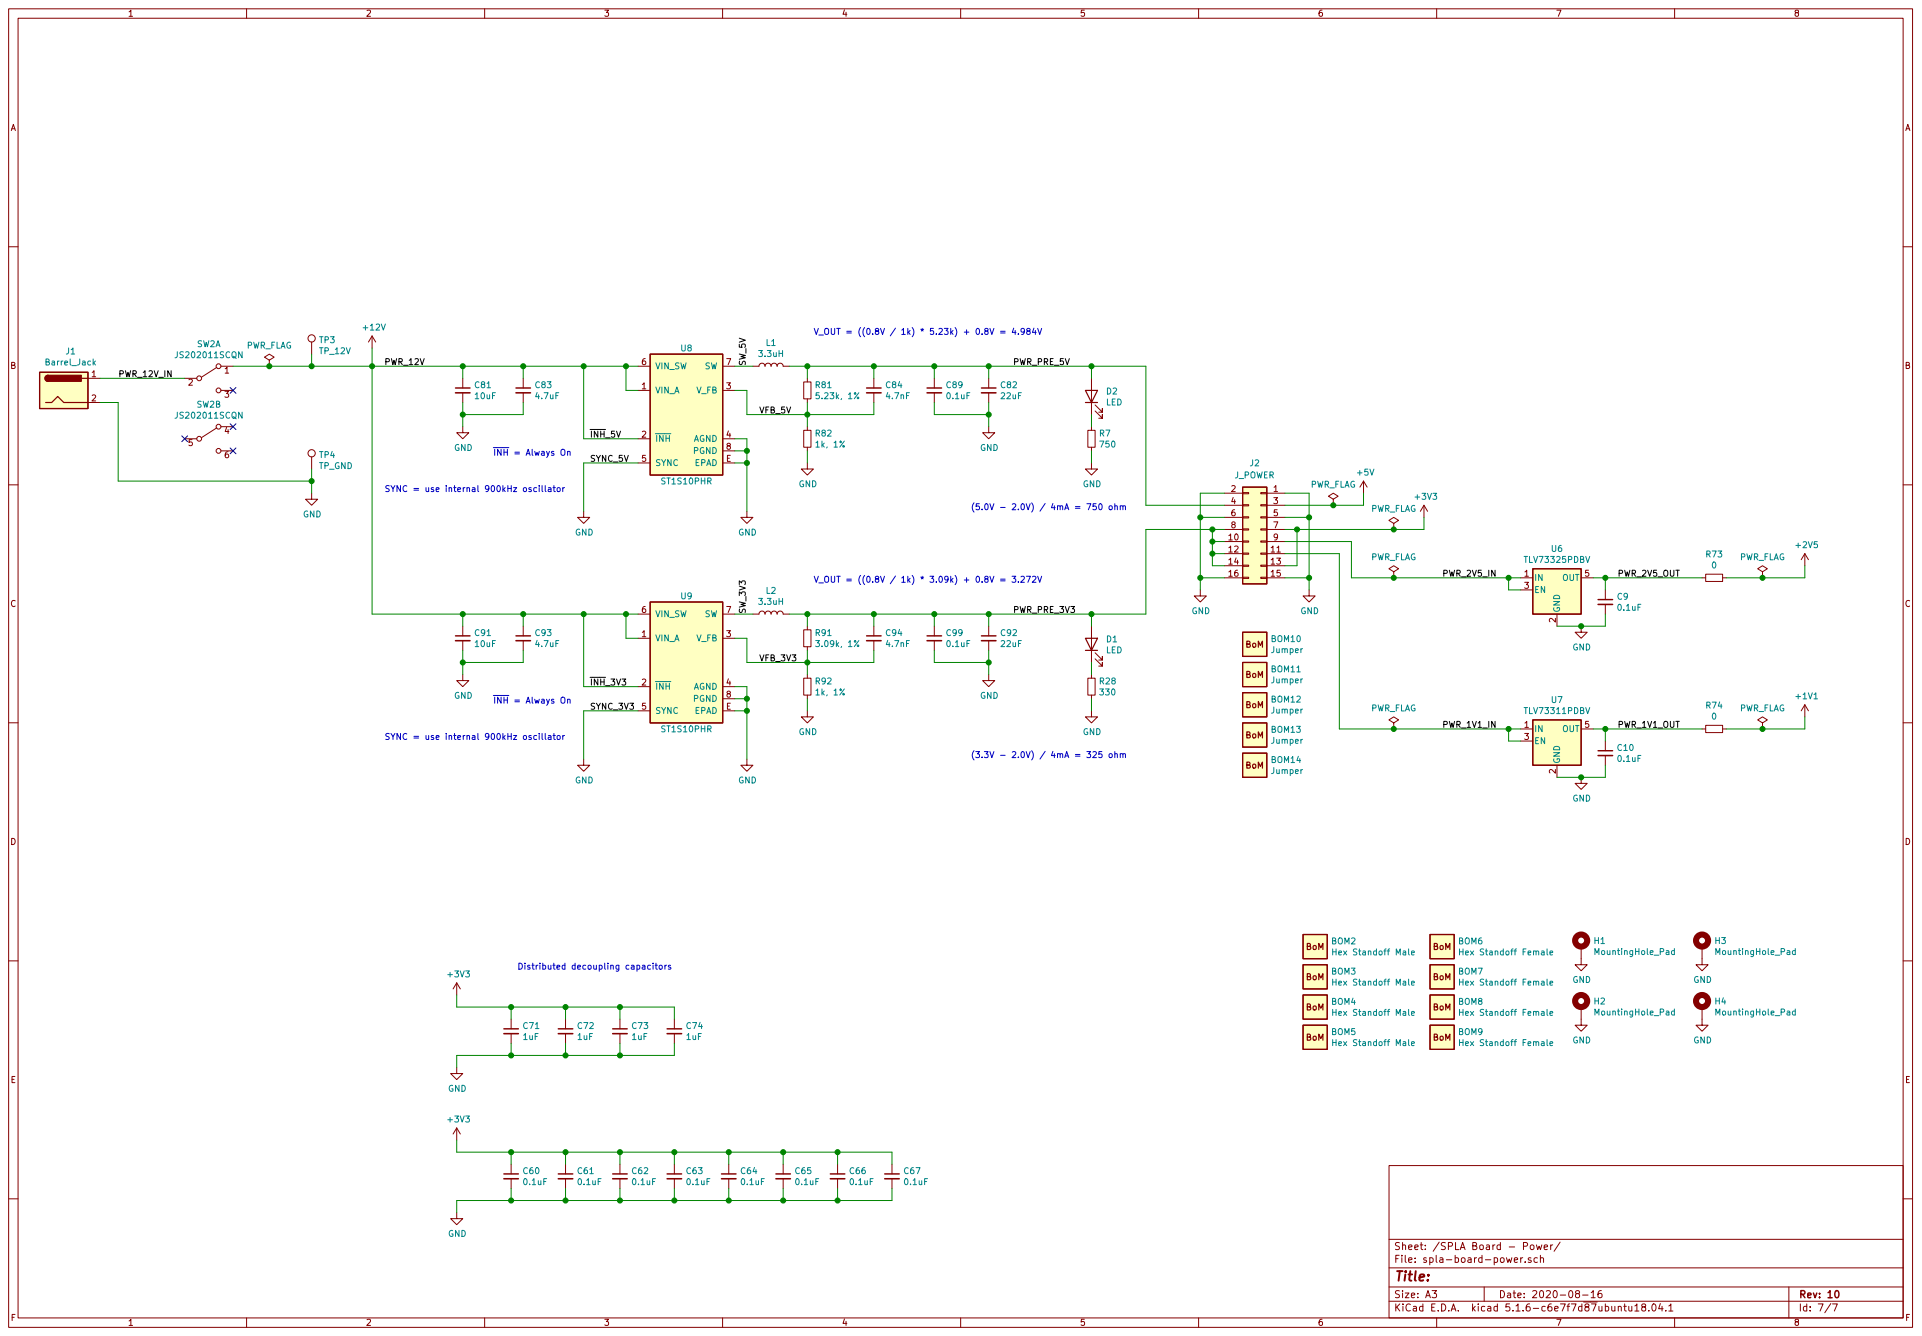
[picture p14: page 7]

10 | 9
12 | 11
14 | 13

SYNC = use internal 900kHz oscillator

File: spla-board-power.sch Sheet: /SPLA Board - Power/

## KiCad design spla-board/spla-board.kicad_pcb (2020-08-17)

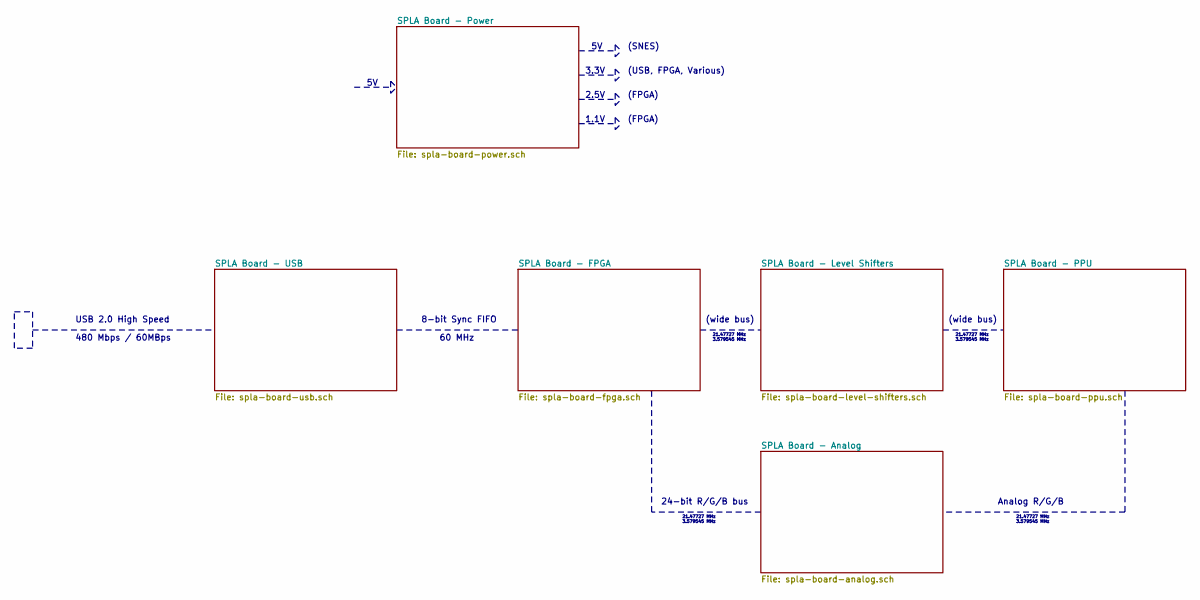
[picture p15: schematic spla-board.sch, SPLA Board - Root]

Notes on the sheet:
USB 2.0 High Speed
60 MHz
(wide bus)
Analog R/G/B
24-bit R/G/B bus
3.3V
2.5V
1.1V
(SNES)
(USB, FPGA, Various)
(FPGA)
8-bit Sync FIFO
21.47727 MHz 3.579545 MHz
480 Mbps / 60MBps

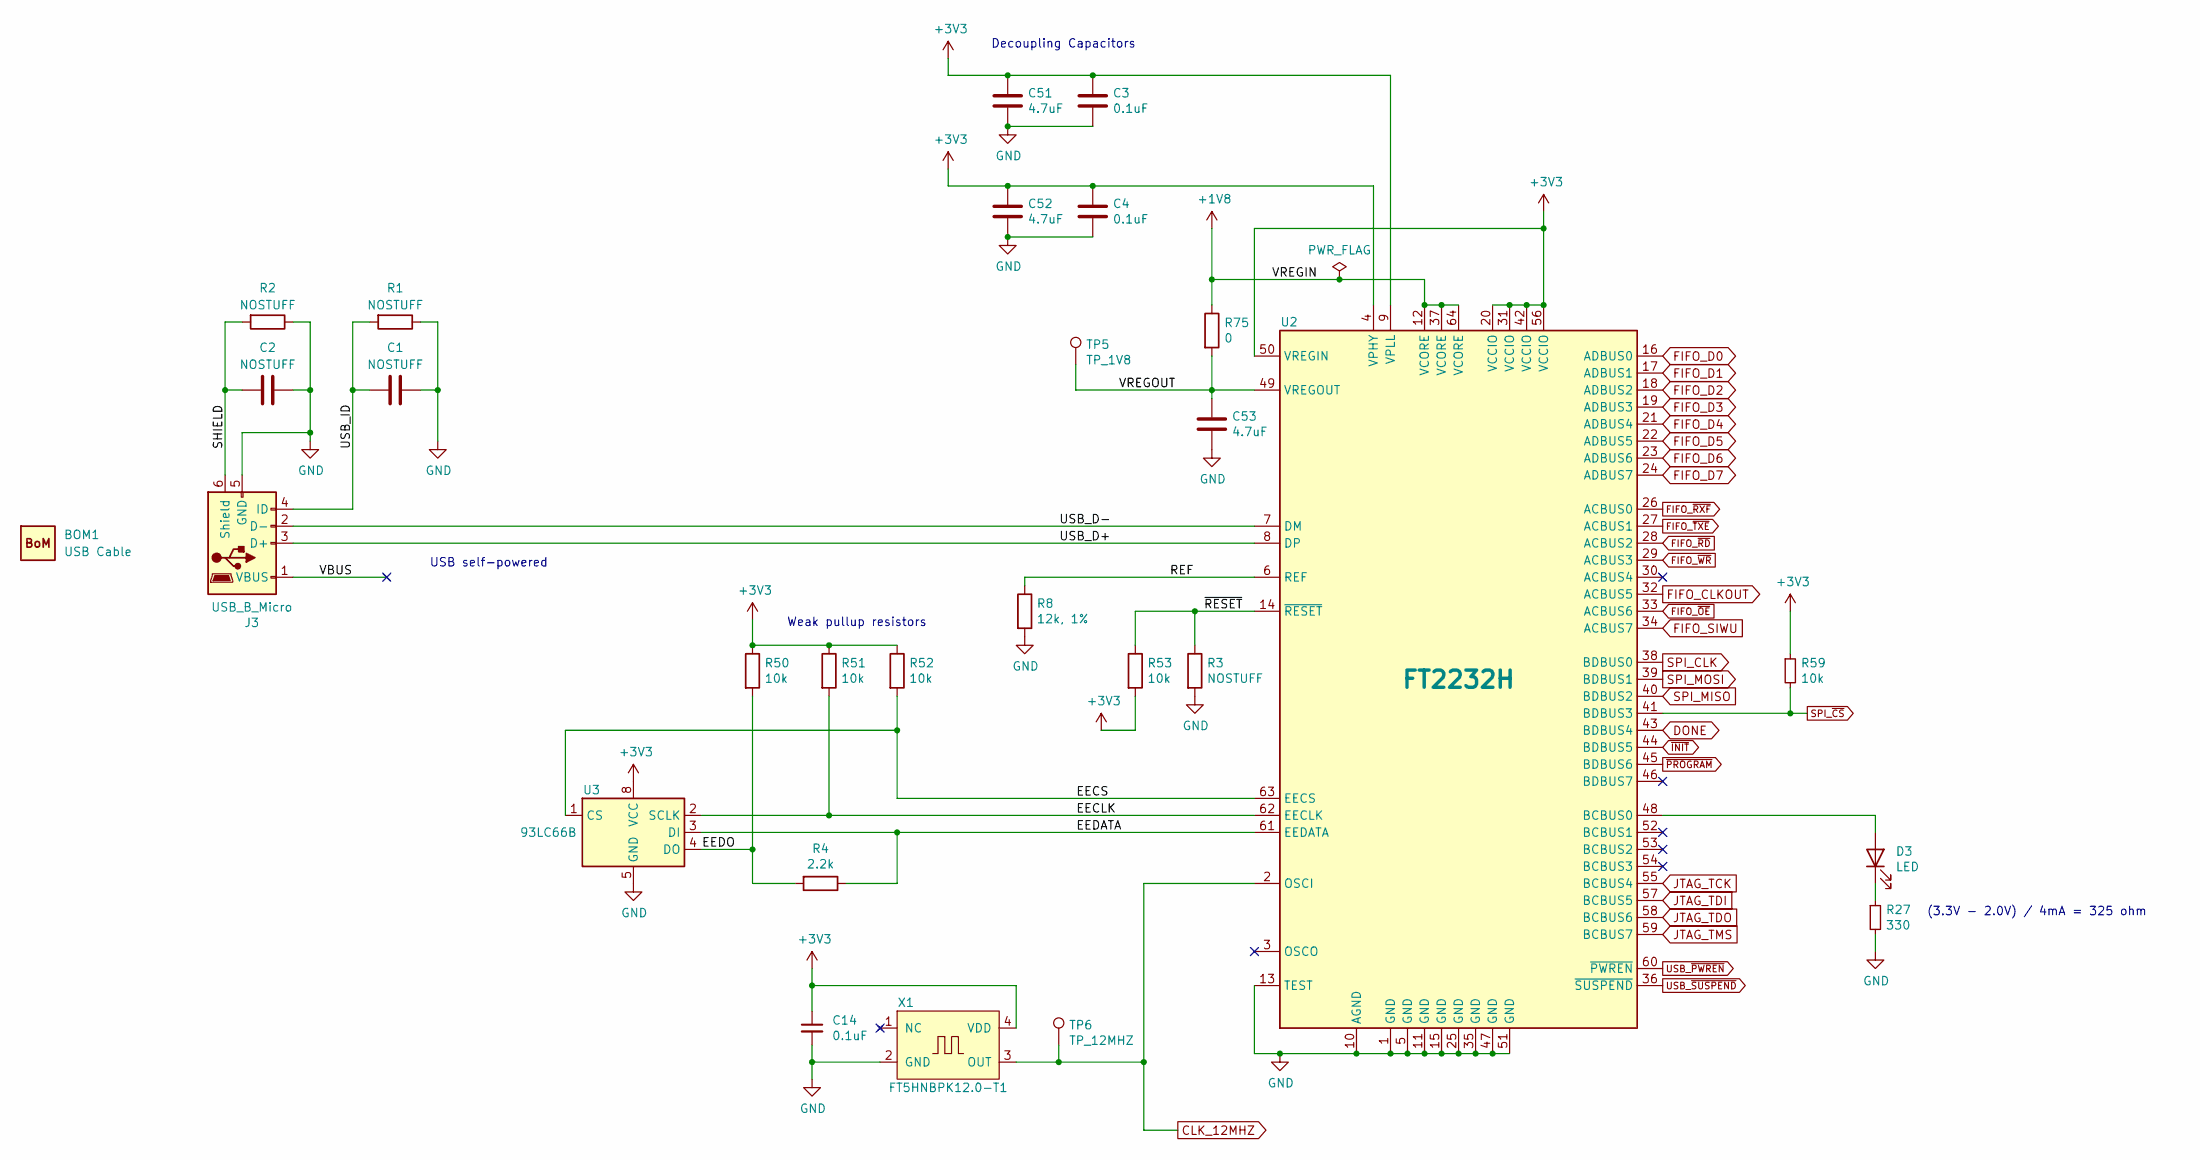
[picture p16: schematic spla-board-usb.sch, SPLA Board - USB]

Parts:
BOM1: USB Cable; BoM; Digikey Q966-ND
C1, C2: NOSTUFF; C_0603_1608Metric; Digikey N/A
C3, C4, C14: 0.1uF; C_0603_1608Metric; Digikey 490-16477-1-ND
C51, C52, C53: 4.7uF; C_0603_1608Metric; Digikey 490-7203-1-ND
D3: LED; LED_0805_2012Metric; Digikey 732-4986-1-ND
J3: USB_B_Micro; USB_Micro-B_Wuerth_629105150521; Digikey 732-5960-1-ND
R1, R2, R3: NOSTUFF; R_0603_1608Metric; Digikey N/A
R4: 2.2k; R_0603_1608Metric; Digikey RMCF0603JT2K20CT-ND
R8: 12k, 1%; R_0603_1608Metric; Digikey RMCF0603FT12K0CT-ND
R27: 330; R_0603_1608Metric; Digikey RMCF0603JT330RCT-ND
R50, R51, R52, R53, R59: 10k; R_0603_1608Metric; Digikey RMCF0603JT10K0CT-ND
R75: 0; R_0603_1608Metric; Digikey 2019-RK73Z1JTTDCT-ND
TP5: TP_1V8; TestPoint_Pad_D1.0mm; Digikey N/A
TP6: TP_12MHZ; TestPoint_Pad_D1.0mm; Digikey N/A
U2: FT2232H; LQFP-64_10x10mm_P0.5mm; Digikey 768-1024-1-ND
U3: 93LC66B; SOIC-8_3.9x4.9mm_P1.27mm; Digikey 93LC66B/SN-ND
X1: FT5HNBPK12.0-T1; Crystal_SMD_5032-4Pin_5.0x3.2mm; Digikey 631-1068-1-ND

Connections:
+1V8: R75.1, U2.12 (VCORE), U2.37 (VCORE), U2.64 (VCORE)
/SPLA Board - USB/EECLK: R51.2, U2.62 (EECLK), U3.2 (SCLK)
/SPLA Board - USB/EECS: R52.2, U2.63 (EECS), U3.1 (CS)
/SPLA Board - USB/EEDATA: R4.1, U2.61 (EEDATA), U3.3 (DI)
/SPLA Board - USB/EEDO: R4.2, R50.2, U3.4 (DO)
/SPLA Board - USB/REF: R8.1, U2.6 (REF)
/SPLA Board - USB/SHIELD: C2.2, J3.6 (Shield), R2.2
/SPLA Board - USB/USB_D+: J3.3 (D+), U2.8 (DP)
/SPLA Board - USB/USB_D-: J3.2 (D-), U2.7 (DM)
/SPLA Board - USB/USB_ID: C1.2, J3.4 (ID), R1.2
/SPLA Board - USB/VBUS: J3.1 (VBUS)
/SPLA Board - USB/VREGOUT: C53.1, R75.2, TP5.1, U2.49 (VREGOUT)
/SPLA Board - USB/~RESET: R3.1, R53.1, U2.14 (~RESET)
CLK_12MHZ: TP6.1, U2.2 (OSCI), X1.3 (OUT); also elsewhere on the board
DONE: U2.43 (BDBUS4); also elsewhere on the board
FIFO_CLKOUT: U2.32 (ACBUS5); also elsewhere on the board
FIFO_D0: U2.16 (ADBUS0); also elsewhere on the board
FIFO_D1: U2.17 (ADBUS1); also elsewhere on the board
FIFO_D2: U2.18 (ADBUS2); also elsewhere on the board
FIFO_D3: U2.19 (ADBUS3); also elsewhere on the board
FIFO_D4: U2.21 (ADBUS4); also elsewhere on the board
FIFO_D5: U2.22 (ADBUS5); also elsewhere on the board
FIFO_D6: U2.23 (ADBUS6); also elsewhere on the board
FIFO_D7: U2.24 (ADBUS7); also elsewhere on the board
FIFO_SIWU: U2.34 (ACBUS7); also elsewhere on the board
FIFO_~OE~: U2.33 (ACBUS6); also elsewhere on the board
FIFO_~RD~: U2.28 (ACBUS2); also elsewhere on the board
FIFO_~RXF~: U2.26 (ACBUS0); also elsewhere on the board
FIFO_~TXE~: U2.27 (ACBUS1); also elsewhere on the board
FIFO_~WR~: U2.29 (ACBUS3); also elsewhere on the board
GND: C1.1, C2.1, C3.2, C4.2, C14.2, C51.2, C52.2, C53.2, J3.5 (GND), R1.1, R2.1, R3.2, R8.2, R27.2, U2.1 (GND), U2.5 (GND), U2.10 (AGND), U2.11 (GND), U2.13 (TEST), U2.15 (GND), U2.25 (GND), U2.35 (GND), U2.47 (GND), U2.51 (GND), U3.5 (GND), X1.2 (GND); also elsewhere on the board
JTAG_TCK: U2.55 (BCBUS4); also elsewhere on the board
JTAG_TDI: U2.57 (BCBUS5); also elsewhere on the board
JTAG_TDO: U2.58 (BCBUS6); also elsewhere on the board
JTAG_TMS: U2.59 (BCBUS7); also elsewhere on the board
unnamed: D3.1 (K), R27.1
unnamed: D3.2 (A), U2.48 (BCBUS0)
SPI_CLK: U2.38 (BDBUS0); also elsewhere on the board
SPI_MISO: U2.40 (BDBUS2); also elsewhere on the board
SPI_MOSI: U2.39 (BDBUS1); also elsewhere on the board
SPI_~CS~: R59.2, U2.41 (BDBUS3); also elsewhere on the board
USB_~PWREN~: U2.60 (~PWREN); also elsewhere on the board
USB_~SUSPEND~: U2.36 (~SUSPEND); also elsewhere on the board
~INIT: U2.44 (BDBUS5); also elsewhere on the board
~PROGRAM: U2.45 (BDBUS6); also elsewhere on the board

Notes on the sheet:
Weak pullup resistors
Decoupling Capacitors
USB self-powered
(3.3V - 2.0V) / 4mA = 325 ohm

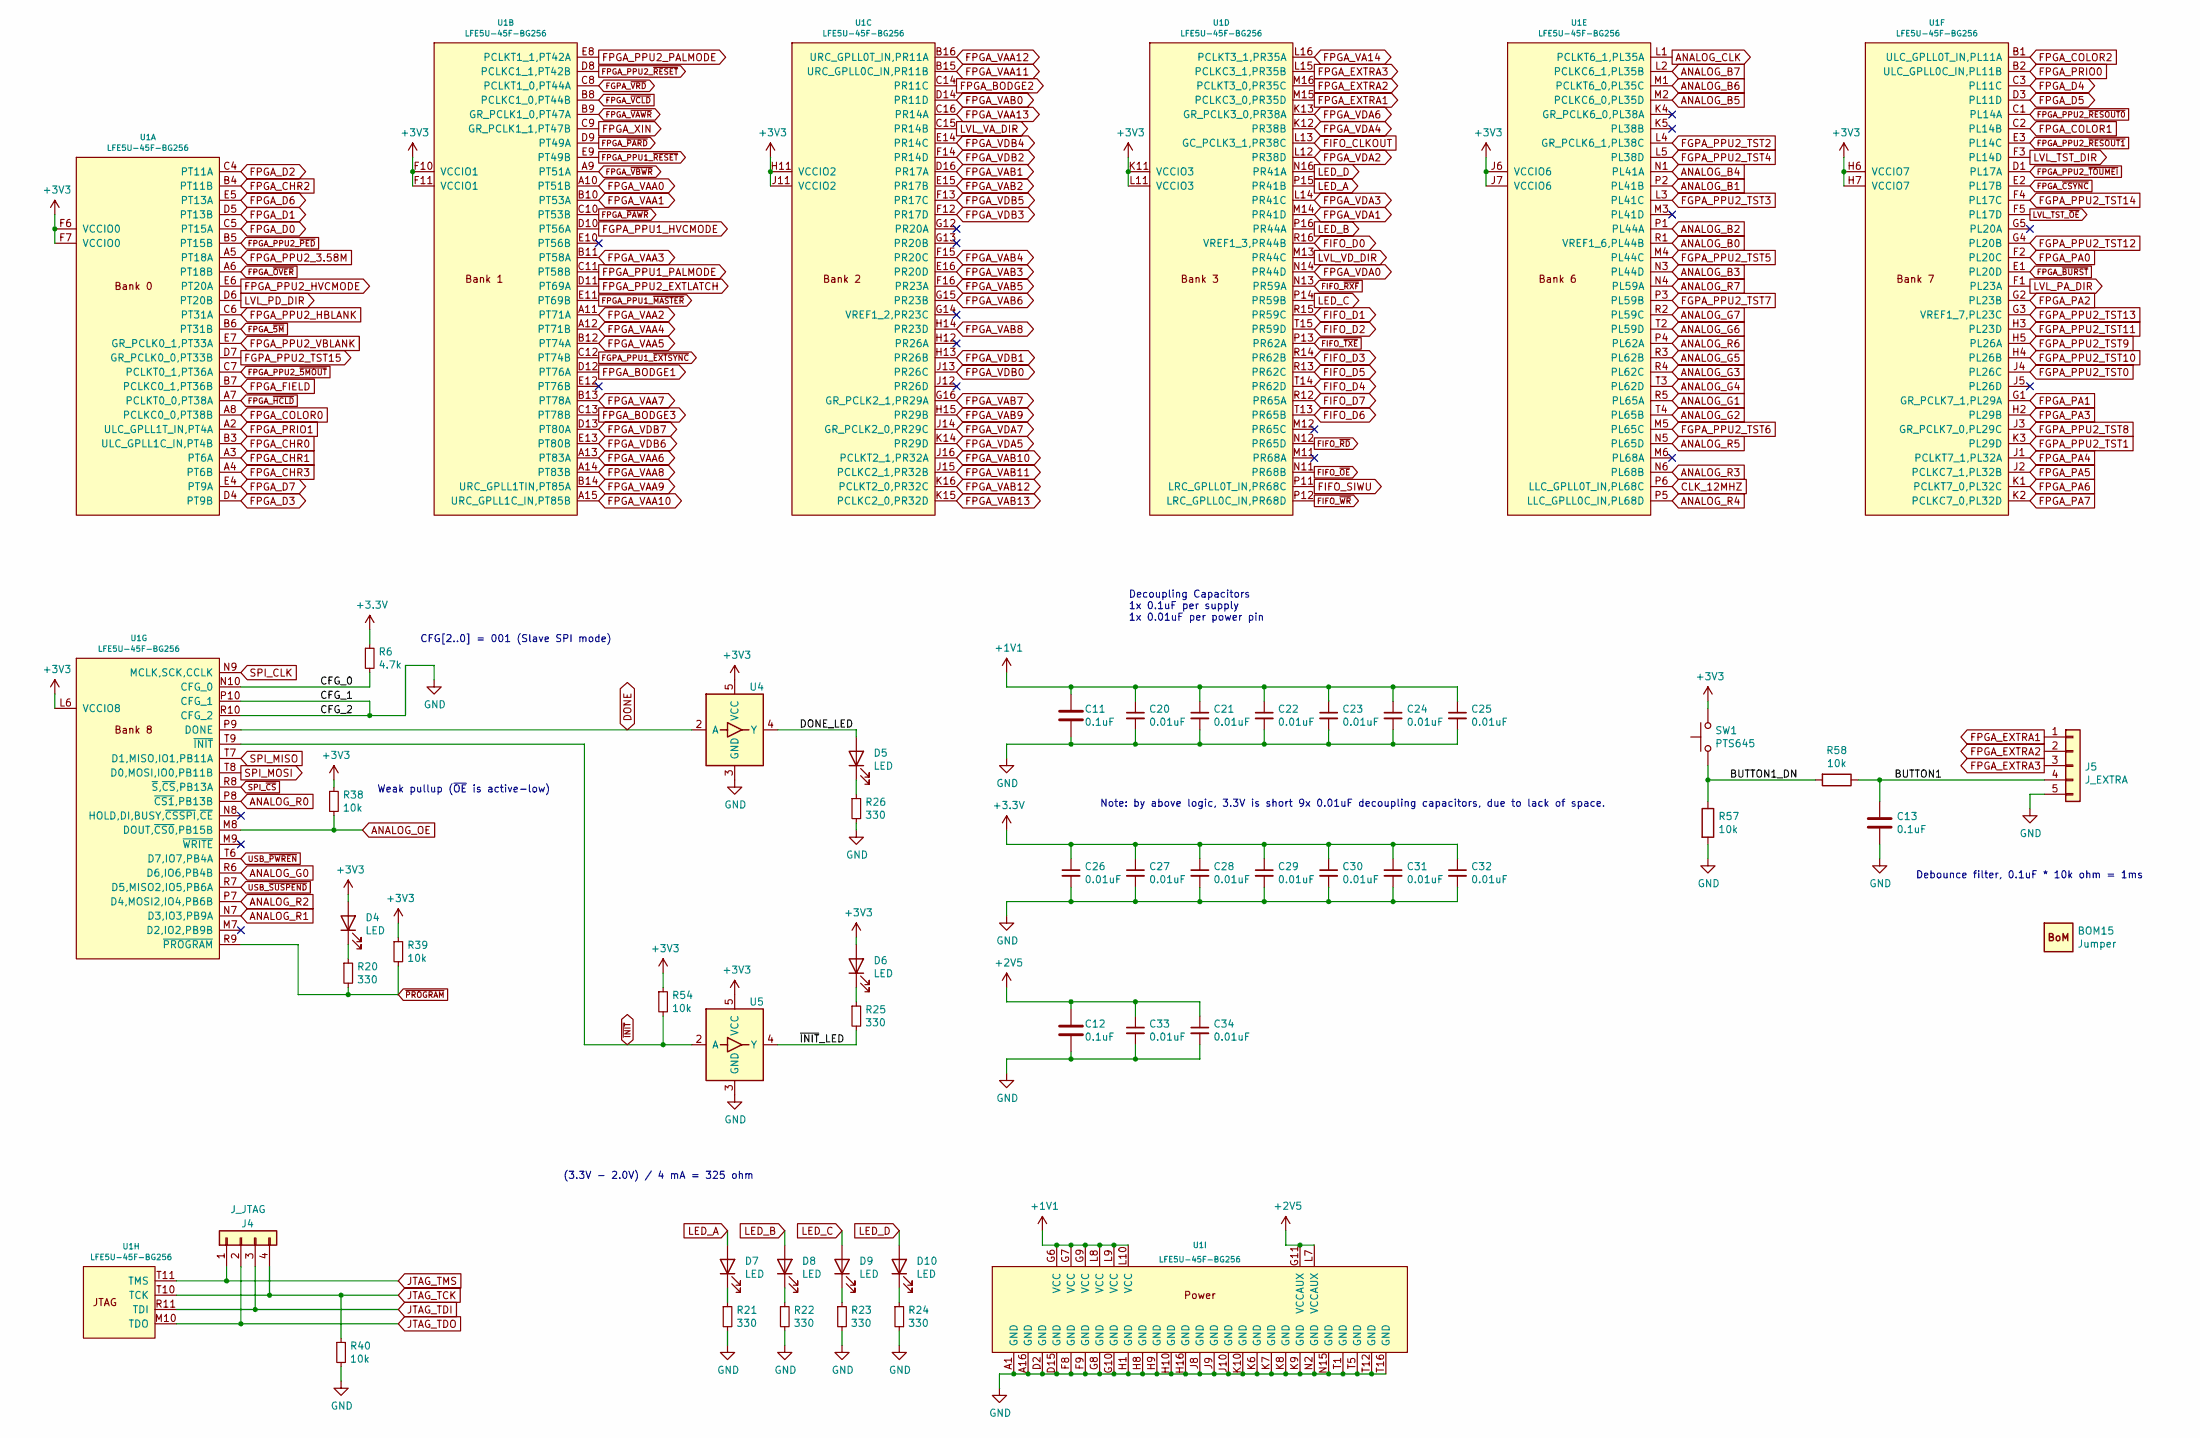
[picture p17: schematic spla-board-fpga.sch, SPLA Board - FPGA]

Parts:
BOM15: Jumper; BoM; Digikey S9337-ND
C11, C12, C13: 0.1uF; C_0603_1608Metric; Digikey 490-16477-1-ND
C20, C21, C22, C23, C24, C25, C26, C27, C28, C29, C30, C31, C32, C33, C34: 0.01uF; C_0402_1005Metric; Digikey 490-6351-1-ND
D4, D5, D6, D7, D8, D9, D10: LED; LED_0805_2012Metric; Digikey 732-4986-1-ND
J4: J_JTAG; PinHeader_1x04_P2.54mm_Vertical; Digikey S1011EC-40-ND
J5: J_EXTRA; PinHeader_1x05_P2.54mm_Vertical; Digikey S1011EC-40-ND
R6: 4.7k; R_0402_1005Metric; Digikey RMCF0402FT4K70CT-ND
R20, R21, R22, R23, R24, R25, R26: 330; R_0603_1608Metric; Digikey RMCF0603JT330RCT-ND
R38, R39, R40, R54, R57, R58: 10k; R_0603_1608Metric; Digikey RMCF0603JT10K0CT-ND
SW1: PTS645; PTS645-SMTR92; Digikey CKN9088CT-ND
U1: LFE5U-45F-BG256; BGA-256_14.0x14.0mm_Layout16x16_P0.8mm_Ball0.45mm_Pad0.32mm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; Digikey 220-2198-ND
U4, U5: 74LVC1G17; SOT-353_SC-70-5; Digikey 1727-4117-1-ND

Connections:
+1V1: C11.1, C20.1, C21.1, C22.1, C23.1, C24.1, C25.1, U1.G6 (VCC), U1.G7 (VCC), U1.G9 (VCC), U1.L8 (VCC), U1.L9 (VCC), U1.L10 (VCC); also elsewhere on the board
+2V5: C12.1, C33.1, C34.1, U1.G11 (VCCAUX), U1.L7 (VCCAUX); also elsewhere on the board
/SPLA Board - FPGA/BUTTON1: C13.1, J5.4, R58.1
/SPLA Board - FPGA/BUTTON1_DN: R57.1, R58.2, SW1.1
/SPLA Board - FPGA/CFG_0: R6.2, U1.N10 (CFG_0)
/SPLA Board - FPGA/DONE_LED: D5.2 (A), U4.4 (Y)
/SPLA Board - FPGA/~INIT~_LED: R25.2, U5.4 (Y)
ANALOG_B0: U1.R1 (VREF1_6,PL44B); also elsewhere on the board
ANALOG_B1: U1.P2 (PL41B); also elsewhere on the board
ANALOG_B2: U1.P1 (PL44A); also elsewhere on the board
ANALOG_B3: U1.N3 (PL44D); also elsewhere on the board
ANALOG_B4: U1.N1 (PL41A); also elsewhere on the board
ANALOG_B5: U1.M2 (PCLKC6_0,PL35D); also elsewhere on the board
ANALOG_B6: U1.M1 (PCLKT6_0,PL35C); also elsewhere on the board
ANALOG_B7: U1.L2 (PCLKC6_1,PL35B); also elsewhere on the board
ANALOG_CLK: U1.L1 (PCLKT6_1,PL35A); also elsewhere on the board
ANALOG_G0: U1.R6 (D6,IO6,PB4B); also elsewhere on the board
ANALOG_G1: U1.R5 (PL65A); also elsewhere on the board
ANALOG_G2: U1.T4 (PL65B); also elsewhere on the board
ANALOG_G3: U1.R4 (PL62C); also elsewhere on the board
ANALOG_G4: U1.T3 (PL62D); also elsewhere on the board
ANALOG_G5: U1.R3 (PL62B); also elsewhere on the board
ANALOG_G6: U1.T2 (PL59D); also elsewhere on the board
ANALOG_G7: U1.R2 (PL59C); also elsewhere on the board
ANALOG_OE: R38.2, U1.M8 (DOUT,~CS0~,PB15B); also elsewhere on the board
ANALOG_R0: U1.P8 (~CS1~,PB13B); also elsewhere on the board
ANALOG_R1: U1.N7 (D3,IO3,PB9A); also elsewhere on the board
ANALOG_R2: U1.P7 (D4,MOSI2,IO4,PB6B); also elsewhere on the board
ANALOG_R3: U1.N6 (PL68B); also elsewhere on the board
ANALOG_R4: U1.P5 (LLC_GPLL0C_IN,PL68D); also elsewhere on the board
ANALOG_R5: U1.N5 (PL65D); also elsewhere on the board
ANALOG_R6: U1.P4 (PL62A); also elsewhere on the board
ANALOG_R7: U1.N4 (PL59A); also elsewhere on the board
CLK_12MHZ: U1.P6 (LLC_GPLL0T_IN,PL68C); also elsewhere on the board
DONE: U1.P9 (DONE), U4.2 (A); also elsewhere on the board
FGPA_PPU1_HVCMODE: U1.D10 (PT56A); also elsewhere on the board
FGPA_PPU1_~EXTSYNC~: U1.C12 (PT74B); also elsewhere on the board
FGPA_PPU2_TST0: U1.J4 (PL26C); also elsewhere on the board
FGPA_PPU2_TST1: U1.K3 (PL29D); also elsewhere on the board
FGPA_PPU2_TST2: U1.L4 (GR_PCLK6_1,PL38C); also elsewhere on the board
FGPA_PPU2_TST3: U1.L3 (PL41C); also elsewhere on the board
FGPA_PPU2_TST4: U1.L5 (PL38D); also elsewhere on the board
FGPA_PPU2_TST5: U1.M4 (PL44C); also elsewhere on the board
FGPA_PPU2_TST6: U1.M5 (PL65C); also elsewhere on the board
FGPA_PPU2_TST7: U1.P3 (PL59B); also elsewhere on the board
FGPA_PPU2_TST8: U1.J3 (GR_PCLK7_0,PL29C); also elsewhere on the board
FGPA_PPU2_TST9: U1.H5 (PL26A); also elsewhere on the board
FGPA_PPU2_TST10: U1.H4 (PL26B); also elsewhere on the board
FGPA_PPU2_TST11: U1.H3 (PL23D); also elsewhere on the board
FGPA_PPU2_TST12: U1.G4 (PL20B); also elsewhere on the board
FGPA_PPU2_TST13: U1.G3 (VREF1_7,PL23C); also elsewhere on the board
FGPA_PPU2_TST14: U1.F4 (PL17C); also elsewhere on the board
FGPA_PPU2_TST15: U1.D7 (GR_PCLK0_0,PT33B); also elsewhere on the board
FGPA_~VRD~: U1.C8 (PCLKT1_0,PT44A); also elsewhere on the board
FIFO_CLKOUT: U1.L13 (GC_PCLK3_1,PR38C); also elsewhere on the board
FIFO_D0: U1.R16 (VREF1_3,PR44B); also elsewhere on the board
FIFO_D1: U1.R15 (PR59C); also elsewhere on the board
FIFO_D2: U1.T15 (PR59D); also elsewhere on the board
FIFO_D3: U1.R14 (PR62B); also elsewhere on the board
FIFO_D4: U1.T14 (PR62D); also elsewhere on the board
FIFO_D5: U1.R13 (PR62C); also elsewhere on the board
FIFO_D6: U1.T13 (PR65B); also elsewhere on the board
FIFO_D7: U1.R12 (PR65A); also elsewhere on the board
FIFO_SIWU: U1.P11 (LRC_GPLL0T_IN,PR68C); also elsewhere on the board
FIFO_~OE~: U1.N11 (PR68B); also elsewhere on the board
FIFO_~RD~: U1.N12 (PR65D); also elsewhere on the board
FIFO_~RXF~: U1.N13 (PR59A); also elsewhere on the board
FIFO_~TXE~: U1.P13 (PR62A); also elsewhere on the board
FIFO_~WR~: U1.P12 (LRC_GPLL0C_IN,PR68D); also elsewhere on the board
FPGA_BODGE1: U1.D12 (PT76A); also elsewhere on the board
FPGA_BODGE2: U1.C14 (PR11C); also elsewhere on the board
FPGA_BODGE3: U1.C13 (PT78B); also elsewhere on the board
FPGA_CHR0: U1.B3 (ULC_GPLL1C_IN,PT4B); also elsewhere on the board
FPGA_CHR1: U1.A3 (PT6A); also elsewhere on the board
FPGA_CHR2: U1.B4 (PT11B); also elsewhere on the board
FPGA_CHR3: U1.A4 (PT6B); also elsewhere on the board
FPGA_COLOR0: U1.A8 (PCLKC0_0,PT38B); also elsewhere on the board
FPGA_COLOR1: U1.C2 (PL14B); also elsewhere on the board
FPGA_COLOR2: U1.B1 (ULC_GPLL0T_IN,PL11A); also elsewhere on the board
FPGA_D0: U1.C5 (PT15A); also elsewhere on the board
FPGA_D1: U1.D5 (PT13B); also elsewhere on the board
FPGA_D2: U1.C4 (PT11A); also elsewhere on the board
FPGA_D3: U1.D4 (PT9B); also elsewhere on the board
FPGA_D4: U1.C3 (PL11C); also elsewhere on the board
FPGA_D5: U1.D3 (PL11D); also elsewhere on the board
FPGA_D6: U1.E5 (PT13A); also elsewhere on the board
FPGA_D7: U1.E4 (PT9A); also elsewhere on the board
FPGA_EXTRA1: J5.1, U1.M15 (PCLKC3_0,PR35D)
FPGA_EXTRA2: J5.2, U1.M16 (PCLKT3_0,PR35C)
FPGA_EXTRA3: J5.3, U1.L15 (PCLKC3_1,PR35B)
FPGA_FIELD: U1.B7 (PCLKC0_1,PT36B); also elsewhere on the board
FPGA_PA0: U1.F2 (PL20C); also elsewhere on the board
FPGA_PA1: U1.G1 (GR_PCLK7_1,PL29A); also elsewhere on the board
FPGA_PA2: U1.G2 (PL23B); also elsewhere on the board
FPGA_PA3: U1.H2 (PL29B); also elsewhere on the board
FPGA_PA4: U1.J1 (PCLKT7_1,PL32A); also elsewhere on the board
FPGA_PA5: U1.J2 (PCLKC7_1,PL32B); also elsewhere on the board
FPGA_PA6: U1.K1 (PCLKT7_0,PL32C); also elsewhere on the board
FPGA_PA7: U1.K2 (PCLKC7_0,PL32D); also elsewhere on the board
FPGA_PPU1_PALMODE: U1.C11 (PT58B); also elsewhere on the board
FPGA_PPU1_~MASTER~: U1.E11 (PT69B); also elsewhere on the board
FPGA_PPU1_~RESET~: U1.E9 (PT49B); also elsewhere on the board
FPGA_PPU2_3.58M: U1.A5 (PT18A); also elsewhere on the board
FPGA_PPU2_EXTLATCH: U1.D11 (PT69A); also elsewhere on the board
FPGA_PPU2_HBLANK: U1.C6 (PT31A); also elsewhere on the board
FPGA_PPU2_HVCMODE: U1.E6 (PT20A); also elsewhere on the board
FPGA_PPU2_PALMODE: U1.E8 (PCLKT1_1,PT42A); also elsewhere on the board
FPGA_PPU2_VBLANK: U1.E7 (GR_PCLK0_1,PT33A); also elsewhere on the board
FPGA_PPU2_~5MOUT~: U1.C7 (PCLKT0_1,PT36A); also elsewhere on the board
FPGA_PPU2_~PED~: U1.B5 (PT15B); also elsewhere on the board
FPGA_PPU2_~RESET~: U1.D8 (PCLKC1_1,PT42B); also elsewhere on the board
FPGA_PPU2_~RESOUT0~: U1.C1 (PL14A); also elsewhere on the board
FPGA_PPU2_~RESOUT1~: U1.E3 (PL14C); also elsewhere on the board
FPGA_PPU2_~TOUMEI~: U1.D1 (PL17A); also elsewhere on the board
FPGA_PRIO0: U1.B2 (ULC_GPLL0C_IN,PL11B); also elsewhere on the board
FPGA_PRIO1: U1.A2 (ULC_GPLL1T_IN,PT4A); also elsewhere on the board
FPGA_VA14: U1.L16 (PCLKT3_1,PR35A); also elsewhere on the board
FPGA_VAA0: U1.A10 (PT51B); also elsewhere on the board
FPGA_VAA1: U1.B10 (PT53A); also elsewhere on the board
FPGA_VAA2: U1.A11 (PT71A); also elsewhere on the board
FPGA_VAA3: U1.B11 (PT58A); also elsewhere on the board
FPGA_VAA4: U1.A12 (PT71B); also elsewhere on the board
FPGA_VAA5: U1.B12 (PT74A); also elsewhere on the board
FPGA_VAA6: U1.A13 (PT83A); also elsewhere on the board
FPGA_VAA7: U1.B13 (PT78A); also elsewhere on the board
FPGA_VAA8: U1.A14 (PT83B); also elsewhere on the board
FPGA_VAA9: U1.B14 (URC_GPLL1TIN,PT85A); also elsewhere on the board
FPGA_VAA10: U1.A15 (URC_GPLL1C_IN,PT85B); also elsewhere on the board
FPGA_VAA11: U1.B15 (URC_GPLL0C_IN,PR11B); also elsewhere on the board
FPGA_VAA12: U1.B16 (URC_GPLL0T_IN,PR11A); also elsewhere on the board
FPGA_VAA13: U1.C16 (PR14A); also elsewhere on the board
FPGA_VAB0: U1.D14 (PR11D); also elsewhere on the board
FPGA_VAB1: U1.D16 (PR17A); also elsewhere on the board
FPGA_VAB2: U1.E15 (PR17B); also elsewhere on the board
FPGA_VAB3: U1.E16 (PR20D); also elsewhere on the board
FPGA_VAB4: U1.F15 (PR20C); also elsewhere on the board
FPGA_VAB5: U1.F16 (PR23A); also elsewhere on the board
FPGA_VAB6: U1.G15 (PR23B); also elsewhere on the board
FPGA_VAB7: U1.G16 (GR_PCLK2_1,PR29A); also elsewhere on the board
FPGA_VAB8: U1.H14 (PR23D); also elsewhere on the board
FPGA_VAB9: U1.H15 (PR29B); also elsewhere on the board
FPGA_VAB10: U1.J16 (PCLKT2_1,PR32A); also elsewhere on the board
FPGA_VAB11: U1.J15 (PCLKC2_1,PR32B); also elsewhere on the board
FPGA_VAB12: U1.K16 (PCLKT2_0,PR32C); also elsewhere on the board
FPGA_VAB13: U1.K15 (PCLKC2_0,PR32D); also elsewhere on the board
FPGA_VDA0: U1.N14 (PR44D); also elsewhere on the board
FPGA_VDA1: U1.M14 (PR41D); also elsewhere on the board
FPGA_VDA2: U1.L12 (PR38D); also elsewhere on the board
FPGA_VDA3: U1.L14 (PR41C); also elsewhere on the board
FPGA_VDA4: U1.K12 (PR38B); also elsewhere on the board
FPGA_VDA5: U1.K14 (PR29D); also elsewhere on the board
FPGA_VDA6: U1.K13 (GR_PCLK3_0,PR38A); also elsewhere on the board
FPGA_VDA7: U1.J14 (GR_PCLK2_0,PR29C); also elsewhere on the board
FPGA_VDB0: U1.J13 (PR26C); also elsewhere on the board
FPGA_VDB1: U1.H13 (PR26B); also elsewhere on the board
FPGA_VDB2: U1.F14 (PR14D); also elsewhere on the board
FPGA_VDB3: U1.F12 (PR17D); also elsewhere on the board
FPGA_VDB4: U1.E14 (PR14C); also elsewhere on the board
FPGA_VDB5: U1.F13 (PR17C); also elsewhere on the board
FPGA_VDB6: U1.E13 (PT80B); also elsewhere on the board
FPGA_VDB7: U1.D13 (PT80A); also elsewhere on the board
FPGA_XIN: U1.C9 (GR_PCLK1_1,PT47B); also elsewhere on the board
FPGA_~5M~: U1.B6 (PT31B); also elsewhere on the board
FPGA_~BURST~: U1.E1 (PL20D); also elsewhere on the board
FPGA_~CSYNC~: U1.E2 (PL17B); also elsewhere on the board
FPGA_~HCLD: U1.A7 (PCLKT0_0,PT38A); also elsewhere on the board
FPGA_~OVER~: U1.A6 (PT18B); also elsewhere on the board
FPGA_~PARD~: U1.D9 (PT49A); also elsewhere on the board
FPGA_~PAWR~: U1.C10 (PT53B); also elsewhere on the board
FPGA_~VAWR~: U1.B9 (GR_PCLK1_0,PT47A); also elsewhere on the board
FPGA_~VBWR~: U1.A9 (PT51A); also elsewhere on the board
FPGA_~VCLD~: U1.B8 (PCLKC1_0,PT44B); also elsewhere on the board
GND: C11.2, C12.2, C13.2, C20.2, C21.2, C22.2, C23.2, C24.2, C25.2, C26.2, C27.2, C28.2, C29.2, C30.2, C31.2, C32.2, C33.2, C34.2, J5.5, R21.2, R22.2, R23.2, R24.2, R26.2, R40.2, R57.2, U1.A1 (GND), U1.A16 (GND), U1.D2 (GND), U1.D15 (GND), U1.F8 (GND), U1.F9 (GND), U1.G8 (GND), U1.G10 (GND), U1.H1 (GND), U1.H8 (GND), U1.H9 (GND), U1.H10 (GND), U1.H16 (GND), U1.J8 (GND), U1.J9 (GND), U1.J10 (GND), U1.K6 (GND), U1.K7 (GND), U1.K8 (GND), U1.K9 (GND), U1.K10 (GND), U1.N2 (GND), U1.N15 (GND), U1.P10 (CFG_1), U1.R10 (CFG_2), U1.T1 (GND), U1.T5 (GND), U1.T12 (GND), U1.T16 (GND), U4.3 (GND), U5.3 (GND); also elsewhere on the board
JTAG_TCK: J4.4, R40.1, U1.T10 (TCK); also elsewhere on the board
JTAG_TDI: J4.3, U1.R11 (TDI); also elsewhere on the board
JTAG_TDO: J4.2, U1.M10 (TDO); also elsewhere on the board
JTAG_TMS: J4.1, U1.T11 (TMS); also elsewhere on the board
LED_A: D7.2 (A), U1.P15 (PR41B)
LED_B: D8.2 (A), U1.P16 (PR44A)
LED_C: D9.2 (A), U1.P14 (PR59B)
LED_D: D10.2 (A), U1.N16 (PR41A)
LVL_PA_DIR: U1.F1 (PL23A); also elsewhere on the board
LVL_PD_DIR: U1.D6 (PT20B); also elsewhere on the board
LVL_TST_DIR: U1.F3 (PL14D); also elsewhere on the board
LVL_TST_~OE~: U1.F5 (PL17D); also elsewhere on the board
LVL_VA_DIR: U1.C15 (PR14B); also elsewhere on the board
LVL_VD_DIR: U1.M13 (PR44C); also elsewhere on the board
unnamed: D4.1 (K), R20.1
unnamed: D5.1 (K), R26.1
unnamed: D6.1 (K), R25.1
unnamed: D7.1 (K), R21.1
unnamed: D8.1 (K), R22.1
unnamed: D9.1 (K), R23.1
unnamed: D10.1 (K), R24.1
SPI_CLK: U1.N9 (MCLK,SCK,CCLK); also elsewhere on the board
SPI_MISO: U1.T7 (D1,MISO,IO1,PB11A); also elsewhere on the board
SPI_MOSI: U1.T8 (D0,MOSI,IO0,PB11B); also elsewhere on the board
SPI_~CS~: U1.R8 (~S~,~CS~,PB13A); also elsewhere on the board
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

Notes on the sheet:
CFG[2..0] = 001 (Slave SPI mode)
(3.3V - 2.0V) / 4 mA = 325 ohm
Decoupling Capacitors 1x 0.1uF per supply 1x 0.01uF per power pin
Note: by above logic, 3.3V is short 9x 0.01uF decoupling capacitors, due to lack of space.
Weak pullup (~OE~ is active-low)
Debounce filter, 0.1uF * 10k ohm = 1ms

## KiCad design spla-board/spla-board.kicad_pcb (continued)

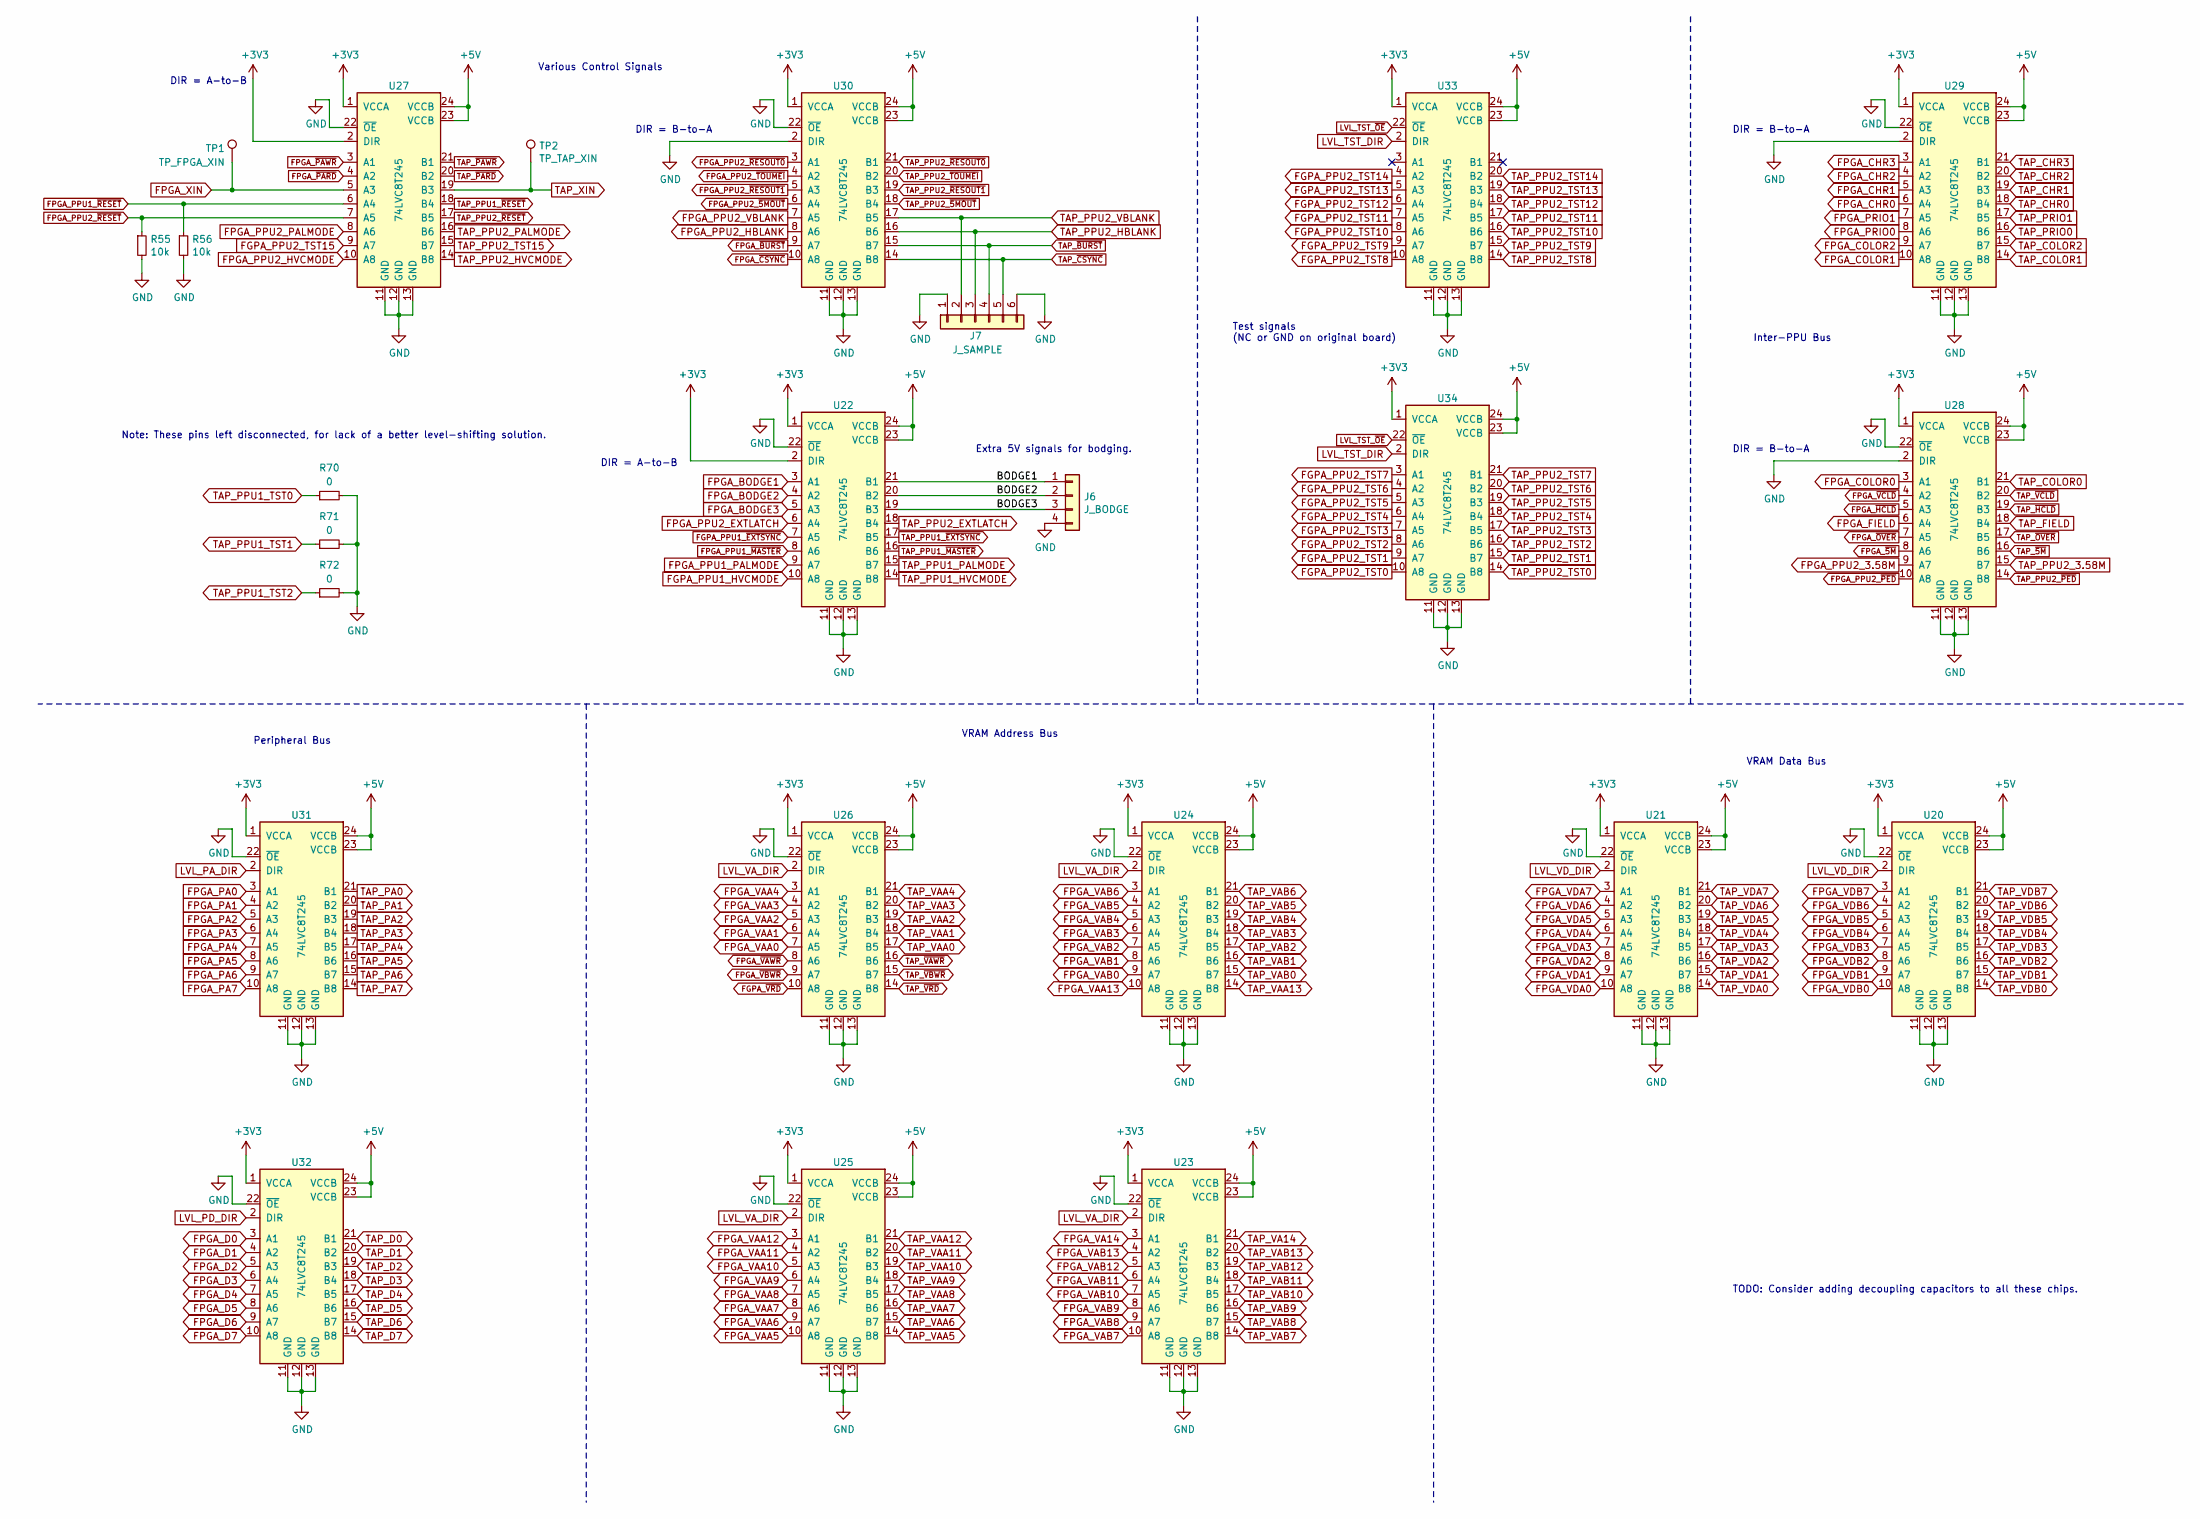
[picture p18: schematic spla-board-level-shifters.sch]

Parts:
J6: J_BODGE; PinHeader_1x04_P2.54mm_Vertical; Digikey S1011EC-40-ND
J7: J_SAMPLE; PinHeader_1x06_P2.54mm_Vertical; Digikey S1011EC-40-ND
R55, R56: 10k; R_0603_1608Metric; Digikey RMCF0603JT10K0CT-ND
R70, R71, R72: 0; R_0603_1608Metric; Digikey 2019-RK73Z1JTTDCT-ND
TP1: TP_FPGA_XIN; TestPoint_Pad_D1.0mm; Digikey N/A
TP2: TP_TAP_XIN; TestPoint_Pad_D1.0mm; Digikey N/A
U20, U21, U22, U23, U24, U25, U26, U27, U28, U29, U30, U31, U32, U33, U34: 74LVC8T245; TSSOP-24_4.4x7.8mm_P0.65mm; Digikey 296-18593-1-ND

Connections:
+5V: U20.23 (VCCB), U20.24 (VCCB), U21.23 (VCCB), U21.24 (VCCB), U22.23 (VCCB), U22.24 (VCCB), U23.23 (VCCB), U23.24 (VCCB), U24.23 (VCCB), U24.24 (VCCB), U25.23 (VCCB), U25.24 (VCCB), U26.23 (VCCB), U26.24 (VCCB), U27.23 (VCCB), U27.24 (VCCB), U28.23 (VCCB), U28.24 (VCCB), U29.23 (VCCB), U29.24 (VCCB), U30.23 (VCCB), U30.24 (VCCB), U31.23 (VCCB), U31.24 (VCCB), U32.23 (VCCB), U32.24 (VCCB), U33.23 (VCCB), U33.24 (VCCB), U34.23 (VCCB), U34.24 (VCCB); also elsewhere on the board
/SPLA Board - Level Shifters/BODGE1: J6.1, U22.21 (B1)
/SPLA Board - Level Shifters/BODGE2: J6.2, U22.20 (B2)
/SPLA Board - Level Shifters/BODGE3: J6.3, U22.19 (B3)
FGPA_PPU1_HVCMODE: U22.10 (A8); also elsewhere on the board
FGPA_PPU1_~EXTSYNC~: U22.7 (A5); also elsewhere on the board
FGPA_PPU2_TST0: U34.10 (A8); also elsewhere on the board
FGPA_PPU2_TST1: U34.9 (A7); also elsewhere on the board
FGPA_PPU2_TST2: U34.8 (A6); also elsewhere on the board
FGPA_PPU2_TST3: U34.7 (A5); also elsewhere on the board
FGPA_PPU2_TST4: U34.6 (A4); also elsewhere on the board
FGPA_PPU2_TST5: U34.5 (A3); also elsewhere on the board
FGPA_PPU2_TST6: U34.4 (A2); also elsewhere on the board
FGPA_PPU2_TST7: U34.3 (A1); also elsewhere on the board
FGPA_PPU2_TST8: U33.10 (A8); also elsewhere on the board
FGPA_PPU2_TST9: U33.9 (A7); also elsewhere on the board
FGPA_PPU2_TST10: U33.8 (A6); also elsewhere on the board
FGPA_PPU2_TST11: U33.7 (A5); also elsewhere on the board
FGPA_PPU2_TST12: U33.6 (A4); also elsewhere on the board
FGPA_PPU2_TST13: U33.5 (A3); also elsewhere on the board
FGPA_PPU2_TST14: U33.4 (A2); also elsewhere on the board
FGPA_PPU2_TST15: U27.9 (A7); also elsewhere on the board
FGPA_~VRD~: U26.10 (A8); also elsewhere on the board
FPGA_BODGE1: U22.3 (A1); also elsewhere on the board
FPGA_BODGE2: U22.4 (A2); also elsewhere on the board
FPGA_BODGE3: U22.5 (A3); also elsewhere on the board
FPGA_CHR0: U29.6 (A4); also elsewhere on the board
FPGA_CHR1: U29.5 (A3); also elsewhere on the board
FPGA_CHR2: U29.4 (A2); also elsewhere on the board
FPGA_CHR3: U29.3 (A1); also elsewhere on the board
FPGA_COLOR0: U28.3 (A1); also elsewhere on the board
FPGA_COLOR1: U29.10 (A8); also elsewhere on the board
FPGA_COLOR2: U29.9 (A7); also elsewhere on the board
FPGA_D0: U32.3 (A1); also elsewhere on the board
FPGA_D1: U32.4 (A2); also elsewhere on the board
FPGA_D2: U32.5 (A3); also elsewhere on the board
FPGA_D3: U32.6 (A4); also elsewhere on the board
FPGA_D4: U32.7 (A5); also elsewhere on the board
FPGA_D5: U32.8 (A6); also elsewhere on the board
FPGA_D6: U32.9 (A7); also elsewhere on the board
FPGA_D7: U32.10 (A8); also elsewhere on the board
FPGA_FIELD: U28.6 (A4); also elsewhere on the board
FPGA_PA0: U31.3 (A1); also elsewhere on the board
FPGA_PA1: U31.4 (A2); also elsewhere on the board
FPGA_PA2: U31.5 (A3); also elsewhere on the board
FPGA_PA3: U31.6 (A4); also elsewhere on the board
FPGA_PA4: U31.7 (A5); also elsewhere on the board
FPGA_PA5: U31.8 (A6); also elsewhere on the board
FPGA_PA6: U31.9 (A7); also elsewhere on the board
FPGA_PA7: U31.10 (A8); also elsewhere on the board
FPGA_PPU1_PALMODE: U22.9 (A7); also elsewhere on the board
FPGA_PPU1_~MASTER~: U22.8 (A6); also elsewhere on the board
FPGA_PPU1_~RESET~: R56.1, U27.6 (A4); also elsewhere on the board
FPGA_PPU2_3.58M: U28.9 (A7); also elsewhere on the board
FPGA_PPU2_EXTLATCH: U22.6 (A4); also elsewhere on the board
FPGA_PPU2_HBLANK: U30.8 (A6); also elsewhere on the board
FPGA_PPU2_HVCMODE: U27.10 (A8); also elsewhere on the board
FPGA_PPU2_PALMODE: U27.8 (A6); also elsewhere on the board
FPGA_PPU2_VBLANK: U30.7 (A5); also elsewhere on the board
FPGA_PPU2_~5MOUT~: U30.6 (A4); also elsewhere on the board
FPGA_PPU2_~PED~: U28.10 (A8); also elsewhere on the board
FPGA_PPU2_~RESET~: R55.1, U27.7 (A5); also elsewhere on the board
FPGA_PPU2_~RESOUT0~: U30.3 (A1); also elsewhere on the board
FPGA_PPU2_~RESOUT1~: U30.5 (A3); also elsewhere on the board
FPGA_PPU2_~TOUMEI~: U30.4 (A2); also elsewhere on the board
FPGA_PRIO0: U29.8 (A6); also elsewhere on the board
FPGA_PRIO1: U29.7 (A5); also elsewhere on the board
FPGA_VA14: U23.3 (A1); also elsewhere on the board
FPGA_VAA0: U26.7 (A5); also elsewhere on the board
FPGA_VAA1: U26.6 (A4); also elsewhere on the board
FPGA_VAA2: U26.5 (A3); also elsewhere on the board
FPGA_VAA3: U26.4 (A2); also elsewhere on the board
FPGA_VAA4: U26.3 (A1); also elsewhere on the board
FPGA_VAA5: U25.10 (A8); also elsewhere on the board
FPGA_VAA6: U25.9 (A7); also elsewhere on the board
FPGA_VAA7: U25.8 (A6); also elsewhere on the board
FPGA_VAA8: U25.7 (A5); also elsewhere on the board
FPGA_VAA9: U25.6 (A4); also elsewhere on the board
FPGA_VAA10: U25.5 (A3); also elsewhere on the board
FPGA_VAA11: U25.4 (A2); also elsewhere on the board
FPGA_VAA12: U25.3 (A1); also elsewhere on the board
FPGA_VAA13: U24.10 (A8); also elsewhere on the board
FPGA_VAB0: U24.9 (A7); also elsewhere on the board
FPGA_VAB1: U24.8 (A6); also elsewhere on the board
FPGA_VAB2: U24.7 (A5); also elsewhere on the board
FPGA_VAB3: U24.6 (A4); also elsewhere on the board
FPGA_VAB4: U24.5 (A3); also elsewhere on the board
FPGA_VAB5: U24.4 (A2); also elsewhere on the board
FPGA_VAB6: U24.3 (A1); also elsewhere on the board
FPGA_VAB7: U23.10 (A8); also elsewhere on the board
FPGA_VAB8: U23.9 (A7); also elsewhere on the board
FPGA_VAB9: U23.8 (A6); also elsewhere on the board
FPGA_VAB10: U23.7 (A5); also elsewhere on the board
FPGA_VAB11: U23.6 (A4); also elsewhere on the board
FPGA_VAB12: U23.5 (A3); also elsewhere on the board
FPGA_VAB13: U23.4 (A2); also elsewhere on the board
FPGA_VDA0: U21.10 (A8); also elsewhere on the board
FPGA_VDA1: U21.9 (A7); also elsewhere on the board
FPGA_VDA2: U21.8 (A6); also elsewhere on the board
FPGA_VDA3: U21.7 (A5); also elsewhere on the board
FPGA_VDA4: U21.6 (A4); also elsewhere on the board
FPGA_VDA5: U21.5 (A3); also elsewhere on the board
FPGA_VDA6: U21.4 (A2); also elsewhere on the board
FPGA_VDA7: U21.3 (A1); also elsewhere on the board
FPGA_VDB0: U20.10 (A8); also elsewhere on the board
FPGA_VDB1: U20.9 (A7); also elsewhere on the board
FPGA_VDB2: U20.8 (A6); also elsewhere on the board
FPGA_VDB3: U20.7 (A5); also elsewhere on the board
FPGA_VDB4: U20.6 (A4); also elsewhere on the board
FPGA_VDB5: U20.5 (A3); also elsewhere on the board
FPGA_VDB6: U20.4 (A2); also elsewhere on the board
FPGA_VDB7: U20.3 (A1); also elsewhere on the board
FPGA_XIN: TP1.1, U27.5 (A3); also elsewhere on the board
FPGA_~5M~: U28.8 (A6); also elsewhere on the board
FPGA_~BURST~: U30.9 (A7); also elsewhere on the board
FPGA_~CSYNC~: U30.10 (A8); also elsewhere on the board
FPGA_~HCLD: U28.5 (A3); also elsewhere on the board
FPGA_~OVER~: U28.7 (A5); also elsewhere on the board
FPGA_~PARD~: U27.4 (A2); also elsewhere on the board
FPGA_~PAWR~: U27.3 (A1); also elsewhere on the board
FPGA_~VAWR~: U26.8 (A6); also elsewhere on the board
FPGA_~VBWR~: U26.9 (A7); also elsewhere on the board
FPGA_~VCLD~: U28.4 (A2); also elsewhere on the board
GND: J6.4, J7.1, J7.6, R55.2, R56.2, R70.2, R71.2, R72.2, U20.11 (GND), U20.12 (GND), U20.13 (GND), U20.22 (~OE), U21.11 (GND), U21.12 (GND), U21.13 (GND), U21.22 (~OE), U22.11 (GND), U22.12 (GND), U22.13 (GND), U22.22 (~OE), U23.11 (GND), U23.12 (GND), U23.13 (GND), U23.22 (~OE), U24.11 (GND), U24.12 (GND), U24.13 (GND), U24.22 (~OE), U25.11 (GND), U25.12 (GND), U25.13 (GND), U25.22 (~OE), U26.11 (GND), U26.12 (GND), U26.13 (GND), U26.22 (~OE), U27.11 (GND), U27.12 (GND), U27.13 (GND), U27.22 (~OE), U28.2 (DIR), U28.11 (GND), U28.12 (GND), U28.13 (GND), U28.22 (~OE), U29.2 (DIR), U29.11 (GND), U29.12 (GND), U29.13 (GND), U29.22 (~OE), U30.2 (DIR), U30.11 (GND), U30.12 (GND), U30.13 (GND), U30.22 (~OE), U31.11 (GND), U31.12 (GND), U31.13 (GND), U31.22 (~OE), U32.11 (GND), U32.12 (GND), U32.13 (GND), U32.22 (~OE), U33.11 (GND), U33.12 (GND), U33.13 (GND), U34.11 (GND), U34.12 (GND), U34.13 (GND); also elsewhere on the board
LVL_PA_DIR: U31.2 (DIR); also elsewhere on the board
LVL_PD_DIR: U32.2 (DIR); also elsewhere on the board
LVL_TST_DIR: U33.2 (DIR), U34.2 (DIR); also elsewhere on the board
LVL_TST_~OE~: U33.22 (~OE), U34.22 (~OE); also elsewhere on the board
LVL_VA_DIR: U23.2 (DIR), U24.2 (DIR), U25.2 (DIR), U26.2 (DIR); also elsewhere on the board
LVL_VD_DIR: U20.2 (DIR), U21.2 (DIR); also elsewhere on the board
TAP_CHR0: U29.18 (B4); also elsewhere on the board
TAP_CHR1: U29.19 (B3); also elsewhere on the board
TAP_CHR2: U29.20 (B2); also elsewhere on the board
TAP_CHR3: U29.21 (B1); also elsewhere on the board
TAP_COLOR0: U28.21 (B1); also elsewhere on the board
TAP_COLOR1: U29.14 (B8); also elsewhere on the board
TAP_COLOR2: U29.15 (B7); also elsewhere on the board
TAP_D0: U32.21 (B1); also elsewhere on the board
TAP_D1: U32.20 (B2); also elsewhere on the board
TAP_D2: U32.19 (B3); also elsewhere on the board
TAP_D3: U32.18 (B4); also elsewhere on the board
TAP_D4: U32.17 (B5); also elsewhere on the board
TAP_D5: U32.16 (B6); also elsewhere on the board
TAP_D6: U32.15 (B7); also elsewhere on the board
TAP_D7: U32.14 (B8); also elsewhere on the board
TAP_FIELD: U28.18 (B4); also elsewhere on the board
TAP_PA0: U31.21 (B1); also elsewhere on the board
TAP_PA1: U31.20 (B2); also elsewhere on the board
TAP_PA2: U31.19 (B3); also elsewhere on the board
TAP_PA3: U31.18 (B4); also elsewhere on the board
TAP_PA4: U31.17 (B5); also elsewhere on the board
TAP_PA5: U31.16 (B6); also elsewhere on the board
TAP_PA6: U31.15 (B7); also elsewhere on the board
TAP_PA7: U31.14 (B8); also elsewhere on the board
TAP_PPU1_HVCMODE: U22.14 (B8); also elsewhere on the board
TAP_PPU1_PALMODE: U22.15 (B7); also elsewhere on the board
TAP_PPU1_TST0: R70.1; also elsewhere on the board
TAP_PPU1_TST1: R71.1; also elsewhere on the board
TAP_PPU1_TST2: R72.1; also elsewhere on the board
TAP_PPU1_~EXTSYNC~: U22.17 (B5); also elsewhere on the board
TAP_PPU1_~MASTER~: U22.16 (B6); also elsewhere on the board
TAP_PPU1_~RESET~: U27.18 (B4); also elsewhere on the board
TAP_PPU2_3.58M: U28.15 (B7); also elsewhere on the board
TAP_PPU2_EXTLATCH: U22.18 (B4); also elsewhere on the board
TAP_PPU2_HBLANK: J7.3, U30.16 (B6); also elsewhere on the board
TAP_PPU2_HVCMODE: U27.14 (B8); also elsewhere on the board
TAP_PPU2_PALMODE: U27.16 (B6); also elsewhere on the board
TAP_PPU2_TST0: U34.14 (B8); also elsewhere on the board
TAP_PPU2_TST1: U34.15 (B7); also elsewhere on the board
TAP_PPU2_TST2: U34.16 (B6); also elsewhere on the board
TAP_PPU2_TST3: U34.17 (B5); also elsewhere on the board
TAP_PPU2_TST4: U34.18 (B4); also elsewhere on the board
TAP_PPU2_TST5: U34.19 (B3); also elsewhere on the board
TAP_PPU2_TST6: U34.20 (B2); also elsewhere on the board
TAP_PPU2_TST7: U34.21 (B1); also elsewhere on the board
TAP_PPU2_TST8: U33.14 (B8); also elsewhere on the board
TAP_PPU2_TST9: U33.15 (B7); also elsewhere on the board
TAP_PPU2_TST10: U33.16 (B6); also elsewhere on the board
TAP_PPU2_TST11: U33.17 (B5); also elsewhere on the board
TAP_PPU2_TST12: U33.18 (B4); also elsewhere on the board
TAP_PPU2_TST13: U33.19 (B3); also elsewhere on the board
TAP_PPU2_TST14: U33.20 (B2); also elsewhere on the board
TAP_PPU2_TST15: U27.15 (B7); also elsewhere on the board
TAP_PPU2_VBLANK: J7.2, U30.17 (B5); also elsewhere on the board
TAP_PPU2_~5MOUT~: U30.18 (B4); also elsewhere on the board
TAP_PPU2_~PED~: U28.14 (B8); also elsewhere on the board
TAP_PPU2_~RESET~: U27.17 (B5); also elsewhere on the board
TAP_PPU2_~RESOUT0~: U30.21 (B1); also elsewhere on the board
TAP_PPU2_~RESOUT1~: U30.19 (B3); also elsewhere on the board
TAP_PPU2_~TOUMEI~: U30.20 (B2); also elsewhere on the board
TAP_PRIO0: U29.16 (B6); also elsewhere on the board
TAP_PRIO1: U29.17 (B5); also elsewhere on the board
TAP_VA14: U23.21 (B1); also elsewhere on the board
TAP_VAA0: U26.17 (B5); also elsewhere on the board
TAP_VAA1: U26.18 (B4); also elsewhere on the board
TAP_VAA2: U26.19 (B3); also elsewhere on the board
TAP_VAA3: U26.20 (B2); also elsewhere on the board
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

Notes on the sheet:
Peripheral Bus
VRAM Address Bus
VRAM Data Bus
Inter-PPU Bus
Extra 5V signals for bodging.
TODO: Consider adding decoupling capacitors to all these chips.
Test signals (NC or GND on original board)
Note: These pins left disconnected, for lack of a better level-shifting solution.
Various Control Signals
DIR = B-to-A
DIR = A-to-B

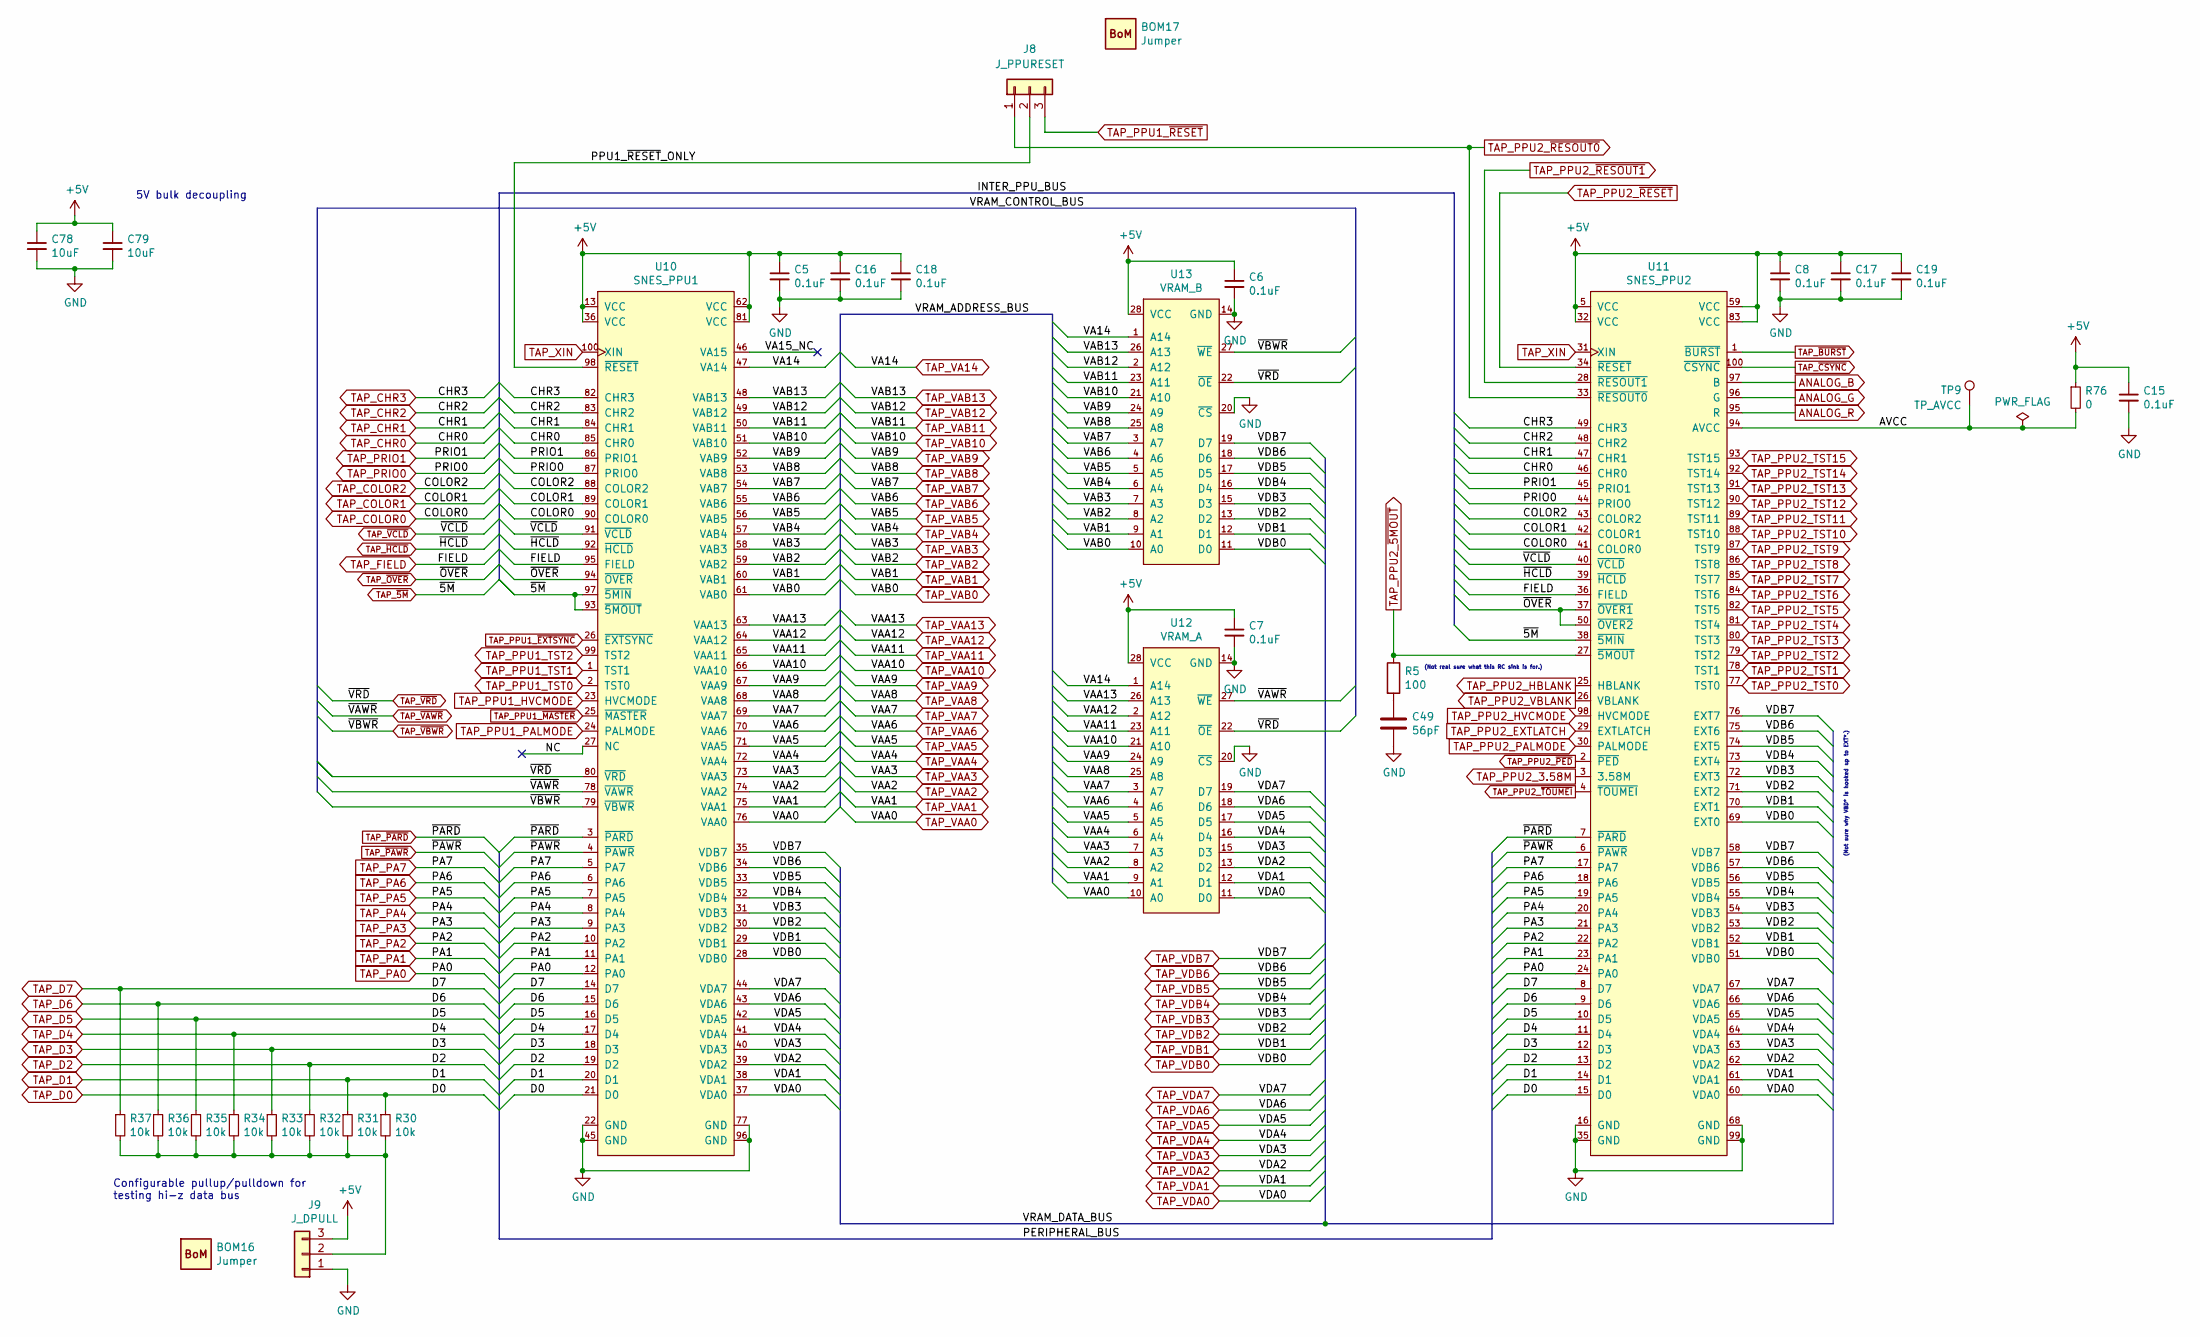
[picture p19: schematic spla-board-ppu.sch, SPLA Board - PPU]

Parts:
BOM16, BOM17: Jumper; BoM; Digikey S9337-ND
C5, C6, C7, C8, C15, C16, C17, C18, C19: 0.1uF; C_0603_1608Metric; Digikey 490-16477-1-ND
C49: 56pF; C_0603_1608Metric; Digikey 490-17769-1-ND
C78, C79: 10uF; C_0805_2012Metric; Digikey 490-10516-1-ND
J8: J_PPURESET; PinHeader_1x03_P2.54mm_Vertical; Digikey S1011EC-40-ND
J9: J_DPULL; PinHeader_1x03_P2.54mm_Vertical; Digikey S1011EC-40-ND
R5: 100; R_0603_1608Metric; Digikey RMCF0603JT100RCT-ND
R30, R31, R32, R33, R34, R35, R36, R37: 10k; R_0603_1608Metric; Digikey RMCF0603JT10K0CT-ND
R76: 0; R_0603_1608Metric; Digikey 2019-RK73Z1JTTDCT-ND
TP9: TP_AVCC; TestPoint_Pad_D1.0mm; Digikey N/A
U10: SNES_PPU1; QFP-100_14x20mm_P0.65mm; Digikey N/A
U11: SNES_PPU2; QFP-100_14x20mm_P0.65mm; Digikey N/A
U12: VRAM_A; SOP-28_17x8mm_P1.27mm; Digikey N/A
U13: VRAM_B; SOP-28_17x8mm_P1.27mm; Digikey N/A

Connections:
+5V: C5.1, C6.1, C7.1, C8.1, C15.1, C16.1, C17.1, C18.1, C19.1, C78.1, C79.1, J9.3, R76.1, U10.13 (VCC), U10.36 (VCC), U10.62 (VCC), U10.81 (VCC), U11.5 (VCC), U11.32 (VCC), U11.59 (VCC), U11.83 (VCC), U12.28 (VCC), U13.28 (VCC); also elsewhere on the board
/SPLA Board - PPU/AVCC: R76.2, TP9.1, U11.94 (AVCC)
/SPLA Board - PPU/NC: U10.27 (NC)
/SPLA Board - PPU/PPU1_~RESET~_ONLY: J8.2, U10.98 (~RESET)
/SPLA Board - PPU/VA15_NC: U10.46 (VA15)
ANALOG_B: U11.97 (B); also elsewhere on the board
ANALOG_G: U11.96 (G); also elsewhere on the board
ANALOG_R: U11.95 (R); also elsewhere on the board
GND: C5.2, C6.2, C7.2, C8.2, C15.2, C16.2, C17.2, C18.2, C19.2, C49.2, C78.2, C79.2, J9.1, U10.22 (GND), U10.45 (GND), U10.77 (GND), U10.96 (GND), U11.16 (GND), U11.35 (GND), U11.68 (GND), U11.99 (GND), U12.14 (GND), U12.20 (~CS), U13.14 (GND), U13.20 (~CS); also elsewhere on the board
unnamed: C49.1, R5.2
unnamed: J9.2, R30.2, R31.2, R32.2, R33.2, R34.2, R35.2, R36.2, R37.2
TAP_CHR0: U10.85 (CHR0), U11.46 (CHR0); also elsewhere on the board
TAP_CHR1: U10.84 (CHR1), U11.47 (CHR1); also elsewhere on the board
TAP_CHR2: U10.83 (CHR2), U11.48 (CHR2); also elsewhere on the board
TAP_CHR3: U10.82 (CHR3), U11.49 (CHR3); also elsewhere on the board
TAP_COLOR0: U10.90 (COLOR0), U11.41 (COLOR0); also elsewhere on the board
TAP_COLOR1: U10.89 (COLOR1), U11.42 (COLOR1); also elsewhere on the board
TAP_COLOR2: U10.88 (COLOR2), U11.43 (COLOR2); also elsewhere on the board
TAP_D0: R30.1, U10.21 (D0), U11.15 (D0); also elsewhere on the board
TAP_D1: R31.1, U10.20 (D1), U11.14 (D1); also elsewhere on the board
TAP_D2: R32.1, U10.19 (D2), U11.13 (D2); also elsewhere on the board
TAP_D3: R33.1, U10.18 (D3), U11.12 (D3); also elsewhere on the board
TAP_D4: R34.1, U10.17 (D4), U11.11 (D4); also elsewhere on the board
TAP_D5: R35.1, U10.16 (D5), U11.10 (D5); also elsewhere on the board
TAP_D6: R36.1, U10.15 (D6), U11.9 (D6); also elsewhere on the board
TAP_D7: R37.1, U10.14 (D7), U11.8 (D7); also elsewhere on the board
TAP_FIELD: U10.95 (FIELD), U11.36 (FIELD); also elsewhere on the board
TAP_PA0: U10.12 (PA0), U11.24 (PA0); also elsewhere on the board
TAP_PA1: U10.11 (PA1), U11.23 (PA1); also elsewhere on the board
TAP_PA2: U10.10 (PA2), U11.22 (PA2); also elsewhere on the board
TAP_PA3: U10.9 (PA3), U11.21 (PA3); also elsewhere on the board
TAP_PA4: U10.8 (PA4), U11.20 (PA4); also elsewhere on the board
TAP_PA5: U10.7 (PA5), U11.19 (PA5); also elsewhere on the board
TAP_PA6: U10.6 (PA6), U11.18 (PA6); also elsewhere on the board
TAP_PA7: U10.5 (PA7), U11.17 (PA7); also elsewhere on the board
TAP_PPU1_HVCMODE: U10.23 (HVCMODE); also elsewhere on the board
TAP_PPU1_PALMODE: U10.24 (PALMODE); also elsewhere on the board
TAP_PPU1_TST0: U10.2 (TST0); also elsewhere on the board
TAP_PPU1_TST1: U10.1 (TST1); also elsewhere on the board
TAP_PPU1_TST2: U10.99 (TST2); also elsewhere on the board
TAP_PPU1_~EXTSYNC~: U10.26 (~EXTSYNC); also elsewhere on the board
TAP_PPU1_~MASTER~: U10.25 (~MASTER); also elsewhere on the board
TAP_PPU1_~RESET~: J8.3; also elsewhere on the board
TAP_PPU2_3.58M: U11.3 (3.58M); also elsewhere on the board
TAP_PPU2_EXTLATCH: U11.29 (EXTLATCH); also elsewhere on the board
TAP_PPU2_HBLANK: U11.25 (HBLANK); also elsewhere on the board
TAP_PPU2_HVCMODE: U11.98 (HVCMODE); also elsewhere on the board
TAP_PPU2_PALMODE: U11.30 (PALMODE); also elsewhere on the board
TAP_PPU2_TST0: U11.77 (TST0); also elsewhere on the board
TAP_PPU2_TST1: U11.78 (TST1); also elsewhere on the board
TAP_PPU2_TST2: U11.79 (TST2); also elsewhere on the board
TAP_PPU2_TST3: U11.80 (TST3); also elsewhere on the board
TAP_PPU2_TST4: U11.81 (TST4); also elsewhere on the board
TAP_PPU2_TST5: U11.82 (TST5); also elsewhere on the board
TAP_PPU2_TST6: U11.84 (TST6); also elsewhere on the board
TAP_PPU2_TST7: U11.85 (TST7); also elsewhere on the board
TAP_PPU2_TST8: U11.86 (TST8); also elsewhere on the board
TAP_PPU2_TST9: U11.87 (TST9); also elsewhere on the board
TAP_PPU2_TST10: U11.88 (TST10); also elsewhere on the board
TAP_PPU2_TST11: U11.89 (TST11); also elsewhere on the board
TAP_PPU2_TST12: U11.90 (TST12); also elsewhere on the board
TAP_PPU2_TST13: U11.91 (TST13); also elsewhere on the board
TAP_PPU2_TST14: U11.92 (TST14); also elsewhere on the board
TAP_PPU2_TST15: U11.93 (TST15); also elsewhere on the board
TAP_PPU2_VBLANK: U11.26 (VBLANK); also elsewhere on the board
TAP_PPU2_~5MOUT~: R5.1, U11.27 (~5MOUT); also elsewhere on the board
TAP_PPU2_~PED~: U11.2 (~PED); also elsewhere on the board
TAP_PPU2_~RESET~: U11.34 (~RESET); also elsewhere on the board
TAP_PPU2_~RESOUT0~: J8.1, U11.33 (~RESOUT0); also elsewhere on the board
TAP_PPU2_~RESOUT1~: U11.28 (~RESOUT1); also elsewhere on the board
TAP_PPU2_~TOUMEI~: U11.4 (~TOUMEI); also elsewhere on the board
TAP_PRIO0: U10.87 (PRIO0), U11.44 (PRIO0); also elsewhere on the board
TAP_PRIO1: U10.86 (PRIO1), U11.45 (PRIO1); also elsewhere on the board
TAP_VA14: U10.47 (VA14), U12.1 (A14), U13.1 (A14); also elsewhere on the board
TAP_VAA0: U10.76 (VAA0), U12.10 (A0); also elsewhere on the board
TAP_VAA1: U10.75 (VAA1), U12.9 (A1); also elsewhere on the board
TAP_VAA2: U10.74 (VAA2), U12.8 (A2); also elsewhere on the board
TAP_VAA3: U10.73 (VAA3), U12.7 (A3); also elsewhere on the board
TAP_VAA4: U10.72 (VAA4), U12.6 (A4); also elsewhere on the board
TAP_VAA5: U10.71 (VAA5), U12.5 (A5); also elsewhere on the board
TAP_VAA6: U10.70 (VAA6), U12.4 (A6); also elsewhere on the board
TAP_VAA7: U10.69 (VAA7), U12.3 (A7); also elsewhere on the board
TAP_VAA8: U10.68 (VAA8), U12.25 (A8); also elsewhere on the board
TAP_VAA9: U10.67 (VAA9), U12.24 (A9); also elsewhere on the board
TAP_VAA10: U10.66 (VAA10), U12.21 (A10); also elsewhere on the board
TAP_VAA11: U10.65 (VAA11), U12.23 (A11); also elsewhere on the board
TAP_VAA12: U10.64 (VAA12), U12.2 (A12); also elsewhere on the board
TAP_VAA13: U10.63 (VAA13), U12.26 (A13); also elsewhere on the board
TAP_VAB0: U10.61 (VAB0), U13.10 (A0); also elsewhere on the board
TAP_VAB1: U10.60 (VAB1), U13.9 (A1); also elsewhere on the board
TAP_VAB2: U10.59 (VAB2), U13.8 (A2); also elsewhere on the board
TAP_VAB3: U10.58 (VAB3), U13.7 (A3); also elsewhere on the board
TAP_VAB4: U10.57 (VAB4), U13.6 (A4); also elsewhere on the board
TAP_VAB5: U10.56 (VAB5), U13.5 (A5); also elsewhere on the board
TAP_VAB6: U10.55 (VAB6), U13.4 (A6); also elsewhere on the board
TAP_VAB7: U10.54 (VAB7), U13.3 (A7); also elsewhere on the board
TAP_VAB8: U10.53 (VAB8), U13.25 (A8); also elsewhere on the board
TAP_VAB9: U10.52 (VAB9), U13.24 (A9); also elsewhere on the board
TAP_VAB10: U10.51 (VAB10), U13.21 (A10); also elsewhere on the board
TAP_VAB11: U10.50 (VAB11), U13.23 (A11); also elsewhere on the board
TAP_VAB12: U10.49 (VAB12), U13.2 (A12); also elsewhere on the board
TAP_VAB13: U10.48 (VAB13), U13.26 (A13); also elsewhere on the board
TAP_VDA0: U10.37 (VDA0), U11.60 (VDA0), U12.11 (D0); also elsewhere on the board
TAP_VDA1: U10.38 (VDA1), U11.61 (VDA1), U12.12 (D1); also elsewhere on the board
TAP_VDA2: U10.39 (VDA2), U11.62 (VDA2), U12.13 (D2); also elsewhere on the board
TAP_VDA3: U10.40 (VDA3), U11.63 (VDA3), U12.15 (D3); also elsewhere on the board
TAP_VDA4: U10.41 (VDA4), U11.64 (VDA4), U12.16 (D4); also elsewhere on the board
TAP_VDA5: U10.42 (VDA5), U11.65 (VDA5), U12.17 (D5); also elsewhere on the board
TAP_VDA6: U10.43 (VDA6), U11.66 (VDA6), U12.18 (D6); also elsewhere on the board
TAP_VDA7: U10.44 (VDA7), U11.67 (VDA7), U12.19 (D7); also elsewhere on the board
TAP_VDB0: U10.28 (VDB0), U11.51 (VDB0), U11.69 (EXT0), U13.11 (D0); also elsewhere on the board
TAP_VDB1: U10.29 (VDB1), U11.52 (VDB1), U11.70 (EXT1), U13.12 (D1); also elsewhere on the board
TAP_VDB2: U10.30 (VDB2), U11.53 (VDB2), U11.71 (EXT2), U13.13 (D2); also elsewhere on the board
TAP_VDB3: U10.31 (VDB3), U11.54 (VDB3), U11.72 (EXT3), U13.15 (D3); also elsewhere on the board
TAP_VDB4: U10.32 (VDB4), U11.55 (VDB4), U11.73 (EXT4), U13.16 (D4); also elsewhere on the board
TAP_VDB5: U10.33 (VDB5), U11.56 (VDB5), U11.74 (EXT5), U13.17 (D5); also elsewhere on the board
TAP_VDB6: U10.34 (VDB6), U11.57 (VDB6), U11.75 (EXT6), U13.18 (D6); also elsewhere on the board
TAP_VDB7: U10.35 (VDB7), U11.58 (VDB7), U11.76 (EXT7), U13.19 (D7); also elsewhere on the board
TAP_XIN: U10.100 (XIN), U11.31 (XIN); also elsewhere on the board
TAP_~5M~: U10.93 (~5MOUT), U10.97 (~5MIN), U11.38 (~5MIN); also elsewhere on the board
TAP_~BURST~: U11.1 (~BURST); also elsewhere on the board
TAP_~CSYNC~: U11.100 (~CSYNC); also elsewhere on the board
TAP_~HCLD~: U10.92 (~HCLD), U11.39 (~HCLD); also elsewhere on the board
TAP_~OVER~: U10.94 (~OVER), U11.37 (~OVER1), U11.50 (~OVER2); also elsewhere on the board
TAP_~PARD~: U10.3 (~PARD), U11.7 (~PARD); also elsewhere on the board
TAP_~PAWR~: U10.4 (~PAWR), U11.6 (~PAWR); also elsewhere on the board
TAP_~VAWR~: U10.78 (~VAWR), U12.27 (~WE); also elsewhere on the board
TAP_~VBWR~: U10.79 (~VBWR), U13.27 (~WE); also elsewhere on the board
TAP_~VCLD~: U10.91 (~VCLD), U11.40 (~VCLD); also elsewhere on the board
TAP_~VRD~: U10.80 (~VRD), U12.22 (~OE), U13.22 (~OE); also elsewhere on the board

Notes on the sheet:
(Not real sure what this RC sink is for.)
(Not sure why VBD* is hooked up to EXT*.)
Configurable pullup/pulldown for testing hi-z data bus
5V bulk decoupling

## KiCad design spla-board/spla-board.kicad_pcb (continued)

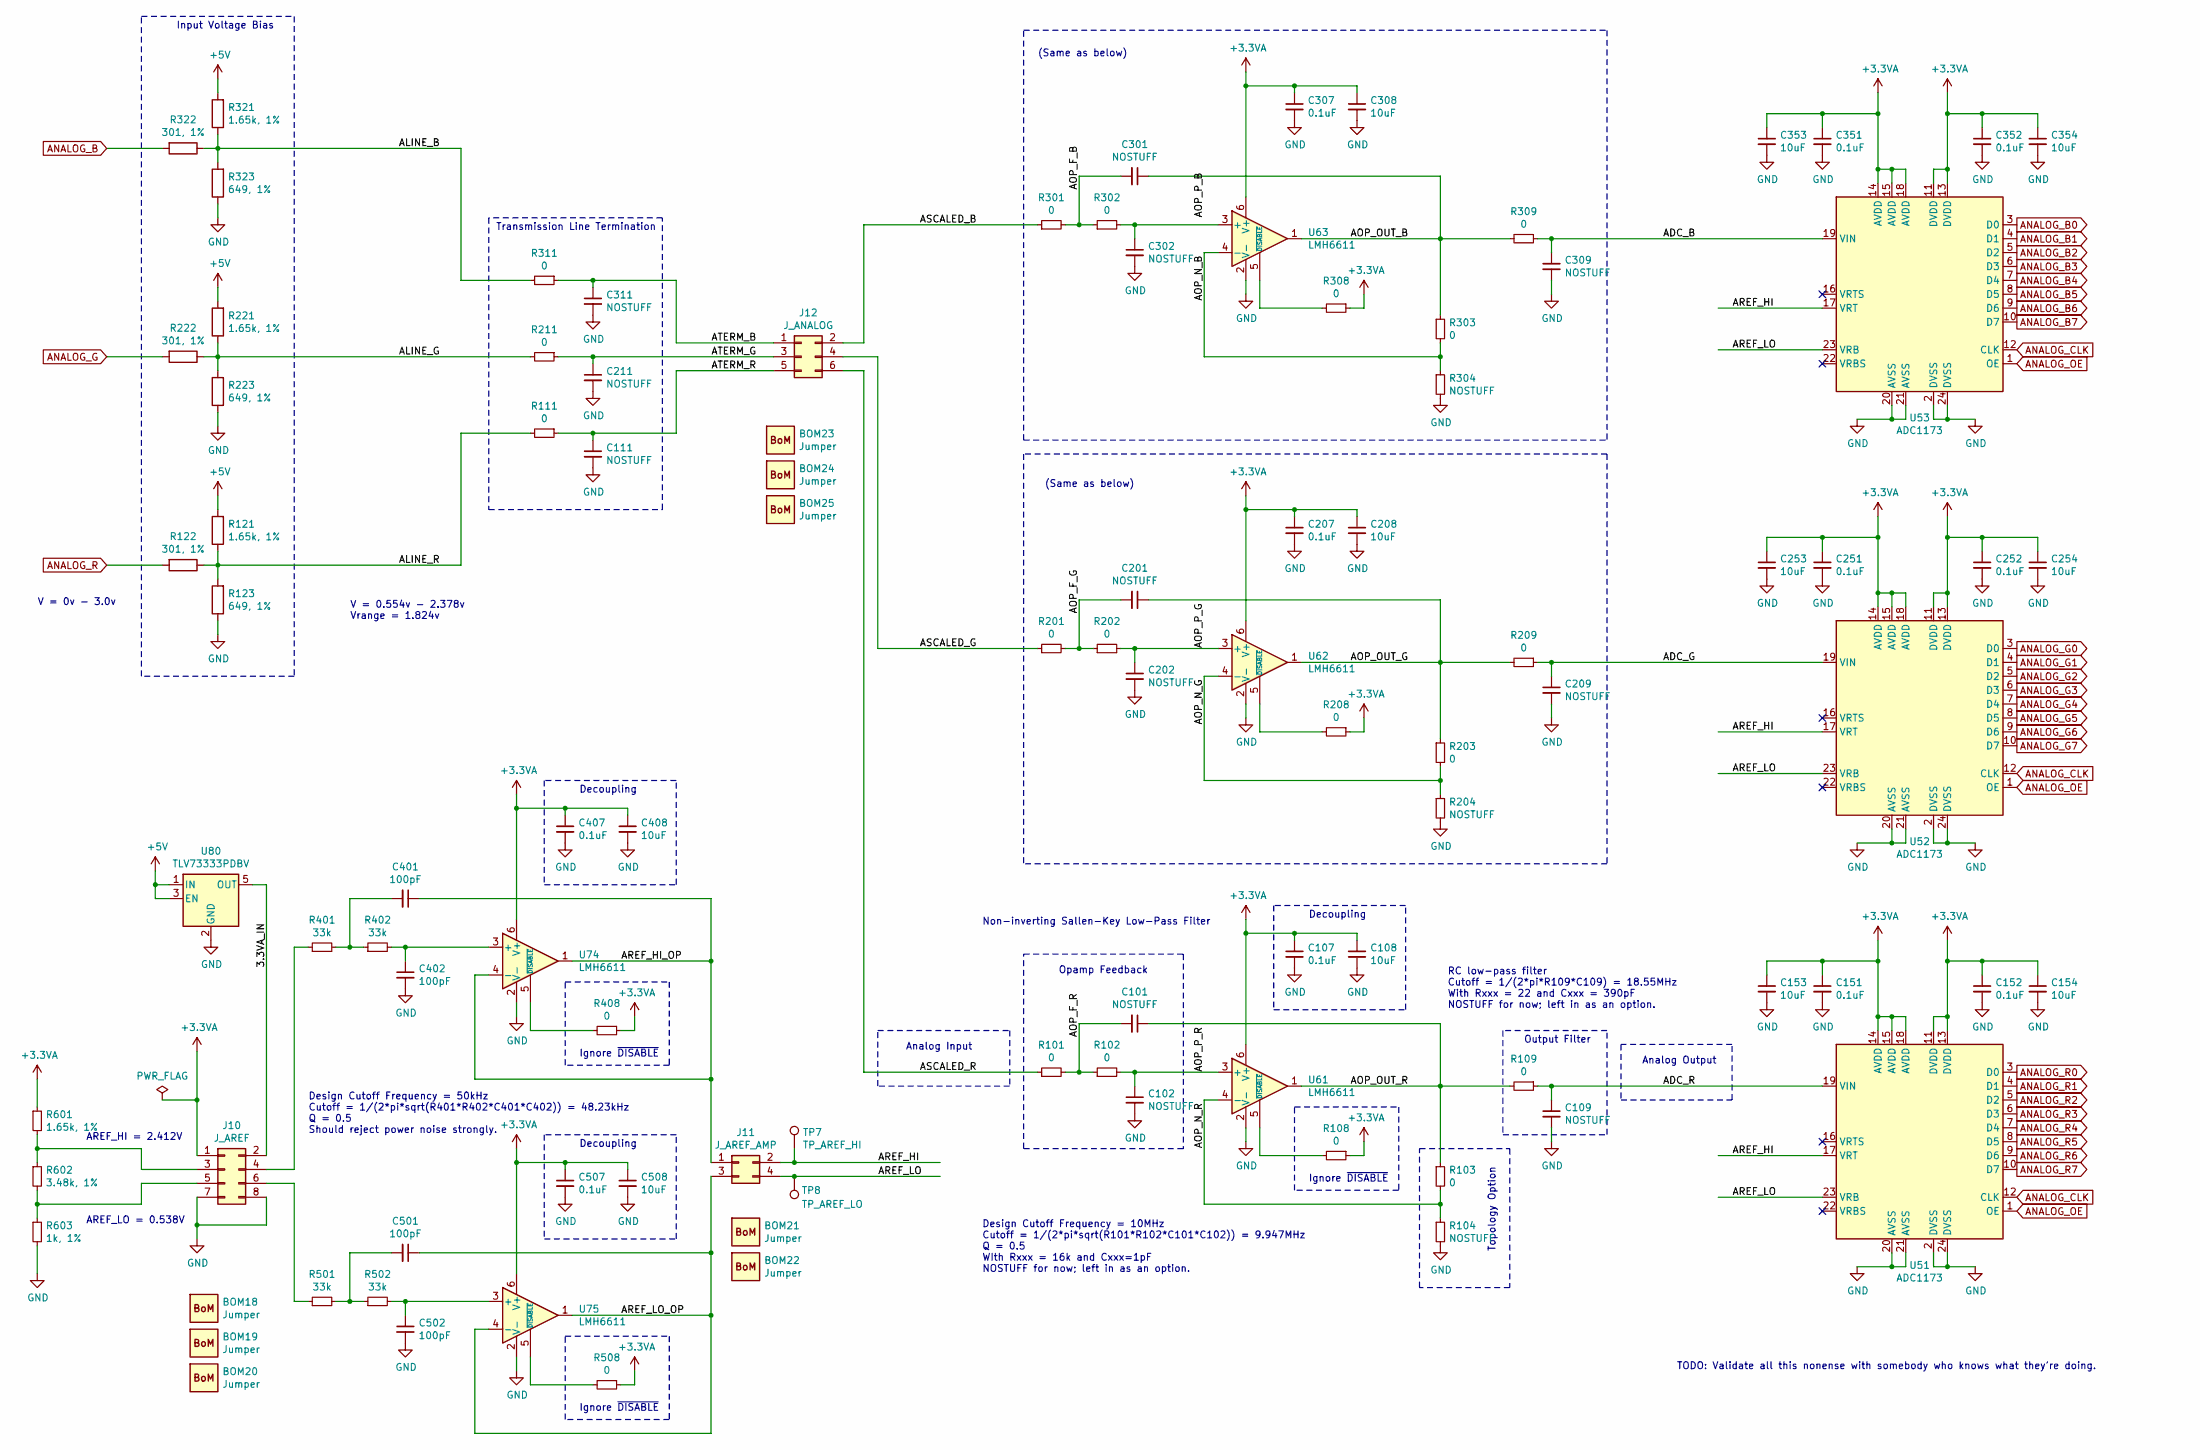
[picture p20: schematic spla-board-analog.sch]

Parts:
BOM18, BOM19, BOM20, BOM21, BOM22, BOM23, BOM24, BOM25: Jumper; BoM; Digikey S9337-ND
C101, C102, C109, C111, C201, C202, C209, C211, C301, C302, C309, C311: NOSTUFF; C_0603_1608Metric; Digikey N/A
C107, C151, C152, C207, C251, C252, C307, C351, C352, C407, C507: 0.1uF; C_0603_1608Metric; Digikey 490-16477-1-ND
C108, C153, C154, C208, C253, C254, C308, C353, C354, C408, C508: 10uF; C_0603_1608Metric; Digikey 490-12538-1-ND
C401, C402, C501, C502: 100pF; C_0603_1608Metric; Digikey 490-4771-1-ND
J10: J_AREF; PinHeader_2x04_P2.54mm_Vertical; Digikey S2011EC-40-ND
J11: J_AREF_AMP; PinHeader_2x02_P2.54mm_Vertical; Digikey S2011EC-40-ND
J12: J_ANALOG; PinHeader_2x03_P2.54mm_Vertical; Digikey S2011EC-40-ND
R101, R102, R103, R108, R109, R111, R201, R202, R203, R208, R209, R211, R301, R302, R303, R308, R309, R311, R408, R508: 0; R_0603_1608Metric; Digikey 2019-RK73Z1JTTDCT-ND
R104, R204, R304: NOSTUFF; R_0603_1608Metric; Digikey N/A
R121, R221, R321, R601: 1.65k, 1%; R_0603_1608Metric; Digikey RMCF0603FT1K65CT-ND
R122, R222, R322: 301, 1%; R_0603_1608Metric; Digikey RMCF0603FT301RCT-ND
R123, R223, R323: 649, 1%; R_0603_1608Metric; Digikey RMCF0603FT649RCT-ND
R401, R402, R501, R502: 33k; R_0603_1608Metric; Digikey RMCF0603JT33K0CT-ND
R602: 3.48k, 1%; R_0603_1608Metric; Digikey RMCF0603FT3K48CT-ND
R603: 1k, 1%; R_0603_1608Metric; Digikey RMCF0603FT1K00CT-ND
TP7: TP_AREF_HI; TestPoint_Pad_D1.0mm; Digikey N/A
TP8: TP_AREF_LO; TestPoint_Pad_D1.0mm; Digikey N/A
U51, U52, U53: ADC1173; TSSOP-24_4.4x7.8mm_P0.65mm; Digikey 296-35234-1-ND
U61, U62, U63, U74, U75: LMH6611; TSOT-23-6; Digikey 296-41441-1-ND
U80: TLV73333PDBV; SOT-23-5; Digikey 296-40673-1-ND

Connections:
+3.3VA: C107.1, C108.1, C151.1, C152.1, C153.1, C154.1, C207.1, C208.1, C251.1, C252.1, C253.1, C254.1, C307.1, C308.1, C351.1, C352.1, C353.1, C354.1, C407.1, C408.1, C507.1, C508.1, J10.1, R108.1, R208.1, R308.1, R408.1, R508.1, R601.1, U51.11 (DVDD), U51.13 (DVDD), U51.14 (AVDD), U51.15 (AVDD), U51.18 (AVDD), U52.11 (DVDD), U52.13 (DVDD), U52.14 (AVDD), U52.15 (AVDD), U52.18 (AVDD), U53.11 (DVDD), U53.13 (DVDD), U53.14 (AVDD), U53.15 (AVDD), U53.18 (AVDD), U61.6 (V+), U62.6 (V+), U63.6 (V+), U74.6 (V+), U75.6 (V+)
+5V: R121.2, R221.2, R321.2, U80.1 (IN), U80.3 (EN); also elsewhere on the board
/SPLA Board - Analog/3.3VA_IN: J10.2, U80.5 (OUT)
/SPLA Board - Analog/ADC_B: C309.1, R309.1, U53.19 (VIN)
/SPLA Board - Analog/ADC_G: C209.1, R209.1, U52.19 (VIN)
/SPLA Board - Analog/ADC_R: C109.1, R109.1, U51.19 (VIN)
/SPLA Board - Analog/ALINE_B: R311.2, R321.1, R322.1, R323.2
/SPLA Board - Analog/ALINE_G: R211.2, R221.1, R222.1, R223.2
/SPLA Board - Analog/ALINE_R: R111.2, R121.1, R122.1, R123.2
/SPLA Board - Analog/AOP_F_B: C301.2, R301.2, R302.1
/SPLA Board - Analog/AOP_F_G: C201.2, R201.2, R202.1
/SPLA Board - Analog/AOP_F_R: C101.2, R101.2, R102.1
/SPLA Board - Analog/AOP_N_B: R303.2, R304.1, U63.4 (-)
/SPLA Board - Analog/AOP_N_G: R203.2, R204.1, U62.4 (-)
/SPLA Board - Analog/AOP_N_R: R103.2, R104.1, U61.4 (-)
/SPLA Board - Analog/AOP_OUT_B: C301.1, R303.1, R309.2, U63.1
/SPLA Board - Analog/AOP_OUT_G: C201.1, R203.1, R209.2, U62.1
/SPLA Board - Analog/AOP_OUT_R: C101.1, R103.1, R109.2, U61.1
/SPLA Board - Analog/AOP_P_G: C202.1, R202.2, U62.3 (+)
/SPLA Board - Analog/AOP_P_R: C102.1, R102.2, U61.3 (+)
/SPLA Board - Analog/AREF_HI: J11.2, TP7.1, U51.17 (VRT), U52.17 (VRT), U53.17 (VRT)
/SPLA Board - Analog/AREF_HI_OP: C401.1, J11.1, U74.1, U74.4 (-)
/SPLA Board - Analog/AREF_LO: J11.4, TP8.1, U51.23 (VRB), U52.23 (VRB), U53.23 (VRB)
/SPLA Board - Analog/AREF_LO_OP: C501.1, J11.3, U75.1, U75.4 (-)
/SPLA Board - Analog/ASCALED_B: J12.2, R301.1
/SPLA Board - Analog/ASCALED_G: J12.4, R201.1
/SPLA Board - Analog/ASCALED_R: J12.6, R101.1
/SPLA Board - Analog/ATERM_B: C311.1, J12.1, R311.1
/SPLA Board - Analog/ATERM_G: C211.1, J12.3, R211.1
/SPLA Board - Analog/ATERM_R: C111.1, J12.5, R111.1
ANALOG_B: R322.2; also elsewhere on the board
ANALOG_B0: U53.3 (D0); also elsewhere on the board
ANALOG_B1: U53.4 (D1); also elsewhere on the board
ANALOG_B2: U53.5 (D2); also elsewhere on the board
ANALOG_B3: U53.6 (D3); also elsewhere on the board
ANALOG_B4: U53.7 (D4); also elsewhere on the board
ANALOG_B5: U53.8 (D5); also elsewhere on the board
ANALOG_B6: U53.9 (D6); also elsewhere on the board
ANALOG_B7: U53.10 (D7); also elsewhere on the board
ANALOG_CLK: U51.12 (CLK), U52.12 (CLK), U53.12 (CLK); also elsewhere on the board
ANALOG_G: R222.2; also elsewhere on the board
ANALOG_G0: U52.3 (D0); also elsewhere on the board
ANALOG_G1: U52.4 (D1); also elsewhere on the board
ANALOG_G2: U52.5 (D2); also elsewhere on the board
ANALOG_G3: U52.6 (D3); also elsewhere on the board
ANALOG_G4: U52.7 (D4); also elsewhere on the board
ANALOG_G5: U52.8 (D5); also elsewhere on the board
ANALOG_G6: U52.9 (D6); also elsewhere on the board
ANALOG_G7: U52.10 (D7); also elsewhere on the board
ANALOG_OE: U51.1 (OE), U52.1 (OE), U53.1 (OE); also elsewhere on the board
ANALOG_R: R122.2; also elsewhere on the board
ANALOG_R0: U51.3 (D0); also elsewhere on the board
ANALOG_R1: U51.4 (D1); also elsewhere on the board
ANALOG_R2: U51.5 (D2); also elsewhere on the board
ANALOG_R3: U51.6 (D3); also elsewhere on the board
ANALOG_R4: U51.7 (D4); also elsewhere on the board
ANALOG_R5: U51.8 (D5); also elsewhere on the board
ANALOG_R6: U51.9 (D6); also elsewhere on the board
ANALOG_R7: U51.10 (D7); also elsewhere on the board
GND: C102.2, C107.2, C108.2, C109.2, C111.2, C151.2, C152.2, C153.2, C154.2, C202.2, C207.2, C208.2, C209.2, C211.2, C251.2, C252.2, C253.2, C254.2, C302.2, C307.2, C308.2, C309.2, C311.2, C351.2, C352.2, C353.2, C354.2, C402.2, C407.2, C408.2, C502.2, C507.2, C508.2, J10.7, J10.8, R104.2, R123.1, R204.2, R223.1, R304.2, R323.1, R603.2, U51.2 (DVSS), U51.20 (AVSS), U51.21 (AVSS), U51.24 (DVSS), U52.2 (DVSS), U52.20 (AVSS), U52.21 (AVSS), U52.24 (DVSS), U53.2 (DVSS), U53.20 (AVSS), U53.21 (AVSS), U53.24 (DVSS), U61.2 (V-), U62.2 (V-), U63.2 (V-), U74.2 (V-), U75.2 (V-), U80.2 (GND); also elsewhere on the board
unnamed: C302.1, R302.2, U63.3 (+)
unnamed: C401.2, R401.2, R402.1
unnamed: C402.1, R402.2, U74.3 (+)
unnamed: C501.2, R501.2, R502.1
unnamed: C502.1, R502.2, U75.3 (+)
unnamed: J10.3, R601.2, R602.1
unnamed: J10.4, R401.1
unnamed: J10.5, R602.2, R603.1
unnamed: J10.6, R501.1
unnamed: R108.2, U61.5 (~DISABLE)
unnamed: R208.2, U62.5 (~DISABLE)
unnamed: R308.2, U63.5 (~DISABLE)
unnamed: R408.2, U74.5 (~DISABLE)
unnamed: R508.2, U75.5 (~DISABLE)

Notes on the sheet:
AREF_HI = 2.412V
AREF_LO = 0.538V
V = 0v - 3.0v
TODO: Validate all this nonense with somebody who knows what they're doing.
Output Filter
Decoupling
Analog Input
Transmission Line Termination
Ignore ~DISABLE~
Topology Option
Opamp Feedback
Analog Output
Design Cutoff Frequency = 10MHz Cutoff = 1/(2*pi*sqrt(R101*R102*C101*C102)) = 9.947MHz Q = 0.5 WIth Rxxx = 16k and Cxxx=1pF NOSTUFF for now; left in as an option.
RC low-pass filter Cutoff = 1/(2*pi*R109*C109) = 18.55MHz With Rxxx = 22 and Cxxx = 390pF NOSTUFF for now; left in as an option.
Non-inverting Sallen-Key Low-Pass Filter
(Same as below)
V = 0.554v - 2.378v Vrange = 1.824v
Input Voltage Bias
Design Cutoff Frequency = 50kHz Cutoff = 1/(2*pi*sqrt(R401*R402*C401*C402)) = 48.23kHz Q = 0.5 Should reject power noise strongly.

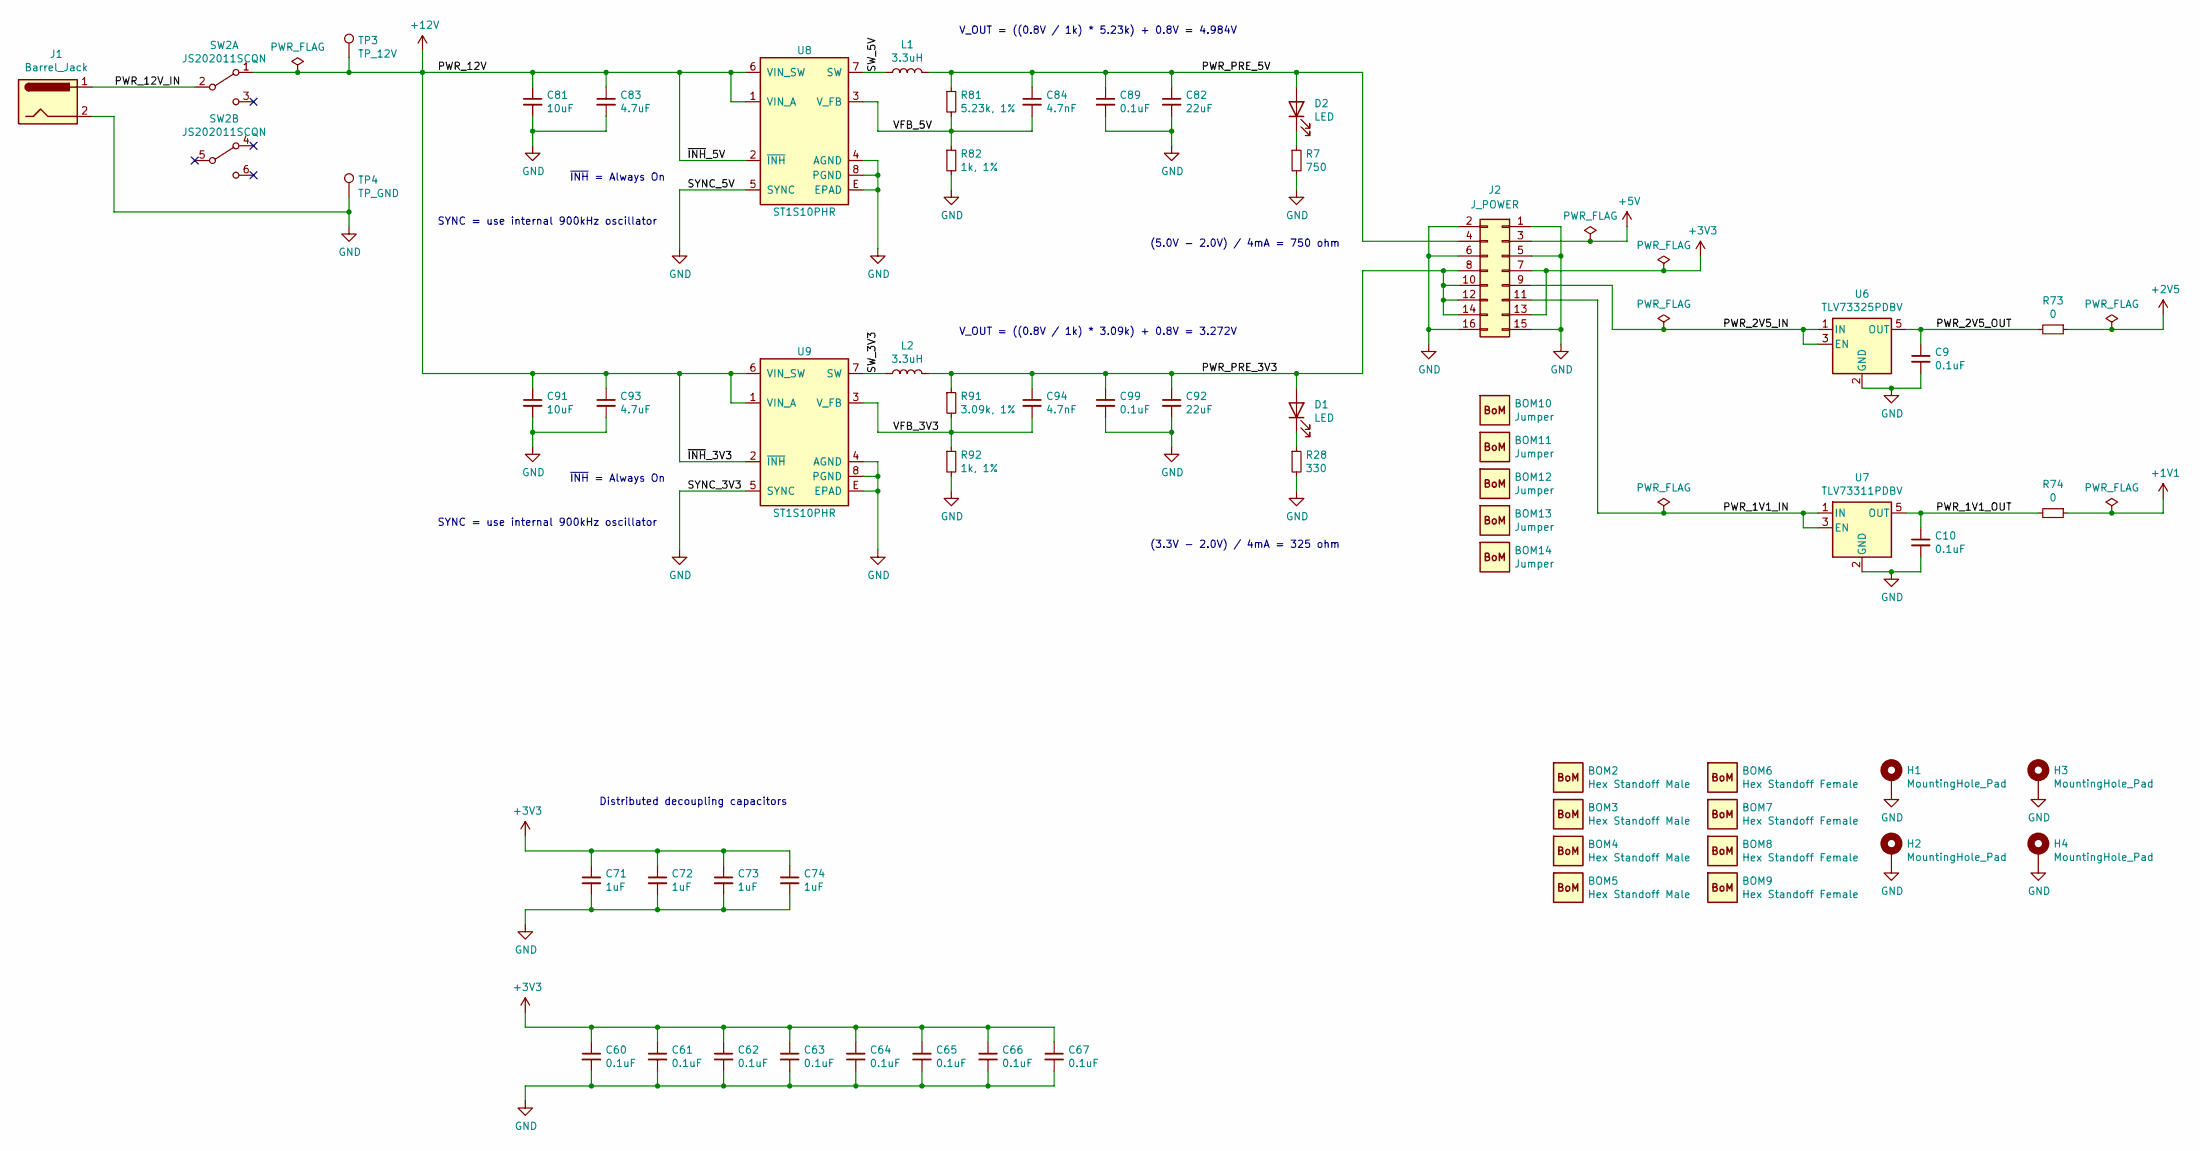
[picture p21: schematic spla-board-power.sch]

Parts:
BOM2, BOM3, BOM4, BOM5: Hex Standoff Male; BoM; Digikey 732-12817-ND
BOM6, BOM7, BOM8, BOM9: Hex Standoff Female; BoM; Digikey 732-12802-ND
BOM10, BOM11, BOM12, BOM13, BOM14: Jumper; BoM; Digikey S9337-ND
C9, C10, C60, C61, C62, C63, C64, C65, C66, C67, C89, C99: 0.1uF; C_0603_1608Metric; Digikey 490-16477-1-ND
C71, C72, C73, C74: 1uF; C_0603_1608Metric; Digikey 490-12699-1-ND
C81, C91: 10uF; C_0805_2012Metric; Digikey 490-10516-1-ND
C82, C92: 22uF; C_0805_2012Metric; Digikey 490-10511-1-ND
C83, C93: 4.7uF; C_0603_1608Metric; Digikey 490-7203-1-ND
C84, C94: 4.7nF; C_0805_2012Metric; Digikey 490-8289-1-ND
D1, D2: LED; LED_0805_2012Metric; Digikey 732-4986-1-ND
H1, H2, H3, H4: MountingHole_Pad; MountingHole_3.2mm_M3_Pad; Digikey N/A
J1: Barrel_Jack; BarrelJack_CUI_PJ-036AH-SMT_Horizontal; Digikey CP-036AHPJCT-ND
J2: J_POWER; PinHeader_2x08_P2.54mm_Vertical; Digikey S2011EC-40-ND
L1, L2: 3.3uH; L_Vishay_IHLP-2020; Digikey 541-1237-1-ND
R7: 750; R_0603_1608Metric; Digikey RMCF0603JT750RCT-ND
R28: 330; R_0603_1608Metric; Digikey RMCF0603JT330RCT-ND
R73, R74: 0; R_0603_1608Metric; Digikey 2019-RK73Z1JTTDCT-ND
R81: 5.23k, 1%; R_0603_1608Metric; Digikey RMCF0603FT5K23CT-ND
R82, R92: 1k, 1%; R_0603_1608Metric; Digikey RMCF0603FT1K00CT-ND
R91: 3.09k, 1%; R_0603_1608Metric; Digikey RMCF0603FT3K09CT-ND
SW2: JS202011SCQN; Digikey 401-2002-1-ND
TP3: TP_12V; TestPoint_Pad_D2.0mm; Digikey N/A
TP4: TP_GND; TestPoint_Pad_D2.0mm; Digikey N/A
U6: TLV73325PDBV; SOT-23-5; Digikey 296-40671-1-ND
U7: TLV73311PDBV; SOT-23-5; Digikey 296-40663-1-ND
U8, U9: ST1S10PHR; ST_PowerSO-8EP_4x5mm_P1.27mm_EP3.5x2.6mm; Digikey 497-6904-1-ND

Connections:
+1V1: R74.1; also elsewhere on the board
+2V5: R73.1; also elsewhere on the board
+5V: J2.3; also elsewhere on the board
+12V: C81.1, C83.1, C91.1, C93.1, SW2.1 (A), TP3.1, U8.1 (VIN_A), U8.2 (~INH), U8.6 (VIN_SW), U9.1 (VIN_A), U9.2 (~INH), U9.6 (VIN_SW)
/SPLA Board - Power/PWR_1V1_IN: J2.11, U7.1 (IN), U7.3 (EN)
/SPLA Board - Power/PWR_1V1_OUT: C10.1, R74.2, U7.5 (OUT)
/SPLA Board - Power/PWR_2V5_IN: J2.9, U6.1 (IN), U6.3 (EN)
/SPLA Board - Power/PWR_2V5_OUT: C9.1, R73.2, U6.5 (OUT)
/SPLA Board - Power/PWR_12V_IN: J1.1, SW2.2 (B)
/SPLA Board - Power/PWR_PRE_3V3: C92.1, C94.1, C99.1, D1.2 (A), J2.8, J2.10, J2.12, J2.14, L2.2, R91.1
/SPLA Board - Power/PWR_PRE_5V: C82.1, C84.1, C89.1, D2.2 (A), J2.4, L1.2, R81.1
/SPLA Board - Power/SW_3V3: L2.1, U9.7 (SW)
/SPLA Board - Power/SW_5V: L1.1, U8.7 (SW)
/SPLA Board - Power/VFB_3V3: C94.2, R91.2, R92.1, U9.3 (V_FB)
/SPLA Board - Power/VFB_5V: C84.2, R81.2, R82.1, U8.3 (V_FB)
GND: C9.2, C10.2, C60.2, C61.2, C62.2, C63.2, C64.2, C65.2, C66.2, C67.2, C71.2, C72.2, C73.2, C74.2, C81.2, C82.2, C83.2, C89.2, C91.2, C92.2, C93.2, C99.2, H1.1, H2.1, H3.1, H4.1, J1.2, J2.1, J2.2, J2.5, J2.6, J2.15, J2.16, R7.2, R28.2, R82.2, R92.2, TP4.1, U6.2 (GND), U7.2 (GND), U8.4 (AGND), U8.5 (SYNC), U8.8 (PGND), U8.E (EPAD), U9.4 (AGND), U9.5 (SYNC), U9.8 (PGND), U9.E (EPAD); also elsewhere on the board
unnamed: D1.1 (K), R28.1
unnamed: D2.1 (K), R7.1

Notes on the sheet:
SYNC = use internal 900kHz oscillator
V_OUT = ((0.8V / 1k) * 5.23k) + 0.8V = 4.984V
~INH~ = Always On
V_OUT = ((0.8V / 1k) * 3.09k) + 0.8V = 3.272V
(5.0V - 2.0V) / 4mA = 750 ohm
(3.3V - 2.0V) / 4mA = 325 ohm
Distributed decoupling capacitors

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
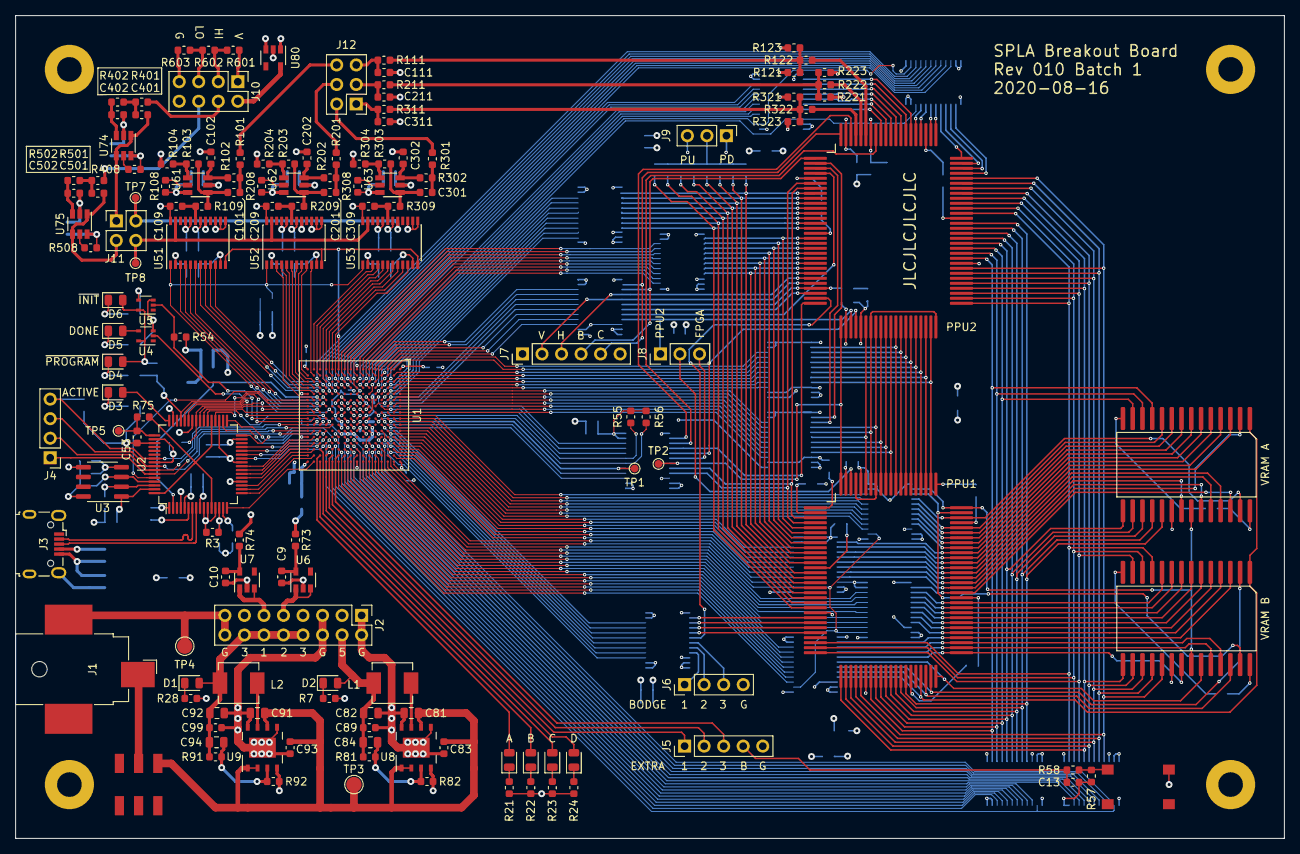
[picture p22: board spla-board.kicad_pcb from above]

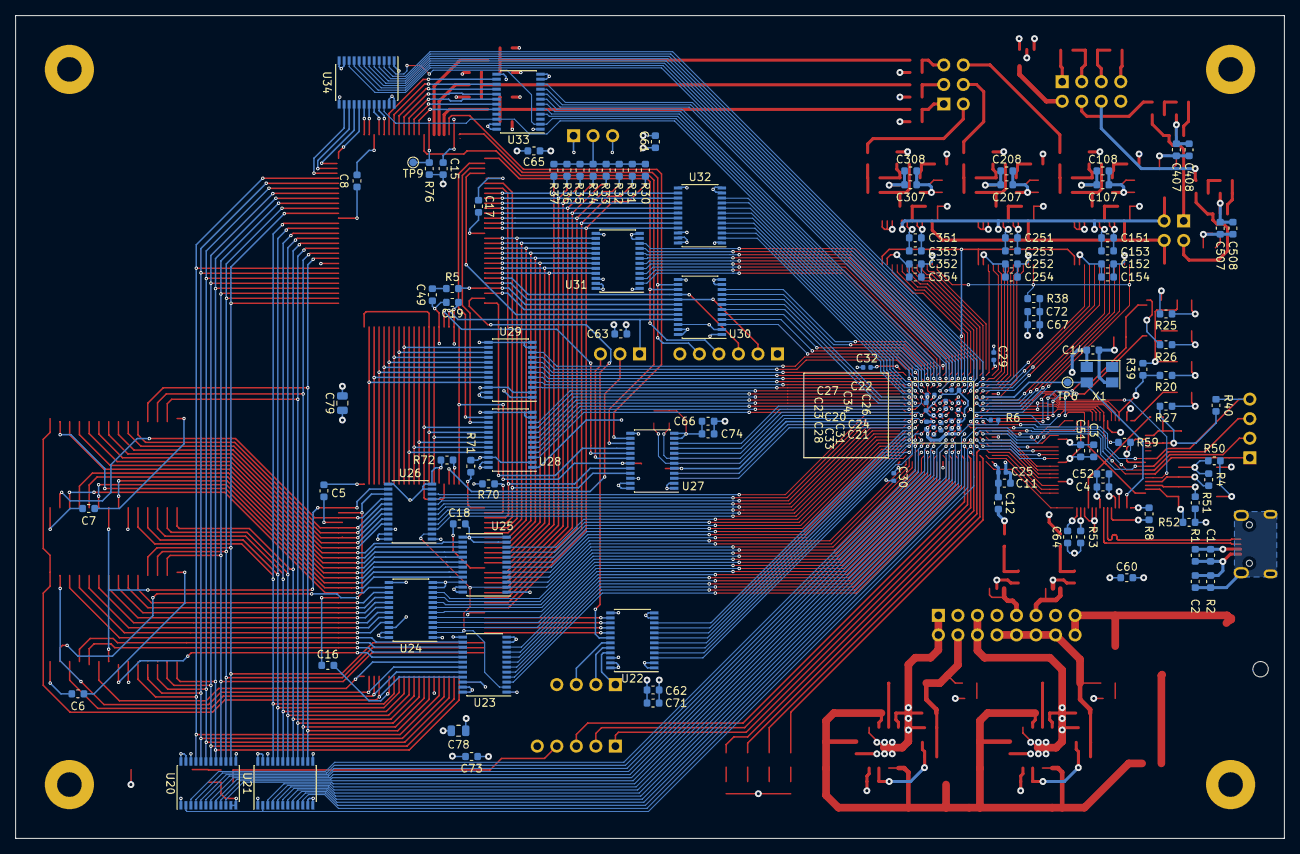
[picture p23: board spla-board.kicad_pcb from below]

Board: 4 copper layers, 165.0 x 107.0 mm, 290 parts (118 on the bottom side), 404 nets.

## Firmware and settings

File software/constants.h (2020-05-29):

// vi: ts=2:sw=2:sts=2:et

// See https://github.com/obdev/v-usb/blob/master/usbdrv/USB-IDs-for-free.txt
#define DEFAULT_VENDOR_ID 0x16c0
#define DEFAULT_PRODUCT_ID 0x05dc

#define DEFAULT_MANUFACTURER "SPLA"
#define DEFAULT_DESCRIPTION "SPLA Breakout Board"

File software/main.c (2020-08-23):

// vi: ts=2:sw=2:sts=2:et

#include <stdbool.h>
#include <stdio.h>
#include <string.h>
#include <unistd.h>

#include "command.h"
#include "ftdiutil.h"

status global_flag(int argc, char** argv, int* absorbed) {
  if (!strcmp(argv[0], "--device")) {
    if (argc < 2) {
      return errorf("Missing argument to '--device'.");
    } else {
      // TODO: Parse some format in ftdiutil_set_usb_device
      // TODO: fix this flag to match ftdi_list_devices
      ftdiutil_set_usb_device(argv[1]);
      *absorbed = 2;
      return OK;
    }
  }
  if (!strcmp(argv[0], "--debug")) {
    ftdiutil_debug_logging(true);
    *absorbed = 1;
    return OK;
  }
  return errorf("Unknown flag: %s", argv[0]);
}

void global_flag_usage() {
  fprintf(stderr, "  %-24s  %s\n", "--device",
          "Select FTDI USB device to use.");
}

static status invoke_command(int argc, char** argv) {
  const char* command_name = argv[0];
  struct command* cmd = find_command(command_name);
  if (!cmd) {
    return errorf("Unknown subcommand \"%s\". Try \"%s help\".\n", command_name,
                  invoked_as);
  }
  RETURN_IF_ERROR(ftdiutil_init());
  status err;
  if (cmd->default_usb_device) {
    ftdiutil_set_default_usb_device(cmd->default_usb_device);
  }
  if (cmd->open_usb) {
    RETURN_IF_ERROR(ftdiutil_open_usb());
  }
  err = cmd->fn(argc - 1, argv + 1);
  if (cmd->open_usb) {
    status_ignore(ftdiutil_close_usb());
  }
  ftdiutil_deinit();
  return err;
}

int main(int argc, char** argv) {
  // Skip over invoked filename
  invoked_as = argv[0];
  argc--;
  argv++;
  // Scan for arguments
  while (argc > 0) {
    const char* arg = argv[0];
    if (arg[0] == '-') {
      int absorbed;
      status err = global_flag(argc, argv, &absorbed);
      if (is_error(err)) {
        fprintf(stderr, "%s\n", err->message);
        status_free(err);
        return 1;
      }
      argc -= absorbed;
      argv += absorbed;
    } else {
      status err = invoke_command(argc, argv);
      if (is_error(err)) {
        fflush(stdout);
        fprintf(stderr, "%s\n", err->message);
        status_free(err);
        return 1;
      }
      return 0;
    }
  }
  status_ignore(usage());
  return 0;
}

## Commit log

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2020-02-17 schematic: Swap R_US for R.
    [spla-board.sch]
2020-02-17 schematic: Swap GNDREF for GND.
    [spla-board.sch]
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2020-02-17 schematic: Add PPU1 / PPU2 / VRAM schematic.
    [spla-board-ppu.sch, spla-board-usb.sch, spla-board.sch]
2020-02-17 schematic: Add FPGA and Analog pages; tweak others.
    [spla-board-analog.sch, spla-board-fpga.sch, spla-board-ppu.sch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]
2020-02-19 schematic: Fix various board details.
    [spla-board-analog.sch, spla-board-fpga.sch, spla-board-ppu.sch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]
2020-02-20 schematic: Fix minor issues with PPU etc.
    * Align root page objects.
    * Remove reset logic from PPU page (was wrong, and will go elsewhere).
    * Fix naming of note on FT2232HL part.
    * Name TAP_PPU2_~RESOUT1~ correctly.
    * Add decoupling capacitors for PPU and VRAM parts.
    [spla-board-ppu.sch, spla-board-usb.sch, spla-board.sch]
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2020-02-20 schematic: Fix ~WE pin number for VRAM chip.
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2020-02-22 schematic: Add blank sheets for future components; rearrange root sheet.
    [spla-board-analog.sch, spla-board-level-shifters.sch, spla-board-power.sch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]
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2020-02-22 schematic: Add the FIFO and SPI to FT2232H's buses.
    [spla-board-usb.sch]
2020-02-22 schemtaic: Correct global flag types in PPU.
    [spla-board-ppu.sch]
2020-02-23 schematic: Add level shifters and PPU reset jumpers.
    [spla-board-level-shifters.sch, spla-board-ppu.sch, spla-board-usb.sch]
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2020-02-26 schematic: Replace 12MHz osciallator with a real part.
    [spla-board-usb.sch]
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2020-02-26 schematic: Add ECP5 symbols (not hooked up yet).
    [spla-board-fpga.sch]
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2020-02-26 schematic: Add power based on a 5V source with TLV733P and MIC2025.
    [spla-board-power.sch, spla-board.sch]
2020-02-26 schematic: Move around a bunch of IC labels.
    [spla-board-level-shifters.sch, spla-board-usb.sch, spla-board.sch]
2020-02-26 schematic: Add correct analog parts. (Actually the stand-ins were the right part, ironically)
    [spla-board-analog.sch]
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2020-02-26 schematic: Change all pages to A3; open up layout for level shifters.
    [spla-board-analog.sch, spla-board-level-shifters.sch, spla-board-power.sch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]
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2020-02-27 schematic: Many updates.
    * Hook up all signals to the FPGA, prior to (manual) pinmapping.
    * Hook up FPGA initialization logic, in SPI Slave mode.
    * Rotate USB connector to avoid D+/D- swapover.
    * Fix pin number 41/44 mishap in PPU-2.
    * Add power flags in a bunch of places.
    * Fix TST* inputs in PPU-2 to be passive (which is wrong, but good enough)
    * Fix naming of several TAP_* signals to FPGA_*
    * Fix PPU bus wires (all signals must be explicitly named).
    * Hook up JTAG pins to Ultradebug (not in the MPSSE location, since it's
    taken already by SPI, and JTAG can afford to be horrifically slow).
    * Fix all remaining ERC problems, including typo'd signal names.
    [spla-board-analog.sch, spla-board-fpga.sch, spla-board-level-shifters.sch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]
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2020-02-29 schematic: Add pullup / pulldown resistors to JTAG.
    [spla-board-fpga.sch]
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2020-02-29 schematic/pcb: First layout excersize; add footprints; tweak pin order on periphreal bus level shifters.
    [spla-board-analog.sch, spla-board-fpga.sch, spla-board-level-shifters.sch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]
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2020-03-01 schematic/pcb: Swap several footprints; rearrange pcb layout again.
    [spla-board-analog.sch, spla-board-fpga.sch, spla-board-level-shifters.sch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]
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2020-03-06 all: Correct spelling of 'peripheral'.
    [pin-estimation.csv, spla-board-level-shifters.sch, spla-board-ppu.sch]
2020-03-06 schematic: Add pullup/pulldown jumper for peripheral data bus.
    [spla-board-ppu.sch]
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2020-03-09 schematic: Swap 0402 footprints for 0603.
    [spla-board-analog.sch, spla-board-fpga.sch, spla-board-power.sch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]
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2020-03-11 schematic: Hook up TST pins to FPGA (via level shifters).
    [spla-board-fpga.sch, spla-board-level-shifters.sch, spla-board-ppu.sch]
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2020-03-11 todo: Fix analog voltage reference.
2020-03-11 schematic: Remove SRAM, since I don't have the pins for it anyways.
    [spla-board-analog.sch, spla-board-fpga.sch, spla-board-level-shifters.sch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]
2020-03-11 schematic: Correct ADC bus width.
    [spla-board.sch]
2020-03-11 pcb: More layout work. Some routes, mostly flipping and arrangement.
    [spla-board.kicad_pcb]
2020-03-11 schematic/pcb: Reorder VRAM address bus pins; adjust pcb layout.
    [spla-board-level-shifters.sch, spla-board.kicad_pcb]
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2020-03-16 pcb: Almost done with BGA breakout. Some pins won't be usable...
    [spla-board.kicad_pcb]
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2020-03-22 footprint: Fixup QFP-100 footprint measurements.
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2020-03-22 schematic: Lable bodge jumper.
    [spla-board-level-shifters.sch]
2020-03-22 pcb: Rearrange layout; update footprints; delete bogus traces.
    [spla-board.kicad_pcb]
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2020-03-29 pcb/schematic: Layout FPGA/FTDI so that FIFO connects are reasonable.
    [spla-board-fpga.sch, spla-board-usb.sch, spla-board.kicad_pcb]
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2020-03-29 pcb: Adjust analog complex slight; needs fixing and relayout.
    [spla-board.kicad_pcb]
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2020-04-02 pcb: Connect FTDI reset; other tweaks.
    [spla-board.kicad_pcb]
2020-04-02 pcb: Align SNES PPU / VRAM chips, and lock. Adjust level shifter ordering.
    [spla-board.kicad_pcb]
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2020-04-02 schematic: Swap TXS0108E for 74LVC8245.
    [spla-board-fpga.sch, spla-board-level-shifters.sch]
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2020-04-02 pcb: Partial, experimental layout of VRAM address bus.
    [spla-board.kicad_pcb]
2020-04-02 pcb: Finish layout of VRAM address and data buses.
    [spla-board.kicad_pcb]
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2020-04-03 pcb: Add VDA/VDB FPGA-side breakout; tweak decoupling capacitors.
    [spla-board.kicad_pcb]
2020-04-03 pcb/schematic: Adjust reset jumper.
    [spla-board-ppu.sch, spla-board.kicad_pcb]
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2020-04-04 pcb: Add approximate counts of pins incoming to FPGA, for later pinmapping.
    [spla-board.kicad_pcb]
2020-04-04 pcb/footprint: Extend VRAM SOP-28 footprint pads by 0.8mm; adjust layout to suit.
    Recommended by @awygle; this ought to make hand-soldering easier as well.
    [spla-board.kicad_pcb]
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2020-04-04 pcb: Route out two additional bottom-layer FPGA pins.
    [spla-board.kicad_pcb]
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2020-04-05 symbol/footprint/schematic: Redo power entirely to use ST1S10 and TLV733 parts.
    [spla-board-fpga.sch, spla-board-power.sch]
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2020-04-05 schematic/pcb: Rearrange 2.5V/1.1V jumpers; Move USB data liens to make space for power.
    [spla-board-power.sch, spla-board-usb.sch, spla-board.kicad_pcb]
2020-04-06 pcb/schematic: Layout new power setup; tweak schematic to suit.
    [spla-board-power.sch, spla-board.kicad_pcb]
2020-04-06 schematic/pcb: Add LEDs to FTDI / FPGA / Power, for bringup and debugging.
    [spla-board-fpga.sch, spla-board-power.sch, spla-board-usb.sch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]
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2020-04-06 pcb: Extend by 1mm to allow more margin around traces.
    [spla-board.kicad_pcb]
2020-04-06 pcb: Pull in VRAM chips by 7mm to save space.
    [spla-board.kicad_pcb]
2020-04-06 pcb: Fix DRC errors.
    [spla-board.kicad_pcb]
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2020-04-06 pcb/schematic: Add split power planes for 3.3V and 5V.
    [spla-board-fpga.sch, spla-board.kicad_pcb]
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2020-04-08 pcb: Widen some bus layout that's tighter than necessary.
    Suggested by @rrrabarbaro.
    [spla-board.kicad_pcb]
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2020-04-08 schematic: Correct ERC errors.
    [spla-board-fpga.sch, spla-board-level-shifters.sch, spla-board-power.sch]
2020-04-09 schematic/pcb: Hook up PED and TOUMEI; Add test point for EXTLATCH.
    [spla-board-fpga.sch, spla-board-level-shifters.sch, spla-board-ppu.sch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]
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2020-04-09 pcb: Fix grounding of barrel jack.
    [spla-board.kicad_pcb]
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2020-04-09 schematic/pcb: Simplify reset jumpers; relax layout to suit.
    [spla-board-level-shifters.sch, spla-board-ppu.sch, spla-board.kicad_pcb]
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2020-04-09 schematic/pcb: Hook up EXTLATCH, dropping BODGE4.
    [spla-board-fpga.sch, spla-board-level-shifters.sch, spla-board.kicad_pcb]
2020-04-09 schematic/pcb: Add jumper pins to tap HBLANK / VBLANK / BURST / CSYNC.
    [spla-board-level-shifters.sch, spla-board.kicad_pcb]
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2020-04-10 schematic: Partial rework of analog to use LMH6611 + ADC1173.
    [spla-board-analog.sch]
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2020-04-11 schematic: Fix analog values for 50MHz filter; correct symbol orientation.
    [spla-board-analog.sch]
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2020-04-12 schematic: Rework analog block again; plausibly complete now.
    [spla-board-analog.sch, spla-board-fpga.sch]
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2020-04-13 pcb: Fix DRC error.
    [spla-board.kicad_pcb]
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2020-04-17 schematic/pcb: Add LEDs for FPGA status signals; rework layout to suit.
    [spla-board-analog.sch, spla-board-fpga.sch, spla-board-power.sch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]
2020-04-17 pcb: Rework layout around FT2232H.
    [spla-board.kicad_pcb]
2020-04-17 schematic/pcb: Add FPGA decoupling capacitors.
    I can't find enough space to add enough 3.3v decoupling, so I'll have to
    scatter some extras around the board.
    [spla-board-fpga.sch, spla-board.kicad_pcb]
2020-04-17 schematic/pcb: Give up on remaining FPGA decoupling; Add distributed decoupling to hopefully mitigate.
    [spla-board-fpga.sch, spla-board-power.sch, spla-board.kicad_pcb]
2020-04-17 pcb: Fix FPGA capacitors silkscreen.
    [spla-board.kicad_pcb]
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2020-04-19 schematic: Fix SPI pin directions.
    [spla-board-fpga.sch, spla-board-usb.sch]
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2020-04-23 schematic: Fix typo'd resistor value.
    [spla-board-analog.sch]
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2020-04-25 schematic: Add part numbers for pinheaders (albeit that these are breakaways, and it's not one-per-part).
    [spla-board-analog.sch, spla-board-fpga.sch, spla-board-level-shifters.sch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]
2020-04-25 schematic/pcb: Swap oscillator for FOX924 equivalent.
    [spla-board-usb.sch, spla-board.kicad_pcb]
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2020-04-26 schematic/pcb: Move PPU RESET pulldowns before level shifter.
    [spla-board-level-shifters.sch, spla-board-ppu.sch, spla-board-usb.sch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]
2020-04-27 schematic/pcb: Complete part selection of resistors and capacitors. Omit filters in analog block for now; adjust PCB to suit.
    [spla-board-analog.sch, spla-board-fpga.sch, spla-board-level-shifters.sch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]
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2020-04-27 pcb: Widen via-to-via distances in several places to avoid plausible drill issues.
    [spla-board.kicad_pcb]
2020-04-27 pcb: Shrink power/ground fill spacing to 0.2mm around FPGA.
    The KiCad default here (0.508mm) is probably larger than necessary. Also
    remove most of the redundant traces that were trying to fix the fill not
    getting through the gaps between vias. I could apply this across the entire
    board, but that seems like a bad idea for the larger vias.
    It might be possible to reduce this further, but it's not worth the risk of an
    impossible-to-fix plane-to-via short.
    [spla-board.kicad_pcb]
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2020-05-02 accounting: Partially add hot air rework station and power bricks.
2020-05-02 software: Replace error handling with 'status' object.
    [main.c]
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2020-05-11 rtl: Switch to correct ECP device model (previoulsy typo'd).
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2020-05-15 blog: Update. Bringup phase 2; stuck on FTDI 1.8V rail.
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2020-05-21 software: Arrange ftdiutil to open both A and B interfaces.
    This requires refactoring out the buffering logic (which was good to do
    anyways), but is still awkward in the API -- there's a global state bit to
    swap. This might not be a problem in practice, but "fixing" it isn't
    immediately obvious.
    [ftdiutil.c, main.c]
2020-05-22 software: Rework bringup_ftdi to show all bad states.
    [bringup_ftdi.c]
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2020-05-22 software: Fix 'cable' open, as it doesn't have two interfaces.
    [ftdiutil.c]
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2020-05-27 software: Fix pin numbers in bringup_ftdi.
    [bringup_ftdi.c]
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2020-05-30 software: Correct MPSSE SPI opcodes; Add mpsse_transfer_data.
    [mpsse.c]
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2020-05-30 software: Tweak main to flush stdout for errors.
    [main.c]
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2020-06-18 rtl: Rewrite bringup.v to avoid driving usb pins; sample both clocks.
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2020-06-23 rtl: Swap bringup driver/sensor test points.
2020-06-25 software: Add trivial persistence to bringup_boundary, in case I crash the board while probing.
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2020-06-29 blog: Broke second board's FPGA. Oops.
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2020-08-02 rtl: Add unreset_by_uart, to avoid initial uart_rx glitch.
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2020-08-03 verif: Fix uart_rx build target.
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2020-08-12 pcb: Correct strangely routed net near U3.
    [spla-board.kicad_pcb]
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2020-08-12 schematic/pcb: Add reset "switch" via shortable resistor pads
    [spla-board-usb.sch, spla-board.kicad_pcb]
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2020-08-12 schematic/pcb: Consolidate analog output-enable nets, and add a pullup resistor.
    Note that this leaves two FPGA pins unused, which I'll need to correct later.
    [spla-board-analog.sch, spla-board-fpga.sch, spla-board.kicad_pcb]
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2020-08-14 blog: Found source of PPU footprint error.
2020-08-14 pcb: Add corrected QFP-100 footprint, with 0.65mm pin pitch.
2020-08-14 pcb/schematic: Rework layout for 0.65mm PPU footprint, as well as other minor issues.
    [spla-board-fpga.sch, spla-board-level-shifters.sch, spla-board-ppu.sch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]
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2020-08-15 schematic: Fix typo.
    [spla-board-analog.sch]
2020-08-15 schematic/pcb: Swap test points for pins; Rename LEDs.
    [spla-board-fpga.sch, spla-board.kicad_pcb]
2020-08-15 schematic/pcb: Remove J4, which is unnecessary and meltable.
    [spla-board-power.sch, spla-board.kicad_pcb]
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2020-08-15 pcb: Add a circle to button footprint, so it looks more like a button.
    [spla-board.kicad_pcb]
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2020-08-16 schematic: Swap FTDI REF resistor from 5% (oops) to 1%.
    [spla-board-usb.sch, spla-board.kicad_pcb]
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2020-08-16 bom: Update bom xml; fix reorder script for new parts.
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2020-08-16 pcb: Move button closer to corner for physical stability.
    [spla-board.kicad_pcb]
2020-08-16 schematic: Fix AVCC power flag.
    [spla-board-ppu.sch]
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2020-08-16 schematic/pcb: Invert sense of INIT LED (on == active, low).
    [spla-board-fpga.sch, spla-board.kicad_pcb]
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2020-08-17 schematic: Swap USB cable for a better (longer) one.
    [spla-board-usb.sch]
2020-08-17 schematic: Swap hex standoffs for shorter ones (3.5cm to 2.0cm).
    [spla-board-power.sch]
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2020-08-17 accounting: Fix boards HS Code details.
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2020-08-23 todo: Discovered that FIFO_SIWU is on the wrong pin.
2020-08-23 software: Add attribute warn_unused_result, and fix related bugs.
    [bringup_ftdi.c]
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2020-08-23 software: Improve error message for default mode.
    [ftdiutil.c]
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2020-09-04 doc: Add button mistake.
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
